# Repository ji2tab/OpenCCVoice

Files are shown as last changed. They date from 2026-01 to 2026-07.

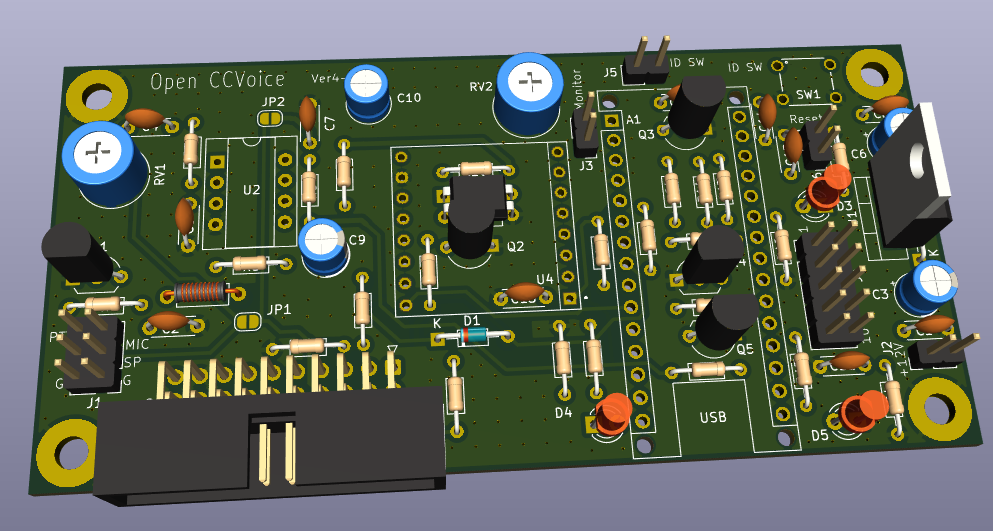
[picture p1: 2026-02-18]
DMR Arduino ID V4-2/完成予定画像Ver4-3.png

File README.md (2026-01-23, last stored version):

# OpenCCVoice Project

[日本語 (Japanese)](#openccvoice-について) | [English](#about-openccvoice)

---

## OpenCCVoice について
OpenCCVoice は、**JA2CCV** 局の設計考案を基礎に、複数局の協力により発展してきたプロジェクトです。
このプロジェクトは、技術を共有し、改善し合い、より良いものへ発展させていくことを目的としています。

### 理念：ブラックボックスにしない、共有の精神
OpenCCVoice はアマチュア無線の精神に基づき、以下の理念を掲げています。

> **「誰でも自由に使え、誰でも改良でき、そしてその成果をオープンに共有できる」**

特定の人だけが技術を抱え込む「ブラックボックス化」を避け、多くの局が改善に参加することで、技術の相互発展を促します。
この理念を象徴するものとして**「OpenCCVoice」**という名称が付けられています。

### ライセンスと権利について
公開予定の回路図、Arduino スケッチ、基板データ、関連ドキュメントの著作権は **JA2CCV 局および OpenCCVoice プロジェクト** に帰属します。

OpenCCVoice は、技術共有と発展を目的としたオープンプロジェクトであり、公開物は **オープンソースライセンス（GPL v3 の理念に準拠）** のもとで取り扱われます。

#### 1. 利用と改変について
* どなたでも **自由に利用** できます。
* 必要に応じて **改変・機能追加・組み込み** が可能です。

#### 2. 再配布・派生物公開の条件（コピーレフト）
改変版や派生物を公開・配布する際は、以下の条件を遵守してください。

1.  **原著作者（JA2CCV／OpenCCVoice）を明示すること**
2.  **改変した点を明記すること**
3.  **派生物も同じくオープンな形で公開すること**
    * ブラックボックス化せず、ソースコード・回路図・基板データ等を公開してください。

#### 3. ライセンス文書について
正式な LICENSE（GPL v3）文書は、回路図・ソフトウェア・基板データ公開時に同梱されます。

OpenCCVoice が多くの局とともに発展していくことを願っています。

### 免責事項 (Disclaimer)
本プロジェクトで公開されているハードウェア設計（回路図・基板データ）、ソフトウェア（ソースコード）、および関連ドキュメントの利用にあたっては、以下の事項をあらかじめご了承ください。

1.  **無保証（No Warranty）**
    本成果物は「現状のまま（As Is）」で提供されます。製作者およびOpenCCVoiceプロジェクトは、特定の目的への適合性、動作の確実性、およびバグや不具合がないことを保証しません。
2.  **損害に対する非責任**
    本成果物の使用、または使用不能によって生じた、いかなる損害（無線機・PC等のハードウェア故障、データの消失、火災、怪我など）についても、製作者およびプロジェクトメンバーは一切の責任を負いません。自作機器の接続は、ご自身の無線機を破損させるリスクがあることを理解した上で行ってください。
3.  **法令の遵守（Legal Compliance）**
    本装置を使用して無線局を運用する場合、利用者は各国の電波法および関連法規（日本国内においては電波法、無線局運用規則など）を遵守する責任を負います。
    * 送信間隔、送出内容、変調レベルなどが法的基準を満たしているか、利用者の責任において確認・調整してください。
    * 本装置の使用による法令違反について、製作者は一切関知しません。
4.  **ライセンス**
    本プロジェクトは **GPL v3 (GNU General Public License v3)** の下で公開されています。再配布や改変に関する条件はライセンス条項に従ってください。

---

## About OpenCCVoice
The OpenCCVoice project is based on the design and concept by **JA2CCV**, and has been developed through the cooperation of multiple stations.
The goal of this project is to share technology, improve upon it together, and foster further development.

### Philosophy: No Black Box, Spirit of Sharing
Based on the spirit of Amateur Radio, OpenCCVoice upholds the following philosophy:

> **"Free to use, free to improve, and results are shared openly."**

We aim to avoid "black boxing"—where technology is hoarded by a few—and instead encourage mutual technological advancement by allowing many stations to participate in improvements.
The name **"OpenCCVoice"** was chosen to symbolize this philosophy.

### License and Rights
The copyright of the schematics, Arduino sketches, PCB data, and related documentation belongs to **JA2CCV and the OpenCCVoice Project**.

OpenCCVoice is an open project aimed at technology sharing and development. All published materials are handled under **Open Source Licenses (compliant with GPL v3 principles)**.

#### 1. Usage and Modification
* Anyone is **free to use** this project.
* You may **modify, add features, or integrate** it as needed.

#### 2. Conditions for Redistribution (Copyleft)
When publishing or distributing modified versions or derivatives, you must observe the following conditions:

1.  **Credit the original authors (JA2CCV / OpenCCVoice).**
2.  **Clearly state the modifications made.**
3.  **Release the derivative works under the same open terms.**
    * Do not "black box" the project; you must publish the source code, schematics, and PCB data.

#### 3. About License Documents
The official LICENSE (GPL v3) document will be included with the release of schematics, software, and PCB data.

We hope that OpenCCVoice will continue to grow together with many stations.

### Disclaimer
Please read the following terms carefully before using the hardware designs (schematics, PCB data), software (source code), and documentation provided by the OpenCCVoice project.

1.  **No Warranty**
    This project is provided "AS IS", without warranty of any kind, express or implied, including but not limited to the warranties of merchantability or fitness for a particular purpose. The entire risk as to the quality and performance of the project is with you.
2.  **Limitation of Liability**
    In no event shall the authors or copyright holders be liable for any claim, damages, or other liability, whether in an action of contract, tort, or otherwise, arising from, out of, or in connection with the software/hardware or the use or other dealings in the project.
    * **Hardware Risk:** Connecting custom circuits to your radio equipment carries inherent risks. You assume full responsibility for any damage to your transceiver, computer, or other devices.
3.  **Regulatory Compliance**
    Users are solely responsible for complying with the radio laws and regulations of their respective countries or regions.
    * It is the user's responsibility to ensure that transmission intervals, audio levels, and operation methods comply with local legal requirements.
    * The authors assume no responsibility for any legal violations committed by the user.
4.  **License**
    This project is released under the **GNU General Public License v3 (GPL v3)**. Please refer to the license for terms regarding redistribution and modification.

---
**Project Contributors:** JA2CCV, JA9HYM, JA2DML, JG1XWV, JI2TAB

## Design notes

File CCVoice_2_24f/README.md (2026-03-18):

# OpenCCVoice Guidance Controller

**バージョン: v2.24f**
対象基板: **Ver.5**
対象MCU: Arduino Nano (ATmega328P, 5V)

---

## 概要

OpenCCVoice は DMR 無線機のレピータ向け ID 送出支援コントローラです。
DFPlayer Mini による音声ファイル再生、DS3231 RTC による正時アライン、
AT24C32 による設定の二重保存・イベントログ記録に対応しています。

---

## ファイル構成

```
CCVoice_2_24f/
  ├── CCVoice_2_24f.ino    メインスケッチ（必須）
  ├── ccvoice_log.h       イベントログ関連（必須）
  └── ccvoice_config.h    設定マイグレーション関連（必須）
```

> **3ファイルを同一フォルダに置いて** Arduino IDE で `CCVoice_2_24f.ino` を開いてください。

---

## Ver.5 ピンマップ

| Pin | 機能 | 備考 |
|-----|---|---|
| D2  | テストSW | 1〜3クリックで TRACK 1〜3 手動送出 |
| D3  | DFP BUSYミラー出力 | 再生中=HIGH（反転） |
| D4  | ModBusy LED | BUSY 表示 |
| D5  | PTT 出力 | HIGH=送信 |
| D6  | 抑止 LED | 抑止/バースト/POST-TX 表示 |
| D7  | A0検知 LED | A0 BUSY 表示 |
| D10 | DFPlayer BUSY 入力 | LOW=再生中（INPUT_PULLUP） |
| D11 | TM BUSY 入力 | 極性切替可（g0/g1）、INPUT_PULLUP |
| D12 | Arduino RX ← DFPlayer TX | SoftwareSerial 9600bps |
| D13 | Arduino TX → DFPlayer RX | SoftwareSerial 9600bps |
| A0  | アナログ入力 | ヒステリシス＋保持適用 |
| A4  | I²C SDA | DS3231 + AT24C32 |
| A5  | I²C SCL | DS3231 + AT24C32 |

---

## コマンド一覧（シリアル 115200bps 8N1 / 改行なし or LF）

| コマンド | 説明 | 既定値 |
|---|---|---|
| `m0/m1/m2` | BUSY検知ソース: Digital/A0/AUTO | AUTO |
| `n####` | BUSY最小時間 (ms) | 500 |
| `b####` | BUSY最大時間（長話抑止）(ms) | 3900 |
| `i####` | IDLE最小時間 (ms) | 200 |
| `s0/s1` | 抑止機能 OFF/ON | ON |
| `t0/t1` | 送信後抑止 OFF/ON | ON |
| `r####` | 送信後抑止時間 (ms) | 3000 |
| `p##` | 定周期送出間隔（分、0=停止） | 30 |
| `k####` | 周期ID静寂ガード (ms) | 2000 |
| `L###` | A0低閾値 | 300 |
| `G###` | A0高閾値 | 700 |
| `a####` | A0保持時間 (ms) | 800 |
| `w##` | AUTO判定ウィンドウ（分） | 30 |
| `d####` | DFPlayer タイムアウト (ms、0=無効) | 20000 |
| `g0/g1` | TM BUSY 極性: LOW/HIGH | HIGH |
| `u0/u1` | RTCアライン OFF/ON | ON |
| `TYYYYMMDDHHmmss` | RTC時刻設定（例: T20260311143000） | — |
| `v` | イベントログ表示（直近20件） | — |
| `v0` | イベントログ消去 | — |
| `V` | バージョン表示（スケッチver + EEPROM_VER） | — |
| `Z` | ソフトウェアリセット（WDT、EEPROM変更なし） | — |
| `q` | 現在設定・時刻の一覧表示 | — |
| `h` | ヘルプ表示 | — |
| `H` | 詳細ヘルプ表示 | — |
| `x` | STOP（送出停止） | — |
| `R` | STOP解除（送出再開） | — |
| `F` | Factory Reset（EEPROM初期化） | — |
| `0〜3` | テスト送出（TRACK 0〜3） | — |

---

## 起動時シリアル出力例

```
[START] OpenCCVoice v2.24f (Event Log, Dual EEPROM, RTC-Aligned Periodic, Ver.5 pinmap)
[RTC] DS3231 found.
[EEPROM] AT24C32 found. Using external EEPROM.
[CFG] EEPROM_VER=6 SRC=AUTO MIN=500 MAX=3900 PER(min)=30 RTC_ALIGN=ON
[RTC] 2026/03/12 09:00:00  Align=ON(RTC)
```

---

## 音声ファイル

詳細は `AUDIO_FILES_GUIDE.md` を参照してください。

| トラック | ファイル名 | 用途 |
|---|---|---|
| 1 | `001.mp3` | カーチャンク ID |
| 2 | `002.mp3` | 定周期 ID（奇数回） |
| 3 | `003.mp3` | 定周期 ID（偶数回） |

> **001〜003 の3ファイルを必ず用意してください。**
> 詳細は `AUDIO_FILES_GUIDE.md` を参照。

---

## DS3231 接続

詳細は `DS3231_CONNECTION_GUIDE.md` を参照してください。

- J5 コネクタ（SDA/SCL/VCC/GND）に接続
- I²C アドレス: DS3231=0x68、AT24C32=0x57
- 未接続時は millis() 相対動作にフォールバック

> DS3231 のコイン電池（CR2032）が切れると時刻が `2000/01/01` 付近にリセットされます。
> `q` コマンドで確認し、`T` コマンドで再設定してください。

---

## 関連ドキュメント

| ファイル | 内容 |
|---|---|
| `CHANGELOG.md` | バージョン変更履歴 |
| `NOTES_FOR_UPGRADE.md` | アップグレード手順 |
| `SPECIFICATION.md` | 詳細仕様書 |
| `DS3231_CONNECTION_GUIDE.md` | DS3231 接続ガイド |
| `AUDIO_FILES_GUIDE.md` | 音声ファイルガイド |
| `README_PROJECT.md` | プロジェクト概要・ライセンス |
| `Schematic_Ver5.pdf` | 回路図（Ver.5） |
| `PCB_Layout_Ver5.pdf` | 部品配置図（Ver.5） |

---

**Project Contributors:** JA2CCV, JA9HYM, JA2DML, JG1XWV, JI2TAB

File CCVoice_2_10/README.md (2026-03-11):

# OpenCCVoice Guidance Controller

取扱説明書 / コマンドリファレンス  
**バージョン: v2.10 — DS3231 RTC 正時アライン対応版**  
**最終更新日: 2026/03/11**  
対象ハード: Arduino Nano (ATmega328P / 5V) **基板 Ver.5**  
通信設定: 115200 bps / 8N1 / 改行なし（またはLF）

---

## ■ 概要

本機は DMR 無線機の ID 送出を自動制御するコントローラです。  
PC と USB 接続し、シリアルモニタから各種コマンドで設定を変更できます。

全ての設定は EEPROM に自動保存され、電源断でも保持されます。  
**v2.10 は DS3231 RTC モジュールに対応し、周期IDを毎正時アライン方式で送出できます。**

---

## ■ v2.10 の特徴・変更点

### 【DS3231 RTC モジュール対応】

基板上の **J5 コネクタ**（SDA/SCL/VCC/GND）に DS3231+AT24C32 一体型モジュールを接続するだけで動作します。

- **未接続・故障時は自動的に millis() 相対動作へフォールバック**（v2.01 互換）
- 起動時に接続確認ログを表示

### 【正時アライン周期ID】

`p##` の値が **60の約数**（10/15/20/30 など）かつ DS3231 接続時、  
**毎正時を基準とした等間隔タイミング**で周期IDを送出します。

| 設定 | 送出タイミング |
|---|---|
| `p10` | 毎時 :00/:10/:20/:30/:40/:50 |
| `p15` | 毎時 :00/:15/:30/:45 |
| `p30` | 毎時 :00/:30 |
| `p60` | 毎時 :00 |

60の約数でない値（例：`p7`）は従来の millis() 相対動作になります。

1分ごとに DS3231 から時刻を再取得し、長期ドリフトを自動補正します。

### 【新コマンド】

| コマンド | 説明 |
|---|---|
| `TYYYYMMDDHHmmss` | RTC 時刻設定（例：`T20260311143000`） |
| `u1` | RTCアライン有効（既定） |
| `u0` | RTCアライン無効（millis() 相対に切替） |

### 【`q` に RTC 時刻表示を追加】

```
[RTC] 2026/03/11 14:23:45  Align=ON(RTC)
[CFG] EEPROM_VER=5 SRC=DIGITAL(LOCK) MIN=500 MAX=3900 PER(min)=15 ...
```

### 【EEPROM バージョン更新（ver=5）】

v2.01（ver=4）からの更新時、既存設定を引き継いで自動マイグレーションします。

### 【v2.01 の全機能を継承】
- 送信直後ガード（postTxIgnore）
- 周期ID catch-up 対策
- 抑止中も A0 BUSY 観測継続
- 周期ID 静寂ガード（`k####`）
- DFPlayer フェイルセーフ（`d####`）
- TM BUSY 極性切替（`g0/g1`）
- AUTO 判定（`m2`）

---

## ■ ハードウェア接続

### DS3231 モジュールの接続（J5コネクタ）

| DS3231 モジュール | J5 ピン | Arduino Nano |
|---|---|---|
| SLC (SCL) | 1 | A5 |
| SDA | 2 | A4 |
| VCC | 3 | +5V |
| GND | 4 | GND |

> PTT（D5）、ModBusy LED（D4）、A0（A0）等は変更なし。  
> 詳細は回路図（Schematic_Ver5.pdf）および部品配置図（PCB_Layout_Ver5.pdf）を参照。

### ピンマップ（Ver.5 基板）

| ピン | 機能 | 方向 |
|---|---|---|
| D2 | テストSW | 入力（INPUT_PULLUP） |
| D3 | DFP BUSYミラー出力（再生中=HIGH） | 出力 |
| D4 | ModBusy LED | 出力 |
| D5 | PTT（HIGH=送信） | 出力 |
| D6 | 抑止 LED | 出力 |
| D7 | A0検知 LED | 出力 |
| D10 | DFPlayer BUSY入力（LOW=再生中） | 入力（INPUT_PULLUP） |
| D11 | TM BUSY入力（Digital入力） | 入力（INPUT_PULLUP） |
| D12 | Arduino TX → DFPlayer RX | SoftwareSerial |
| D13 | Arduino RX ← DFPlayer TX | SoftwareSerial |
| A0 | アナログBUSY入力 | 入力 |
| A4 | I²C SDA（DS3231） | I²C |
| A5 | I²C SCL（DS3231） | I²C |

---

## ■ クイック・コマンド一覧

| コマンド | パラメータ | 既定値 | 説明 |
|---|---|---|---|
| `m` | 0/1/2 | 0 | DIGITAL固定 / A0固定 / AUTO判定 |
| `b` | 500〜 | 3900 | 最大受信長 (ms) |
| `n` | 100〜 | 500 | 最小受信長 (ms) |
| `i` | 0〜 | 200 | 直前アイドル時間 (ms) |
| `s` | 0/1 | 1 | 抑止 ON/OFF |
| `t` | 0/1 | 1 | 送信後無視 ON/OFF（s1時） |
| `r` | 0〜 | 3000 | 送信後無視時間 (ms) |
| `p` | 0〜 | 30 | 周期ID（分）※0=停止、60の約数→正時アライン |
| `k` | 0〜600000 | 2000 | 周期ID静寂時間 (ms) |
| `w` | 1〜 | 30 | AUTO観測時間（分） |
| `L` | 0〜1023 | 300 | A0閾値LOW |
| `G` | 0〜1023 | 700 | A0閾値HIGH |
| `a` | 0〜 | 800 | A0保持時間 (ms) |
| `d` | 0〜 | 20000 | DFPフェイルセーフ (ms) ※0=無効 |
| `g` | 0/1 | 1 | TM BUSY極性（LOW/HIGH=busy） |
| `u` | 0/1 | 1 | RTCアライン OFF/ON |
| `T` | YYYYMMDDHHmmss | — | RTC時刻設定（例：T20260311143000） |
| `q` | — | — | 設定一覧＋現在RTC時刻 |
| `H` | — | — | 汎用プリセット（s0/t0/b3900） |
| `x` | — | — | Safe Stop（全機能停止） |
| `R` | — | — | 停止状態から復帰（**大文字**） |
| `F` | — | — | Factory Reset（EEPROM初期化） |
| `0〜3` | — | — | ログレベル |
| `h` | — | — | コマンド一覧 |

---

## ■ 初回セットアップ手順（v2.10）

```
1. Ver.5 基板に v2.10 を書き込む
2. J5 コネクタに DS3231 モジュールを接続
3. シリアルモニタ（115200bps）を開く
4. 起動ログで [RTC] DS3231 found. を確認
5. T20260311143000 → 現在時刻を設定（14桁）
6. p15（または p10/p30）で周期を設定
7. q で確認 → Align=ON(RTC) が出れば正時アライン動作中
8. TM BUSY 極性を確認（g0/g1）
9. テストSW（D2）1クリック → Track 1 再生確認
```

---

## ■ v2.01 からのアップグレード

### EEPROM の互換性

v2.10 の EEPROM レイアウト（ver=5）は v2.01（ver=4）から **`rtcAlignOn` フィールドを追加**しています。  
書き込み後の初回起動時に自動マイグレーションが行われ、既存設定はすべて引き継がれます。

- `F`（初期化）は**不要**です。
- 起動ログに `[EEPROM] Settings Loaded.` が出れば正常です。

### コマンドの変更

v2.01 から v2.10 への**コマンド変更はありません**。新コマンド（`T` / `u0/u1`）が追加されたのみです。

---

## ■ DS3231 について

DS3231 は高精度 RTC（リアルタイムクロック）チップです。コイン電池（CR2032）でバックアップされ、電源断中も時刻を保持し続けます。**時刻の自動取得機能はない**ため、初回および電池交換後に `T` コマンドで時刻を設定する必要があります。

AT24C32（モジュール上の外部 EEPROM）は本バージョンでは未使用です。

---

## ■ LED 表示の意味

| LED | ピン | 点灯条件 |
|-----|---|---|
| ModBusy LED | D4 | BUSY 受信中（readBusy()=true） |
| 抑止 LED | D6 | 抑止中（長話/バースト/POST-TX） |
| A0検知 LED | D7 | A0 BUSY 検知中 |
| DFP BUSYミラー | D3 | DFPlayer 再生中（HIGH） |

---

## ■ フェイルセーフ（DFPlayer BUSY 異常）

DFPlayer BUSY が戻らない場合、**d#### ms 経過後に強制 PTT OFF**。

- 既定：d20000（20秒）
- d0：無効

---

## ■ トラブルシューティング

**● IDが出ない**
- 停止中（x）→ `R`（大文字）で復帰
- 長話（b3900超）→ 抑止中
- D6 LED 点灯中（抑止）では動作しない

**● 周期IDが正時にずれる**
- `q` で `Align=ON(RTC)` が出ているか確認
- DS3231 未接続の場合 `Align=OFF(millis)` になる
- `T` コマンドで時刻を再設定

**● DS3231 が認識されない**
- J5 コネクタの SDA/SCL/VCC/GND の配線を確認
- `q` で `N/A(no RTC)` が出る場合は未接続または故障

**● STOP 後に復帰できない**
- `R`（大文字）を入力。`r`（小文字）では復帰しない。

**● BUSY判定が逆**
- g0/g1 の設定確認（`q` で現在の極性を表示）

---

## ■ 配線メモ（v2.10 / Ver.5 基板）

```
DFPlayer TX → D13（Arduino RX）
DFPlayer RX ← D12（Arduino TX）
DFPlayer BUSY（LOW=再生中）→ D10
D10 BUSYミラー（反転）→ D3
TM BUSY → D11（g0/g1 で極性指定）
PTT → D5（HIGH=送信）
ModBusy LED → D4
抑止 LED → D6
A0検知 LED → D7
テストSW → D2（INPUT_PULLUP）
アナログBUSY → A0
DS3231 SDA → A4
DS3231 SCL → A5
```

---

## ■ 重要仕様（抜粋）

**【RESUME コマンド】**  
STOP 中の復帰は **`R`（大文字）** です。`r`（小文字）は送信後抑止時間設定コマンドです。

**【周期ID 正時アライン（p## / u0/u1）】**  
DS3231 接続かつ `p##` が60の約数のとき、毎正時基準で等間隔送出。  
1分ごとにドリフト補正。`q` で `Align=ON(RTC)` / `Align=OFF(millis)` を確認可能。

**【周期ID 静寂ガード（k####）】**  
BUSY OFF → k#### ms 静寂で周期ID 許可。BUSY中・静寂不足・抑止期間中は延期。

**【EEPROM バージョン（CONFIG_VERSION=5）】**  
v2.01（ver=4）からの更新時、自動マイグレーションが働き設定を引き継ぎます。

---

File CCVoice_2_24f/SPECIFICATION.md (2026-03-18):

**===== 仕様書（技術者向け） OpenCCVoice Guidance Controller v2.24f =====**

1. 基本情報
- 名称      : OpenCCVoice Guidance Controller
- バージョン : v2.24f — V/Z コマンド追加版
- MCU       : Arduino Nano（ATmega328P, 5V）
- 対象基板  : Ver.5
- 依存      : Arduino.h / SoftwareSerial.h / EEPROM.h / Wire.h / avr/wdt.h
- DFPlayer  : BUSY監視（D10=LOW 再生中）、9600bps 制御（SoftwareSerial D12/D13）
- DS3231    : I²C（A4=SDA, A5=SCL）、レジスタ直接アクセス（外部ライブラリ不要）
- EEPROM    : CONFIG_VERSION=6（v2.10=5 から saveTimestamp フィールドを追加）
               → v2.10 / v2.01 設定を引き継ぎ可能
- AT24C32   : 外部EEPROM（I²C 0x57）/ 内蔵EEPROMと二重保存（v2.20追加）

**===== 2. ピンアサイン（Ver.5） =====**

 Pin  | 定数名              | 方向   | 信号                          | 備考
------|---------------------|--------|-------------------------------|----------------------------
 D2   | PIN_TEST_SW         | 入力   | テストSW                      | INPUT_PULLUP、LOW=押下
 D3   | PIN_DFP_OUT         | 出力   | DFPlayer BUSYミラー           | 再生中=HIGH（反転出力）
 D4   | PIN_BUSY_LED        | 出力   | ModBusy LED                   | HIGH=点灯
 D5   | PIN_PTT             | 出力   | PTT                           | HIGH=送信
 D6   | PIN_SUP_LED         | 出力   | 抑止 LED                      | HIGH=点灯（抑止中）
 D7   | PIN_A0_LED          | 出力   | A0検知 LED                    | HIGH=点灯（a0Busy時）
 D10  | PIN_DFP_BSY         | 入力   | DFPlayer BUSY入力             | INPUT_PULLUP、LOW=再生中
 D11  | PIN_TM_BUSY         | 入力   | TM BUSY入力（Digital入力）    | INPUT_PULLUP、極性g0/g1
 D13  | ARD_TX_TO_DFP       | 出力   | Arduino TX → DFPlayer RX     | SoftwareSerial 9600bps ★v2.23修正
 D12  | ARD_RX_FROM_DFP     | 入力   | Arduino RX ← DFPlayer TX     | SoftwareSerial 9600bps ★v2.23修正
 A0   | A0_PIN              | 入力   | アナログBUSY                  | 0〜1023、ヒステリシス＋保持
 A4   | —（Wire固定）        | I²C    | DS3231 SDA                    | Wire.h使用（v2.10追加）
 A5   | —（Wire固定）        | I²C    | DS3231 SCL                    | Wire.h使用（v2.10追加）

**===== 3. 機能仕様（Functional） =====**

(1) 短発受信の自動ID送出（v2.01から変更なし）
  - TM BUSY（D11）または A0 の受信継続時間 dur が
      BUSY_MIN_MS ≤ dur < BUSY_MAX_MS のとき、Track 1（001）を送出。
  - PTT シーケンス：PRE=1000ms → 再生 → POST=1000ms。

(2) 抑止（長話・バースト・送信後）（v2.01から変更なし）
  - 長話抑止      : dur ≥ BUSY_MAX_MS → LONG_SUP_MS=10s
  - バースト抑止  : 10秒窓内で短発が2回以上 → BURST_SUP_MS=10s
  - 送信後抑止    : t1有効時、TX後 TX_SUP_MS(ms) の受信を無視
  - 送信直後ガード: PTT OFF 直後、BUSYが idleMin 連続OFF まで全発火禁止

(3) AUTO（m2）（v2.01から変更なし）
  - AUTO_WINDOW（分）観測し、Digital/A0 の優位側へ自動固定。

(4) 周期ID（v2.10で正時アライン機能を追加）
  【RTCアライン動作（DS3231接続 かつ p## が60の約数 かつ u1）】
  - PERIOD_MS ごとに Track 2/3 を交互送出。
  - 次回発火時刻 = 「現在時刻から次の正時アライン境界まで」を DS3231 から計算。
  - 発火後、即座に次回時刻を再計算（recalcPeriodicAlign）。
  - 1分ごとに DS3231 から時刻を再取得してドリフト補正（RTC_RESYNC_INTERVAL=60s）。
  - 送出条件（全て満たすこと）：
    1) periodicDue=true（nextPeriodicAt を超過）
    2) state==IDLE
    3) readBusy()==false
    4) BUSY が OFFになってから periodQuietMs(ms) 以上静寂
    5) 抑止中でない（長話/バースト/送信後ガード）
  - BUSY中・静寂不足・抑止期間中は送出せず延期（periodicDue 保持）。

  【millis()相対動作（DS3231未接続 / 60の約数でない / u0）】
  - v2.01 互換の catch-up 方式。
  - nextPeriodicAt += PERIOD_MS で追い付かせ、最大1回分のみ発火。

  【切替判定ロジック】
  - isAlignablePeriod(pMin): 60 % pMin == 0 かつ 0 < pMin ≤ 60 → true
  - rtcAvailable && RTC_ALIGN_ON && isAlignablePeriod → rtcAlignActive=true

(5) DS3231 RTC 管理（v2.10新規）
  - Wire.h を使用、外部ライブラリ不要。
  - 起動時に rtcProbe() で I²C 疎通確認（アドレス 0x68）。
  - rtcRead()  : 7バイト読み取り、BCD→DEC変換、RtcTime 構造体に格納。
  - rtcWrite() : RtcTime 構造体からBCD変換して書き込み。
  - DS3231 未応答時は rtcAvailable=false → millis() 相対にフォールバック。

(6) EEPROM 永続化（v2.10で rtcAlignOn を追加）
  - 変更コマンド（m/n/b/i/p/r/L/G/a/w/s/t/d/g/k/u）で即保存。
  - CONFIG_VERSION=5 / v2.01（ver=4）から自動マイグレーション。

(7) LED表示 / D3ミラー出力（v2.01から変更なし）

(8) フェイルセーフ（PTT張り付き防止）（v2.01から変更なし）

(9) テストSW（D2）（v2.01から変更なし）
  - 1〜3クリック → Track 1〜3 再生

**===== 4. 非機能仕様（Non-Functional） =====**
（v2.01から変更なし）
- 応答性 : TM BUSY デバウンス 5ms
- 安定性 : DFPlayer BUSY の HIGH確定に 40ms
- ガード : PTT 最低 ON ガード搭載
- 可搬性 : Arduino IDE 1.8.x / 2.x
- 保守性 : printSummary() による状態一覧（RTC時刻・アライン状態含む）
- 安全性 : DFPlayer タイムアウト監視 / PTT張り付き防止
- 耐久性 : EEPROM 書込みは「値変更時のみ」

**===== 5. インタフェース仕様（I/O 詳細） =====**

【入力】
- D2  (INPUT_PULLUP) : テストSW。LOW=押下。
- D10 (INPUT_PULLUP) : DFPlayer BUSY。LOW=再生中。
- D11 (INPUT_PULLUP) : TM BUSY。g0: LOW=busy / g1: HIGH=busy（既定）。
- A0                 : アナログBUSY（0〜1023 / 基準VCC=5V）。
- A4                 : I²C SDA（DS3231）。Wire.h が管理。
- A5                 : I²C SCL（DS3231）。Wire.h が管理。

【出力】
- D3  : DFPlayer BUSY ミラー（反転）。再生中=HIGH。
- D4  : ModBusy LED。
- D5  : PTT。送信中 HIGH。
- D6  : 抑止 LED。
- D7  : A0検知 LED。

【SoftwareSerial（DFPlayer通信）】
- D12 (TX) / D13 (RX) : 9600bps TTLレベル（5V）。

**===== 6. 既定値（Factory Defaults） =====**
（v2.01から変更なし、rtcAlignOn=1 を追加）
- BUSY_INPUT_SOURCE           = DIGITAL（D11）
- BUSY_MIN_MS                 = 500
- BUSY_MAX_MS                 = 3900
- IDLE_MIN_MS                 = 200
- PERIOD_MS                   = 30 min
- TX_SUP_MS                   = 3000
- SUPPRESSORS_ENABLED         = true
- TX_AFTER_SUPPRESS_ENABLED   = true
- A0_LOW_TH                   = 300
- A0_HIGH_TH                  = 700
- A0_HOLD                     = 800
- AUTO_WINDOW                 = 30 min
- DFP_TIMEOUT_MS              = 20000ms
- TM_BUSY_ACTIVE_HIGH         = true（HIGH=busy）
- periodQuietMs               = 2000ms
- RTC_ALIGN_ON                = true（ON）
- EEPROM_VER                  = 6（CONFIG_VERSION=6）

**===== 7. コマンド仕様（完全） =====**
- m0 / m1 / m2         … BUSYソース切替（DIGITAL / A0 / AUTO）
- n####                … 最小受信長（ms）
- b####                … 最大受信長（ms）
- i####                … 直前アイドル時間（ms）
- s0 / s1              … 抑止 OFF / ON
- t0 / t1              … 送信後抑止 OFF / ON
- r####                … TX後無視時間（ms）
- p##                  … 周期ID（分 / 0=停止）※60の約数→正時アライン
- k####                … 周期ID静寂時間（ms）
- w##                  … AUTO観測窓（分）
- L### / G### / a####  … A0 閾値LOW/HIGH/保持(ms)
- d####                … DFPlayerタイムアウト（ms / 0=無効）
- g0 / g1              … TM BUSY極性（LOW=busy / HIGH=busy）
- u0 / u1              … RTCアライン OFF / ON（v2.10追加）
- v                    … ログ表示（直近20件）（v2.21追加）
- v0                   … ログ消去（v2.21追加）
- V                    … バージョン表示（スケッチver + EEPROM_VER）（v2.24f追加）
- Z                    … ソフトウェアリセット（WDT 15ms / EEPROM変更なし）（v2.24f追加）
- TYYYYMMDDHHmmss      … RTC時刻設定（v2.10追加）例: T20260311143000
- q                    … 要約（RTC時刻・アライン状態含む）
- H                    … 汎用プリセット（s0/t0/b3900）
- x                    … 停止（Safe Stop）
- R                    … 再開（STOP中のみ有効。大文字）
- F                    … Factory Reset（初期化＋保存）
- 0 / 1 / 2 / 3        … ログレベル（NONE / ERR / INF / DBG）
- h                    … ヘルプ表示

**===== 8. 振る舞い仕様（状態遷移 / BUSY判定） =====**
（v2.01から変更なし。周期IDスケジューラのみ追記）

【周期ID（RTCアライン動作）】
- isAlignablePeriod(pMin) = true かつ rtcAvailable かつ RTC_ALIGN_ON
  → rtcAlignActive=true
- nextPeriodicAt = calcNextAlignedAt(t, pMin, now)
  = now + ((periodSec - totalSec % periodSec) % periodSec) * 1000
  ※ slotSec==0（ちょうど境界）の場合は次の周期に設定
- 発火後: recalcPeriodicAlign(now) で即座に次回時刻を再計算
- 1分ごと: rtcResyncMs 到達で recalcPeriodicAlign(now) を再実行（ドリフト補正）

【周期ID（millis()相対動作）】
- rtcAlignActive=false の場合
- v2.01 互換 catch-up: while(now >= nextPeriodicAt) nextPeriodicAt += PERIOD_MS

**===== 9. EEPROM 仕様 =====**

【レイアウト（CONFIG_VERSION=6 / v2.24f）】

 フィールド名        | 型       | コマンド | 説明
---------------------|----------|----------|-------------------------
 magic               | uint32_t | 自動     | 識別子 0xDEADBEEF
 busySrc             | uint8_t  | m        | 0=DIGITAL, 1=A0, 2=AUTO
 suppressOn          | uint8_t  | s        | 0=OFF, 1=ON
 txAfSupOn           | uint8_t  | t        | 0=OFF, 1=ON
 busyMin             | uint32_t | n        | ms
 busyMax             | uint32_t | b        | ms
 idleMin             | uint32_t | i        | ms
 periodMin           | uint32_t | p        | 分
 txSupMs             | uint32_t | r        | ms
 a0Low               | int      | L        | 0〜1023
 a0High              | int      | G        | 0〜1023
 a0Hold              | uint32_t | a        | ms
 autoWinMin          | uint32_t | w        | 分
 dfpTimeoutMs        | uint32_t | d        | ms
 tmBusyActiveHigh    | uint8_t  | g        | 0=LOW=busy, 1=HIGH=busy
 periodQuietMs       | uint32_t | k        | ms
 rtcAlignOn          | uint8_t  | u        | 0=OFF, 1=ON（v2.10追加）
 saveTimestamp       | uint32_t | 自動     | 保存時刻（秒換算）v2.20追加
 ver                 | uint8_t  | 自動     | レイアウト版（現在=6）

【バージョン不一致時の自動補完値】
- v2.01→v2.20: rtcAlignOn=1（ON）、saveTimestamp=0
- v2.10→v2.20: saveTimestamp=0

**===== 10. 制約 =====**
- TM BUSY デバウンス 5ms（固定）
- A0 と Digital（D11）の同時配線は禁止
- EEPROM 書込みは「値変更時のみ」（耐久性考慮）
- SRAM：ATmega328P の 2KB 内で動作
- D13 は SoftwareSerial（RX）兼用のため、外部回路との競合に注意
- A4/A5 は Wire.h が占有するため他用途不可
- DS3231 の T コマンドは秒単位の精度（手打ちのため数秒の誤差は許容）
- AT24C32 未接続中に設定変更した場合、次回モジュール接続時に不一致警告が出る
- AT24C32 のページ書き込み完了待ち 10ms（最大5msに対して余裕あり）
- PTT 出力中に Z を実行すると WDT ハードリセットにより PTT が即解放される

**===== 11. 試験（例） =====**
（v2.01の試験項目に加えて以下を追加）

- RTC正時アライン：p15 設定、DS3231接続
  → q で Align=ON(RTC) を確認
  → 毎時 :00/:15/:30/:45 に周期ID 送出確認

- RTCフォールバック：DS3231 未接続で p15
  → q で Align=OFF(millis) を確認
  → millis() 相対で15分ごとに送出

- 時刻設定：T20260311143000
  → q で 2026/03/11 14:30:xx が表示されること

- RTCアライン OFF：u0
  → q で RTC_ALIGN=OFF、Align=OFF(millis) を確認

- EEPROM マイグレーション：v2.01（ver=4）から書き込み
  → 起動ログに Migration done. が出て既存設定を引き継ぐこと
  → q で EEPROM_VER=5 を確認

**===== 12. リスク =====**
（v2.01のリスクに加えて以下を追加）
- DS3231 のコイン電池切れ → 時刻リセット。電池交換後に T コマンドで再設定が必要。
- T コマンドの手打ちによる秒単位の誤差（許容範囲内）
- I²C バス上に AT24C32（0x57）が存在するが、本プログラムはアクセスしないため競合なし
- A4/A5 を他用途に使用している旧設計との非互換

**===== 13. 変更履歴 =====**
- 詳細は CHANGELOG.md を参照

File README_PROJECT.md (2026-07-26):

# OpenCCVoice Project

[日本語 (Japanese)](#openccvoice-について) | [English](#about-openccvoice)

---

## OpenCCVoice について
OpenCCVoice は、**JA2CCV** 局の設計考案を基礎に、複数局の協力により発展してきたプロジェクトです。
このプロジェクトは、技術を共有し、改善し合い、より良いものへ発展させていくことを目的としています。

### 理念：ブラックボックスにしない、共有の精神
OpenCCVoice はアマチュア無線の精神に基づき、以下の理念を掲げています。

> **「誰でも自由に使え、誰でも改良でき、そしてその成果をオープンに共有できる」**

特定の人だけが技術を抱え込む「ブラックボックス化」を避け、多くの局が改善に参加することで、技術の相互発展を促します。
この理念を象徴するものとして**「OpenCCVoice」**という名称が付けられています。

---

## 基板バージョンとファームウェアの対応

> ⚠️ **基板 Ver.4 と Ver.5 ではピンアサインが異なります。**
> **必ず使用する基板バージョンに対応したファームウェア（スケッチ）を使用してください。**

| 基板バージョン | 対応ファームウェア | 状態 |
|---|---|---|
| Ver.4 | v1.73e 以前（**1系**） | 旧バージョン |
| **Ver.5** | **v2.01 以降（2系）** | **現行・推奨** |

### Ver.4 と Ver.5 のピンアサイン比較

| 信号 | Ver.4（1系） | **Ver.5（2系）** |
|---|---|---|
| テストSW | D3 | **D2** |
| DFPlayer BUSYミラー出力 | D2 | **D3** |
| ModBusy LED | D4 | D4（変更なし） |
| PTT出力 | D5 | D5（変更なし） |
| 抑止 LED | D13 | **D6** |
| A0検知 LED | D12 | **D7** |
| DFPlayer BUSY入力 | D7 | **D10** |
| TM BUSY入力（Digital入力） | D6 | **D11** |
| Arduino TX → DFPlayer RX | D11 | **D13** |
| Arduino RX ← DFPlayer TX | D10 | **D12** |
| アナログBUSY | A0 | A0（変更なし） |
| I²C SDA（DS3231/AT24C32） | 未使用 | **A4**（v2.10追加） |
| I²C SCL（DS3231/AT24C32） | 未使用 | **A5**（v2.10追加） |

> **注意:** Ver.5 基板に 1系ファームウェアを書き込むと、ピンアサインの不一致により正常動作しません。逆も同様です。

### ライセンスと権利について
公開予定の回路図、Arduino スケッチ、基板データ、関連ドキュメントの著作権は **JA2CCV 局および OpenCCVoice プロジェクト** に帰属します。

OpenCCVoice は、技術共有と発展を目的としたオープンプロジェクトであり、公開物はファイルの種類に応じて次のライセンスのもとで取り扱われます。**ハードウェア（回路図・基板データ・BOM・ケース）は CERN-OHL-S v2**、**ソフトウェア（Arduino スケッチ）は GPL v3** です。

#### 1. 利用と改変について
* どなたでも **自由に利用** できます。
* 必要に応じて **改変・機能追加・組み込み** が可能です。

#### 2. 再配布・派生物公開の条件（コピーレフト）
改変版や派生物を公開・配布する際は、以下の条件を遵守してください。

1.  **原著作者（JA2CCV／OpenCCVoice）を明示すること**
2.  **改変した点を明記すること**
3.  **派生物も同じくオープンな形で公開すること**
    * ブラックボックス化せず、ソースコード・回路図・基板データ等を公開してください。

#### 3. ライセンス文書について
正式なライセンス文書はリポジトリに同梱されています。ハードウェアは `LICENSE-HARDWARE.txt`（CERN-OHL-S v2）、ソフトウェアは `LICENSE`（GPL v3）を参照してください。

OpenCCVoice が多くの局とともに発展していくことを願っています。

### 免責事項 (Disclaimer)
本プロジェクトで公開されているハードウェア設計（回路図・基板データ）、ソフトウェア（ソースコード）、および関連ドキュメントの利用にあたっては、以下の事項をあらかじめご了承ください。

1.  **無保証（No Warranty）**
    本成果物は「現状のまま（As Is）」で提供されます。製作者およびOpenCCVoiceプロジェクトは、特定の目的への適合性、動作の確実性、およびバグや不具合がないことを保証しません。
2.  **損害に対する非責任**
    本成果物の使用、または使用不能によって生じた、いかなる損害（無線機・PC等のハードウェア故障、データの消失、火災、怪我など）についても、製作者およびプロジェクトメンバーは一切の責任を負いません。自作機器の接続は、ご自身の無線機を破損させるリスクがあることを理解した上で行ってください。
3.  **法令の遵守（Legal Compliance）**
    本装置を使用して無線局を運用する場合、利用者は各国の電波法および関連法規（日本国内においては電波法、無線局運用規則など）を遵守する責任を負います。
    * 送信間隔、送出内容、変調レベルなどが法的基準を満たしているか、利用者の責任において確認・調整してください。
    * 本装置の使用による法令違反について、製作者は一切関知しません。
4.  **ライセンス**
    本プロジェクトのハードウェアは **CERN-OHL-S v2 (CERN Open Hardware Licence Version 2 - Strongly Reciprocal)**、ソフトウェアは **GPL v3 (GNU General Public License v3)** の下で公開されています。再配布や改変に関する条件は、それぞれのライセンス条項に従ってください。

---

## About OpenCCVoice
The OpenCCVoice project is based on the design and concept by **JA2CCV**, and has been developed through the cooperation of multiple stations.
The goal of this project is to share technology, improve upon it together, and foster further development.

### Philosophy: No Black Box, Spirit of Sharing
Based on the spirit of Amateur Radio, OpenCCVoice upholds the following philosophy:

> **"Free to use, free to improve, and results are shared openly."**

We aim to avoid "black boxing"—where technology is hoarded by a few—and instead encourage mutual technological advancement by allowing many stations to participate in improvements.
The name **"OpenCCVoice"** was chosen to symbolize this philosophy.

---

## Board Version and Firmware Compatibility

> ⚠️ **Board Ver.4 and Ver.5 have different pin assignments.**
> **Always use the firmware that matches your board version.**

| Board Version | Compatible Firmware | Status |
|---|---|---|
| Ver.4 | v1.73e or earlier (**1.x series**) | Legacy |
| **Ver.5** | **v2.01 or later (2.x series)** | **Current / Recommended** |

### Pin Assignment Comparison: Ver.4 vs Ver.5

| Signal | Ver.4 (1.x series) | **Ver.5 (2.x series)** |
|---|---|---|
| Test SW | D3 | **D2** |
| DFPlayer BUSY mirror output | D2 | **D3** |
| ModBusy LED | D4 | D4 (unchanged) |
| PTT output | D5 | D5 (unchanged) |
| Suppression LED | D13 | **D6** |
| A0 detect LED | D12 | **D7** |
| DFPlayer BUSY input | D7 | **D10** |
| TM BUSY input (Digital) | D6 | **D11** |
| Arduino TX → DFPlayer RX | D11 | **D13** |
| Arduino RX ← DFPlayer TX | D10 | **D12** |
| Analog BUSY | A0 | A0 (unchanged) |
| I²C SDA (DS3231/AT24C32) | N/A | **A4** (added in v2.10) |
| I²C SCL (DS3231/AT24C32) | N/A | **A5** (added in v2.10) |

> **Warning:** Writing 1.x series firmware to a Ver.5 board will cause malfunction due to pin assignment mismatch. The reverse is also true.

### License and Rights
The copyright of the schematics, Arduino sketches, PCB data, and related documentation belongs to **JA2CCV and the OpenCCVoice Project**.

OpenCCVoice is an open project aimed at technology sharing and development. Published materials are handled under different licenses depending on the file type: **hardware (schematics, PCB data, BOM, case) is licensed under CERN-OHL-S v2**, and **software (Arduino sketches) is licensed under GPL v3**.

#### 1. Usage and Modification
* Anyone is **free to use** this project.
* You may **modify, add features, or integrate** it as needed.

#### 2. Conditions for Redistribution (Copyleft)
When publishing or distributing modified versions or derivatives, you must observe the following conditions:

1.  **Credit the original authors (JA2CCV / OpenCCVoice).**
2.  **Clearly state the modifications made.**
3.  **Release the derivative works under the same open terms.**
    * Do not "black box" the project; you must publish the source code, schematics, and PCB data.

#### 3. About License Documents
The official license documents are included in the repository: see `LICENSE-HARDWARE.txt` (CERN-OHL-S v2) for hardware, and `LICENSE` (GPL v3) for software.

We hope that OpenCCVoice will continue to grow together with many stations.

### Disclaimer
Please read the following terms carefully before using the hardware designs (schematics, PCB data), software (source code), and documentation provided by the OpenCCVoice project.

1.  **No Warranty**
    This project is provided "AS IS", without warranty of any kind, express or implied, including but not limited to the warranties of merchantability or fitness for a particular purpose. The entire risk as to the quality and performance of the project is with you.
2.  **Limitation of Liability**
    In no event shall the authors or copyright holders be liable for any claim, damages, or other liability, whether in an action of contract, tort, or otherwise, arising from, out of, or in connection with the software/hardware or the use or other dealings in the project.
    * **Hardware Risk:** Connecting custom circuits to your radio equipment carries inherent risks. You assume full responsibility for any damage to your transceiver, computer, or other devices.
3.  **Regulatory Compliance**
    Users are solely responsible for complying with the radio laws and regulations of their respective countries or regions.
    * It is the user's responsibility to ensure that transmission intervals, audio levels, and operation methods comply with local legal requirements.
    * The authors assume no responsibility for any legal violations committed by the user.
4.  **License**
    The hardware of this project is released under the **CERN-OHL-S v2 (CERN Open Hardware Licence Version 2 - Strongly Reciprocal)**, and the software under the **GNU General Public License v3 (GPL v3)**. Please refer to each license for terms regarding redistribution and modification.

---
**Project Contributors:** JA2CCV, JA9HYM, JA2DML, JG1XWV, JI2TAB

---

## ライセンス構成 / License Structure

本プロジェクトは、ファイルの種類によって適用されるライセンスが異なります。
This project applies different licenses depending on the type of file.

### ハードウェア / Hardware
回路図、PCB基板データ、BOM（部品表）、ケースデータ
（対象ディレクトリ: `circuit/`, `pcb/`, `bom/`, `case/`）

**CERN Open Hardware Licence Version 2 - Strongly Reciprocal (CERN-OHL-S v2)**
→ `LICENSE-HARDWARE.txt` を参照 / See `LICENSE-HARDWARE.txt`

### ソフトウェア / Software
Arduino スケッチ等のソースコード
（例: `CCVoice_*/`, `old_firmware/`, `DMR Arduino ID V4-2/`）

**GNU General Public License v3.0 (GPL-3.0)**
→ `LICENSE` を参照 / See `LICENSE`

> 上記の記述と本 README 中の他のライセンス記述が矛盾する場合は、本「ライセンス構成」セクションが優先されます。
> > In case of conflict between this section and other license descriptions in this README, this "License Structure" section takes precedence.
> >

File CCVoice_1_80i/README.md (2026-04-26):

# **OpenCCVoice Guidance Controller**

取扱説明書 / コマンドリファレンス  
**バージョン: v1.80i**  
**最終更新日: 2026/03/24**  
対象ハード: Arduino Nano (ATmega328P / 5V)  
通信設定: 115200 bps / 8N1 / 改行なし（または LF）

---

## ■ 概要

本機は DMR無線機のID送出を自動制御するコントローラです。  
PCとUSB接続し、シリアルモニタから各種コマンドで設定を変更できます。

全ての設定は EEPROM に自動保存され、電源断でも保持されます。

**v1.80i** では v1.80h のコード品質改善を行いました。主な変更点は以下のとおりです。

- カーチャンク検出時の `busySupUntil` 二重セットを修正（起点A に一本化）
- ver=3 以前からのマイグレーション時の不定値リスクを修正
- `handleStoppedState()` 内のデッドコードを削除
- コメント内の旧用語・内部開発版番号を修正

EEPROM CONFIG_VERSION は 5 のまま変更なし。v1.80h からの書き込みは EEPROM 操作不要です。

**v1.80h** では v1.73f1 からの大規模な仕様刷新を行いました。主な変更点は以下のとおりです。

- カーチャンク判定の明確化（② MAX デフォルト: 3900ms → 1500ms）
- PTT 先行・後行無音時間（PRE/POST）をコマンドで可変化（`j####` / `J####`）
- 抑止ロジックを一本化（連打抑止BURSTを廃止し、`busySupUntil` のみで管理）
- 定周期IDをスキップ仕様に変更（旧: 延期保持 → 新: 到来時に条件不成立なら破棄）
- PRE/POST 待機を絶対時刻比較に変更（ブロッキングによるスキップバグを修正）
- ログレベルコマンドを `l0/l1/l2/l3` に変更、STOP復帰コマンドを `R`（大文字）に変更

---

## ■ 本バージョン（v1.80i）の主な変更点

### 【仕様番号とコマンド対応】

本バージョンから、コア動作に関わる主要パラメータに仕様番号を付与しています。

| 番号 | 内容 | コマンド | デフォルト |
|---|---|---|---|
| ① | カーチャンク最小受信長 | `n####` | 500ms |
| ② | カーチャンク最大受信長 | `b####` | 1500ms |
| ③ | PTT先行無音時間（PRE） | `j####` | 1000ms |
| ④ | PTT後行無音時間（POST） | `J####` | 1000ms |
| ⑤ | 抑止時間 | `r####` | 10000ms |
| ⑥ | 定周期間隔 | `p##` | 30分 |

### 【抑止ロジックの刷新】

旧来の「長話抑止（longSupUntil）」「連打抑止（burstSupUntil）」「送信直後ガード（postTxIgnore）」を廃止し、⑤抑止（busySupUntil）に一本化しました。

**⑤抑止の起点：**

- **起点A**: ④ POST 終了の瞬間（カーチャンクID送出後、受信中でない場合）
- **起点B**: ② 超え受信（通常会話）の終了の瞬間
- 受信中に POST が終わった場合は起点B が起点A を上書き

### 【定周期IDのスキップ仕様】

受信中・抑止中・PTT中に周期が到来したら、その回をスキップ（破棄）します。
旧仕様の「条件不成立時に periodicDue を保持して延期」から変更されました。

> **注意**: スキップが頻発する場合は `k####` を短くするか、`p##` の周期を見直してください。

### 【PRE/POST バグ修正】

旧実装では `Serial.parseInt()` のブロッキング中に `millis()` が進み、PRE 無音時間がスキップされる場合がありました。`Serial.setTimeout(50)` を `setup()` で一度だけ設定し、PRE/POST 待機を絶対時刻比較（`pttPreEndAt` / `pttPostEndAt`）に変更することで修正しました。

---

## 1. クイック・コマンド一覧

| コマンド | パラメータ | 既定値 | 説明 |
|---|---|---|---|
| `n` | 100〜 | 500 | ① 最小受信長 (ms) |
| `b` | 500〜 | 1500 | ② 最大受信長 (ms) |
| `j` | 100〜 | 1000 | ③ PTT先行無音時間 PRE (ms) |
| `J` | 100〜 | 1000 | ④ PTT後行無音時間 POST (ms) |
| `r` | 0〜 | 10000 | ⑤ 抑止時間 (ms) |
| `p` | 0〜 | 30 | ⑥ 定周期ID（分）※0=停止 |
| `k` | 0〜600000 | 2000 | 定周期送出前の静寂待機時間 (ms) |
| `m` | 0/1/2 | 0 | BUSYソース: D6固定 / A0固定 / AUTO判定 |
| `g` | 0/1 | 1 | BUSY極性: 0=LOW=busy / 1=HIGH=busy |
| `L` | 0〜1023 | 300 | A0閾値LOW |
| `G` | 0〜1023 | 700 | A0閾値HIGH |
| `a` | 0〜 | 800 | A0保持時間 (ms) |
| `w` | 1〜 | 30 | AUTO観測時間（分） |
| `d` | 0〜 | 20000 | DFPフェイルセーフ (ms) ※0=無効 |
| `V` | — | — | バージョン表示（スケッチver + EEPROM_VER） |
| `q` | — | — | 設定一覧（全パラメータ表示） |
| `x` | — | — | Safe Stop（全機能停止） |
| `R` | — | — | Safe Stop からの復帰 |
| `h` | — | — | コマンド一覧 |
| `l0〜l3` | — | — | ログレベル（OFF/MIN/FULL/DBG） |
| `F` | — | — | Factory Reset（EEPROM初期化） |
| `Z` | — | — | ソフトウェアリセット（WDT、EEPROM変更なし） |

---

## 2. コマンド詳細解説

**[m：モード設定]**  
m0 … D6（デジタルBUSY）固定  
m1 … A0（アナログ）固定  
m2 … AUTO（D6/A0 を観測し優位側へ自動固定）  
※ AUTO中は D6/A0 どちらの入力でも ID が出る

**[b / n：① ② カーチャンク検出窓]**

```
dur < n####              → ノイズ扱い（無視）
n#### ≤ dur < b####      → カーチャンク → ID送出
dur ≥ b####              → 通常会話 → ⑤抑止開始（起点B）
```

n#### … dur < n#### はノイズ扱い（デフォルト 500ms）  
b#### … dur ≥ b#### は通常会話と判定（デフォルト 1500ms）

**[j / J：③ ④ PTT 先行・後行無音時間]**  
j#### … PTT ON から DFPlayer 再生開始までの先行無音時間（デフォルト 1000ms）  
J#### … DFPlayer 再生完了から PTT OFF までの後行無音時間（デフォルト 1000ms）  
どちらも EEPROM に保存される

**[r：⑤ 抑止時間]**  
r#### … 抑止が発動してからの抑止継続時間（ms）  
r0 … 実質的な抑止無効（送信後抑止を無くしたい場合）  
デフォルト 10000ms（10秒）

**[p / k：⑥ 定周期ID]**  
p## … ##分ごとにトラック002/003を交互送出。p0 で停止。  
k#### … 定周期IDを送出する前に「BUSY OFFからの静寂期間（ms）」を要求する静寂ガード。  
　　　　条件不成立の場合はその回をスキップ（破棄）。

- 例：k2000 → BUSY 終了後 2秒静かなら送出（デフォルト）
- 例：k5000 → より強い割り込み防止
- k0 → 静寂ガード無効

**[w：AUTO観測期間]**  
AUTO_WINDOW 分観測 → 優位側へ固定（D13 高速点滅で通知）

**[L / G / a：A0アナログ判定パラメータ]**  
L### … この値を下回ったとき BUSY 開始と判定（デフォルト 300）  
G### … この値を上回ったとき BUSY 終了と判定（デフォルト 700）  
a#### … BUSY 終了判定後も a#### ms は BUSY 状態を保持（スケルチテール対策）（デフォルト 800ms）

**[d：DFPlayer フェイルセーフ]**  
DFPlayer BUSY が戻らない場合、d#### ms 経過で強制 PTT OFF。d0 で無効化。

**[g：BUSY 極性]**  
g0 = LOW=受信（アクティブLOW）  
g1 = HIGH=受信（アクティブHIGH）（既定）

**[x / R：停止と再開]**  
x … 全動作停止（Safe Stop）  
R … 停止中の復帰（STOP中のみ有効）

**[F：Factory Reset]**  
全設定を初期値に戻し EEPROM 保存。MCU は動き続ける。

**[V：バージョン確認]**  
出力例：`[VER] OpenCCVoice v1.80i (EEPROM_VER=5)`

**[Z：ソフトウェアリセット]**  
ウォッチドッグタイマー（15ms）で MCU を再起動。EEPROM は変更しない。  
`F` の後に `Z` を実行すると完全クリーン起動になる。

| 操作 | EEPROM | MCU | 用途 |
|---|---|-----|---|
| `F` のみ | 初期値で上書き | 動き続ける | 設定のみリセット |
| `Z` のみ | 変化なし | 再起動 | 設定保持のまま再起動 |
| `F` → `Z` | 初期値で上書き | 再起動 | 完全クリーン起動 |

**[l0〜l3：ログレベル]**  
l0=OFF / l1=MIN（起動時デフォルト）/ l2=FULL / l3=DBG  
EEPROM には保存されない。起動時は常に l1=MIN。

**[h：ヘルプ]**  
コマンド一覧をシリアル出力する。

---

## 3. 設定値解説（目的・実態・調整指針）

### 【m：BUSYソース選択】

無線機のBUSY信号をどのピンで受けるかを選ぶ。

- `m0`（D6）：デジタル入力。無線機のBUSY出力を直接接続する場合。
- `m1`（A0）：アナログ入力。スケルチ電圧等をヒステリシス判定で検出する場合。
- `m2`（AUTO）：起動後 `w##` 分間、D6エッジ数とA0イベント数を比較し、反応の多い側へ自動固定。固定後はEEPROMへ保存され再起動後も維持される。

固定配線が済んでいる場合は `m0` か `m1` を明示的に指定しておくのが安全。`m2` は初期設置・配線確認時に便利。

---

### 【① n / ② b：カーチャンク検出窓】

BUSYの継続時間がこの範囲に収まった場合を「カーチャンク」と判定し、トラック001（ID音声）を送出する。

- `n####`（デフォルト 500ms）：これより短い受信はノイズとみなし無視する。
- `b####`（デフォルト 1500ms）：これ以上の受信は通常会話とみなし、⑤抑止（起点B）に入る。

調整指針：カーチャンクが検出されない場合は `n` を小さく、通常会話中に誤って ID が出る場合は `b` を大きくする。

---

### 【③ j / ④ J：PTT 先行・後行無音時間】

- `j####`（デフォルト 1000ms）：PTT ON から DFPlayer への再生コマンド送出までの先行無音時間。相手局が受信体制に入るまでの余裕時間。
- `J####`（デフォルト 1000ms）：DFPlayer 再生完了から PTT OFF までの後行無音時間。音声が確実に伝わるまでの余裕時間。

両パラメータとも EEPROM に保存される。無線機の特性や運用環境に合わせて調整する。

---

### 【⑤ r：抑止時間】

カーチャンク検出後または通常会話終了後に発動する抑止の継続時間。

- デフォルト 10000ms（10秒）
- `r0` で実質的な送信後抑止無効

**抑止の起点：**
- 起点A: ④ POST 終了の瞬間（カーチャンクID送出後・受信中でない場合）
- 起点B: ② 超え受信（通常会話）終了の瞬間
- POST 終了時に受信中の場合は、起点B が起点A を上書きする

混信環境では `r15000` 程度に延ばすと誤発火が減る。

---

### 【⑥ p / k：定周期ID】

- `p##`（分）：`##` 分ごとにトラック002/003を交互送出。`p0` で停止。起動時刻基準で等間隔。
- `k####`（ms）：定周期IDを送出する前に「BUSY がOFFになってから `k####` ms 以上の静寂」を要求する静寂ガード。条件不成立の場合はその回をスキップ（破棄）。

デフォルト `k2000`（2秒）。通話が頻繁な環境では `k5000` 程度に延ばすと定時IDの割り込み感が大幅に減少する。

---

### 【w：AUTO観測窓】

`m2`（AUTO）選択時に D6/A0 のどちらを採用するかを判定する観測期間（分）。  
デフォルト 30分。試験時は `w1`〜`w5` で短縮可能。

---

### 【L / G / a：A0アナログ判定パラメータ】

A0 ピンのアナログ電圧（0〜1023）をヒステリシスで BUSY 判定する。

- `L###`（デフォルト 300）：この値を下回ったとき BUSY 開始と判定。
- `G###`（デフォルト 700）：この値を上回ったとき BUSY 終了と判定。
- `a####`（デフォルト 800ms）：BUSY 終了判定後も `a####` ms は BUSY 状態を保持（スケルチテール対策）。

ノイズが多い環境では L を小さく、G を大きくしてヒステリシス幅を広げると安定する。

---

### 【d：DFPlayer フェイルセーフ】

DFPlayer が再生を開始したまま BUSY ピンが戻らない（張り付き）場合に、`d####` ms 経過で強制的に PTT OFF する安全機構。

- デフォルト 20000ms（20秒）：音声ファイルの最大長より長めに設定するのが原則。
- `d0`：無効化（通常は非推奨）。

---

### 【g：BUSY 極性】

無線機の BUSY 出力の論理を合わせる。配線変更なしに対応できる。

- `g0`：LOW=受信（アクティブLOW）
- `g1`：HIGH=受信（アクティブHIGH）（デフォルト）

極性を間違えるとカーチャンク・通常会話の判定が完全に逆転するため、初期設定時に必ず `q` で確認すること。

---

## 4. LED表示の意味

| LED | 表示内容 |
|-----|---|
| D4（緑等） | D6 BUSY受信時点灯（AUTO中は D12 と交互に点滅） |
| D12（赤等） | A0 検知時点灯（AUTO中は D4 と交互に点滅） |
| D13（黄等） | 抑止中点灯 / AUTO固定時に高速点滅（約3秒） |
| D2 | DFPlayer BUSYミラー（反転：再生中=HIGH、停止中=LOW） |

---

## 5. フェイルセーフ（DFPlayer BUSY異常）

DFPlayer BUSY が戻らない場合、**d#### ms 経過後に強制 PTT OFF**。

- デフォルト：d20000（20秒）
- d0：無効化

---

## 6. トラブルシューティング

**● IDが出ない**

- Safe Stop 中（`x`）→ `R` で復帰
- 通常会話受信中（dur ≥ b####）→ ⑤抑止中
- D13 点灯中（⑤抑止中）では動作しない
- 定周期IDがスキップされている → `k####` を短くするか `p##` を見直す

**● ID が止まらない**

- `r####` を増やす
- `n####` を大きくする（ノイズの誤検知防止）

**● 送信後に ID が誤発火する**

- ⑤ 抑止時間（`r####`）を増やす
- `b####` を小さくして通常会話を確実に ② 超えと判定させる

**● 定周期IDが送出されない**

- `k####` が長すぎる可能性 → `k2000` 〜 `k0` で試す
- `p##` が 0 になっていないか `q` で確認

**● 音声が途中で切れる**

- `d####` を延長（d30000 など）
- SDカード内のファイル階層（`/mp3/0001.mp3` 等）を確認
- D7（BUSY）が途中 HIGH になっていないか確認

**● BUSY判定が逆**

- `g0/g1` の設定確認（`q` で `POL=LOW=busy` / `POL=HIGH=busy` を確認）
- D6 は INPUT_PULLUP 必須

**● PRE/POST 時間が短すぎる**

- `j####` / `J####` を増やす
- v1.80h 以降はブロッキングによるスキップバグが修正済み

---

## 7. 配線メモ（Ver.5 PCB）

```
DFPlayer TX → D10（Arduino RX）
DFPlayer RX ← D11（Arduino TX）
DFPlayer BUSY（LOW=再生中）→ D7
D7ミラー（反転）→ D2
TM BUSY → D6（g0/g1 で極性指定）
PTT → D5（HIGH=送信）
LED → D4（D6） / D12（A0） / D13（抑止/AUTO）
テストSW → D3（INPUT_PULLUP）
```

---

## 8. EEPROM について

### 【CONFIG_VERSION=5（v1.80i）】

- v1.80i の EEPROM CONFIG_VERSION は 5 です（v1.80h から変更なし）
- v1.73系（CONFIG_VERSION=4）からスケッチを書き込むと、起動時に自動マイグレーションが実行されます
- v1.80h からの書き込みは EEPROM 操作不要です

### 【自動マイグレーション内容（ver=4 → ver=5）】

| 処理 | 内容 |
|---|---|
| `pttPreMs` / `pttPostMs` を補完 | 1000ms で補完 |
| `busyMax` が旧デフォルト（3900ms）の場合 | 1500ms に更新 |
| `txSupMs` が旧デフォルト（3000ms）の場合 | 10000ms に更新 |
| 不正値の安全補完 | 極性・タイムアウト・静寂時間等 |

### 【起動時確認ログ】

正常アップグレード（ver=4 → ver=5）時：
```
[EEPROM] Version mismatch: stored=4 expected=5
[EEPROM] Migration done.
[EEPROM] Settings Loaded.
[START] OpenCCVoice v1.80i
```

初回起動またはデータ破損時：
```
[EEPROM] No/Other Data. Init defaults.
[EEPROM] Settings Loaded.
[START] OpenCCVoice v1.80i
```

---

## 9. タイムチャート

各挙動のタイミングと信号の流れを視覚的に確認できるタイムチャートを別ファイルで提供しています。

**ファイル：`OpenCCVoice_TimingChart.xlsx`**

| シナリオ | 内容 |
|---|---|
| ① カーチャンク → ID送出 | カーチャンク検出からPTT制御・ID音声送出・⑤抑止（起点A）までの流れ |
| ② 通常会話抑止 | dur が ② MAX を超えた場合の⑤抑止（起点B）の流れ |
| ③ 抑止中スキップ | 抑止中にカーチャンクが来た場合のスキップログ表示 |
| ④ 定周期ID 静寂ガード | 定時到来後、受信中・静寂不足でスキップされる流れ |
| ⑤ PRE/POST 保証動作 | 絶対時刻比較による PRE/POST の確実な保証 |

---

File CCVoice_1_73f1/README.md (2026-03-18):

# **OpenCCVoice Guidance Controller**

取扱説明書 / コマンドリファレンス  
**バージョン: v1.73f1-Unified-Safe**  
**最終更新日: 2026/02/13**  
対象ハード: Arduino Nano (ATmega328P / 5V)  
通信設定: 115200 bps / 8N1 / 改行なし(またはLF)

---

## ■ 概要

本機は DMR無線機のID送出を自動制御するコントローラです。  
PCとUSB接続し、シリアルモニタから各種コマンドで設定を変更できます。

全ての設定は EEPROM に自動保存され、電源断でも保持されます。  
**v1.73c から EEPROM にバージョン管理機能を搭載**し、スケッチ更新時の設定破損を防ぐ仕様になりました。  
**v1.73d では「周期IDの静寂ガード」機能（k####）** が追加され、通話中の割り込み問題を大幅に改善しました。  
**v1.73e では「送信直後ガード（postTxIgnore）」と「周期ID catch-up 対策」** により、実運用上の誤発火・連続発火を根治しました。  
**v1.73f1 では `v` コマンドを `V`（大文字）に変更（v2.x系との競合回避）** しました。
**v1.73f では「`V`（バージョン確認）」と「`Z`（ソフトウェアリセット）」コマンド** を追加し、運用・保守性を向上しました。

---

## ■ 本バージョン（v1.73f1）の特徴

### 【v1.73f1 変更コマンド / v1.73f 追加コマンド】

**`V` コマンド：バージョン確認**

- スケッチバージョンと EEPROM_VER を表示
- 起動ログを見逃した後でもいつでも確認可能
- 出力例：`[VER] OpenCCVoice v1.73f1 (EEPROM_VER=4)`

**`Z` コマンド：ソフトウェアリセット**

- ウォッチドッグタイマー（WDT, 15ms）で MCU を再起動
- EEPROM は変更しない（設定は保持されたまま再起動）
- `F` と組み合わせることで完全クリーン起動が可能

| 操作 | EEPROM | MCU | 用途 |
|---|---|-----|---|
| `F` のみ | 初期値で上書き | 動き続ける | 設定のみリセット |
| `Z` のみ | 変化なし | 再起動 | 設定保持のまま再起動 |
| `F` → `Z` | 初期値で上書き | 再起動 | 完全クリーン起動 |

### 【v1.73e から継承：送信直後ガード・catch-up 対策】

**送信直後ガード（postTxIgnore）**

- PTT OFF 直後、A0 残留BUSY・スケルチテール・瞬間的な BUSY 揺れによる
  **短発ID（001）や周期IDの誤発火を防止**
- BUSY が連続して `idleMin` ms 以上 OFF になった時点で自動解除
- `isSuppressedNow()` に統合されており、短発・周期ID の両方に適用

**周期ID catch-up 対策**

- 長時間 BUSY/抑止が続いた後の **周期ID 連続送信を防止**
- `nextPeriodicAt` を `while` で未来へ追い付かせ、`periodicDue` は最大1回のみ立てる設計

**A0 BUSY 観測の安定化**

- 抑止中であっても A0 の BUSY 状態（`a0Busy`）は継続して観測
- 抑止中は AUTO 判定用カウント（`a0_event_count`）のみ増加させない

### 【v1.73d から継承：周期ID 静寂ガード（Quiet Guard）】

- 周期ID（002/003）は、**BUSY が OFF になってから k#### ms 静寂継続**した場合のみ送出
- BUSY中 / 静寂不足 / 抑止期間中は **延期（periodicDue保持）**
- 新コマンド：`k####`（既定：2000ms、`k0` で無効）
- `q` で `QUIET(ms)=xxxx` を確認可能

### 【EEPROM バージョン管理（v1.73c〜、config.ver=4）】

- 起動時に EEPROM のレイアウト版を判定
- 古いバージョンを自動補完 / 移行（マイグレーション）
- `q` に **EEPROM_VER=4** と表示

> **注意**：`k0` を設定して再起動すると、`migrateOrInit()` の補完ロジックにより
> `periodQuietMs` が 2000ms にリセットされる場合があります。
> 再起動後は `q` で QUIET(ms) を確認し、必要なら再度 `k0` を実行してください。

---

## 1. クイック・コマンド一覧

コマンド | パラメータ | 既定値 | 説明
---------|-----------|--------|------
m        | 0/1/2      | 0      | D6固定 / A0固定 / AUTO判定
b        | 500〜      | 3900   | 最大受信長 (ms)
n        | 100〜      | 500    | 最小受信長 (ms)
i        | 0〜        | 200    | 送信後BUSY安定待ち時間 (ms)
s        | 0/1        | 1      | 抑止 ON/OFF
t        | 0/1        | 1      | 送信後無視 ON/OFF（s1時）
r        | 0〜        | 3000   | 送信後無視時間 (ms)
p        | 0〜        | 30     | 周期ID（分）※0=停止
k        | 0〜600000  | 2000   | ★周期ID静寂時間(ms)
w        | 1〜        | 30     | AUTO観測時間（分）
L        | 0〜1023    | 300    | A0閾値LOW
G        | 0〜1023    | 700    | A0閾値HIGH
a        | 0〜        | 800    | A0保持時間(ms)
d        | 0〜        | 20000  | DFPフェイルセーフ(ms) ※0=無効
g        | 0/1        | 1      | TM BUSY極性 (LOW/HIGH=busy)
q        | -          | -      | 設定一覧（EEPROM_VER含む）
V        | -          | -      | ★バージョン表示（スケッチver + EEPROM_VER）
H        | -          | -      | 汎用プリセット (s0/t0/b3900)
x        | -          | -      | Safe Stop（全機能停止）
r        | -          | -      | 停止状態から復帰 ※STOP中のみ有効
h        | -          | -      | コマンド一覧
0〜3     | -          | -      | ログレベル
F        | -          | -      | Factory Reset（EEPROM初期化）
Z        | -          | -      | ★ソフトウェアリセット（WDT、EEPROM変更なし）

> **`r` コマンドについて**：通常運転中は `r####`（送信後無視時間の設定）として動作します。
> `x` で停止した後は `r`（パラメータなし）で復帰コマンドとして機能します。

---

## 2. コマンド詳細解説

**[m：モード設定]**  
m0 … D6（デジタルBUSY）  
m1 … A0（アナログ）  
m2 … AUTO（D6/A0 を観測し優位側へ自動固定）  
※ AUTO中は D6/A0 どちらの入力でも ID が出る

**[b：最大受信長]**  
b3900（3.9秒）までを短発として受付  
dur ≥ b#### は長話と判定し 10秒抑止（LONG_SUP）

**[n / i：最小受信長 / 送信後BUSY安定待ち時間]**  
n#### … dur < n#### はノイズ扱い  
i#### … 送信直後、BUSYがこの時間連続OFFになるまで次のトリガーを受け付けない

**[s / t / r：抑止ガード]**  
s1 … 抑止 ON（長話/連打検出）  
t1 … 自局送出後、r#### ms BUSY を無視  
r#### … 送信後無視時間

**[p：周期ID]**  
p##（分）で 002/003 を交互送出  
絶対時刻基準で等間隔

**[k：周期IDの静寂ガード（v1.73d〜）]**  
周期IDを出すための「BUSY OFF からの静寂期間（ms）」

- 例：k2000 → BUSY 終了後 2秒静かなら送出
- 例：k5000 → より強い割り込み防止
- k0 → 静寂ガード無効（※再起動後にリセットされる場合あり、要確認）

**[w：AUTO観測期間]**  
AUTO_WINDOW 分観測 → 優位側へ固定（D13 高速点滅）

**[A0検知（L/G/a）]**  
LOW/HIGH閾値＋保持時間でアナログBUSYを安定化

**[d：DFPフェイルセーフ]**  
DFPlayer BUSY が戻らない場合、d#### ms 経過で強制 PTT OFF  
d0 で無効化

**[g：TM BUSY極性]**  
g0 = LOW=busy  
g1 = HIGH=busy（既定）

**[x / r：停止と再開]**  
x … 全動作停止  
r … 停止中の復帰

**[F：初期値へ]**  
全設定を初期化し EEPROM 保存

**[V：バージョン確認]**  
スケッチバージョンと EEPROM_VER を表示  
出力例：`[VER] OpenCCVoice v1.73f1 (EEPROM_VER=4)`

**[Z：ソフトウェアリセット]**  
ウォッチドッグタイマー（15ms）で MCU を再起動  
EEPROM は変更しない。`F` の後に実行すると完全クリーン起動になる

**[h / 0〜3：ヘルプ・ログ]**  
h … コマンド一覧  
0〜3 … ログレベル（NONE/ERR/INF/DBG）

---

## 3. 設定値解説（目的・実態・調整指針）

### 【m：BUSYソース選択】

無線機のBUSY信号をどのピンで受けるかを選ぶ。

- `m0`（D6）：デジタル入力。無線機のBUSY出力を直接接続する場合。
- `m1`（A0）：アナログ入力。スケルチ電圧等をヒステリシス判定で検出する場合。
- `m2`（AUTO）：起動後 `w##` 分間、D6エッジ数とA0イベント数を比較し、反応の多い側へ自動固定。固定後はEEPROMへ保存され再起動後も維持される。

実態として、固定配線が済んでいる場合は `m0` か `m1` を明示的に指定しておくのが安全。`m2` は初期設置・配線確認時に便利。

---

### 【b / n：カーチャンク検出窓】

BUSYの継続時間がこの範囲に収まった場合を「短発（カーチャンク）」と判定し、トラック001（ID音声）を送出する。

```
dur < n####              → ノイズ扱い（無視）
n#### ≤ dur < b####      → 短発＝カーチャンク → ID送出
dur ≥ b####              → 長話 → 10秒抑止
```

- `n####`（既定500ms）：これより短い受信はノイズとみなし無視する。電波状況が悪い場合は大きくする。
- `b####`（既定3900ms）：これ以上の受信は長話とみなし、10秒間の抑止に入る。通常の通話が短い環境では小さくしてよい。

調整指針：カーチャンクが検出されない場合は `n` を小さく、長話中に誤って ID が出る場合は `b` を大きくする。

---

### 【i：送信後BUSY安定待ち時間】

送信直後、BUSYが連続して `i####` ms 以上 OFF になるまで次のIDトリガーを受け付けない待ち時間。`postTxIgnore` ガードの解除閾値として機能する。

- 既定 200ms：送信終了後、スケルチテールや残留BUSYが収まるまでの待ち時間。
- 値を大きくするほど安定待ち時間が長くなり、送信直後の誤発火防止効果が増す。
- A0残留BUSYが長く続く環境では `i500` 程度に増やすと効果的。

> **注意：変数名（`idleMin`）は過去のバージョンから引き継いだ名称です。**  
> v1.73系では短発判定への直接の影響はなく、送信後BUSY安定待ちの用途のみで機能しています。

---

### 【s / t / r：抑止ガード】

- `s0/1`：抑止機能全体の ON/OFF。`s0` にすると長話・連打抑止が無効になる。汎用プリセット `H` も `s0` を設定する。
- `t0/1`：自局ID送出後の送信後抑止の ON/OFF。`s1` が前提。
- `r####`：送信後抑止の時間（ms）。自局がID送出した直後、この時間内に来た BUSY を無視する。再び相手が送信してきても反応しないバッファ時間。

実態として `s1 / t1 / r3000` の組み合わせが標準的な運用。混信環境では `r5000` 程度に延ばすと誤発火が減る。

---

### 【p / k：周期ID】

- `p##`（分）：`##` 分ごとにトラック002/003を交互送出する。`p0` で停止。絶対時刻スケジューリングのため電源投入後から等間隔になる。
- `k####`（ms）：周期IDを送出する前に「BUSY がOFFになってから `k####` ms 以上の静寂」を要求する静寂ガード。これが満たされない場合は送出を延期し、次の機会を待つ。

実態として `k2000`（2秒）が既定。通話が頻繁な環境では `k5000` 程度に延ばすと「会話中に定時IDが割り込む」体感が大幅に減少する。`k0` で静寂ガード無効（ただし再起動後は2000msにリセットされる既知の挙動あり）。

---

### 【w：AUTO観測窓】

`m2`（AUTO）選択時に、D6/A0 のどちらを採用するかを判定する観測期間（分）。  
観測窓内のエッジ数・イベント数が多い側へ自動固定する。

- 既定30分：設置直後の30分間の実際の受信状況で自動判定する。
- 短縮したい場合は `w1`〜`w5` で試験可能。

---

### 【L / G / a：A0アナログ判定パラメータ】

A0 ピンのアナログ電圧（0〜1023）をヒステリシスで BUSY 判定する。

- `L###`（既定300）：この値を**下回ったとき**に BUSY 開始と判定（立ち上がり閾値）。
- `G###`（既定700）：この値を**上回ったとき**に BUSY 終了と判定（立ち下がり閾値）。
- `a####`（既定800ms）：BUSY 終了判定後も `a####` ms は BUSY 状態を保持する（スケルチテール対策）。

L と G の差がヒステリシス幅になる。ノイズが多い環境では L を小さく、G を大きくして幅を広げると安定する。

---

### 【d：DFPlayer フェイルセーフ】

DFPlayer が再生を開始したまま BUSY ピンが戻らない（張り付き）場合に、`d####` ms 経過で強制的に PTT OFF する安全機構。

- 既定20000ms（20秒）：音声ファイルの最大長より長めに設定するのが原則。
- `d0`：無効化（SDカードの状態に関係なく PTT が張り付く可能性があるため通常は非推奨）。

音声ファイルが長い場合は `d####` を再生時間＋余裕分に合わせて調整する。

---

### 【g：TM BUSY 極性】

無線機の BUSY 出力の論理を合わせる。配線変更なしに対応できる。

- `g0`：LOW=受信（アクティブLOW、受信中に LOW を出力する無線機）
- `g1`：HIGH=受信（アクティブHIGH、受信中に HIGH を出力する無線機）（既定）

極性を間違えると短発・長話の判定が完全に逆転するため、初期設定時に必ず `q` で `TM_BUSY_POL` を確認すること。

---

## 4. LED表示の意味

[D4]  … D6 BUSY受信時点灯（AUTO中はD12と交互点滅）  
[D12] … A0 検知時点灯（AUTO中はD4と交互点滅）  
[D13] … 抑止/短発窓/AUTO固定（高速点滅）表示  
[D2]  … DFPlayer BUSYミラー（反転：再生中=HIGH）

---

## 5. フェイルセーフ（DFPlayer BUSY異常）

DFPlayer BUSY が戻らない場合、**d#### ms 経過後に強制 PTT OFF**。

- 既定：d20000
- d0：無効（判定スキップ）

---

## 6. トラブルシューティング

**● IDが出ない**

- 停止中（x）→ r
- 長話（b3900超）→ 抑止
- D13 点灯中（抑止）では動作しない
- 送信直後の postTxIgnore ガード中（BUSY が落ち着くまで自動解除待ち）

**● ID が止まらない**

- t1 と r#### を増やす
- n#### / i#### を大きくする

**● 送信後に ID が誤発火する**

- v1.73e の postTxIgnore ガードが有効か確認（ログレベル 3 で `[POST-TX] cleared` を確認）
- BUSY が落ち着かない環境では i#### を大きくする

**● 周期IDが連続して送出された**

- v1.73e の catch-up 対策が有効か確認
- 長時間の BUSY 後にまとめて送出される旧挙動は本バージョンで修正済み

**● 音声が途中で切れる**

- d#### を延長（d20000 など）
- SDカード階層（/mp3/0001.mp3）を確認
- D7(BUSY) が途中 HIGH になっていないか

**● BUSY判定が逆**

- g0/g1 の設定確認
- D6 は INPUT_PULLUP 必須

**● k0 を設定したのに再起動後に k2000 に戻る**

- 既知の挙動。再起動後に `q` で確認し、必要なら再度 `k0` を実行

---

## 7. 配線メモ（v1.73f1）

```
DFPlayer TX → D10（Arduino RX）
DFPlayer RX ← D11（Arduino TX）
DFPlayer BUSY（LOW=再生中）→ D7
D7ミラー（反転）→ D2
TM BUSY → D6（g0/g1 で極性指定）
PTT → D5（HIGH=送信）
LED → D4（D6） / D12（A0） / D13（抑止/AUTO）
テストSW → D3（INPUT_PULLUP）
```

---

## 8. v1.73f1 仕様まとめ

**【V コマンド：バージョン確認】**

- `V` を入力するとスケッチバージョンと EEPROM_VER を表示
- 出力例：`[VER] OpenCCVoice v1.73f1 (EEPROM_VER=4)`
- 起動ログを見逃した後でもいつでも確認可能

**【Z コマンド：ソフトウェアリセット】**

- ウォッチドッグタイマー（WDT, 15ms）で MCU を再起動
- EEPROM は変更しない（設定を保持したまま再起動）
- `F` の後に `Z` を実行すると完全クリーン起動になる
- シリアル出力を確実に吐き出してから WDT 発火（delay 100ms 挿入）

**【送信直後ガード（postTxIgnore）】**（v1.73e 継承）

- PTT OFF 直後に `postTxIgnore = true` をセット
- BUSY が `idleMin` ms 連続 OFF になるまで、短発・周期ID を抑止扱いにする
- `isSuppressedNow()` に組み込まれており、既存の抑止ロジックと統一

**【周期ID catch-up 対策】**（v1.73e 継承）

- `nextPeriodicAt` の更新を `while` ループで実施
- 長時間延期後も `periodicDue` は最大1回のみ
- ログレベル DBG（3）で `[Periodic] due flag set (catch-up)` を確認可能

**【EEPROM バージョン（CONFIG_VERSION=4）】**

- v1.73f1 は EEPROM レイアウト変更なし（v1.73d/e/f と同一）
- v1.73d/e/f（ver=4）からの更新では自動移行不要、EEPROM をそのまま継続利用可能
- v1.73c 以前からの更新時は自動マイグレーションが実行される

---

## 9. タイムチャート

各挙動のタイミングと信号の流れを視覚的に確認できるタイムチャートを別ファイルで提供しています。

**ファイル：`OpenCCVoice_TimingChart.xlsx`**

チャートには以下の5つのシナリオを共通タイムライン（1セル=200ms）で収録しています。

| シナリオ | 内容 |
|---|---|
| ① 短発 → ID送出 | カーチャンク検出からPTT制御・ID音声送出・不応期・送信後抑止までの一連の流れ |
| ② 長話抑止 | 受信継続時間がMAX(3900ms)を超えた場合の長話抑止10秒 |
| ③ 連打抑止 | 10秒窓内に短発2回以上で連打抑止10秒が発動する流れ |
| ④ 送信直後ガード | PTT解放直後の残留BUSY・スケルチテールを送信直後ガードでブロックする流れ |
| ⑤ 周期ID 静寂ガード | 定時到来後、通話中・静寂不足で延期され静寂条件成立で送出される流れ |

チャート内の各セグメントには①〜⑳の番号が付いており、シート下部の解説エリアで各番号の動作内容を説明しています。

---

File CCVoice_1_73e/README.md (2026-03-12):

# **OpenCCVoice Guidance Controller**

取扱説明書 / コマンドリファレンス  
**バージョン: v1.73e-Unified-Safe**  
**最終更新日: 2026/02/13**  
対象ハード: Arduino Nano (ATmega328P / 5V)  
通信設定: 115200 bps / 8N1 / 改行なし(またはLF)

---

## ■ 概要

本機は DMR無線機のID送出を自動制御するコントローラです。  
PCとUSB接続し、シリアルモニタから各種コマンドで設定を変更できます。

全ての設定は EEPROM に自動保存され、電源断でも保持されます。  
**v1.73c から EEPROM にバージョン管理機能を搭載**し、スケッチ更新時の設定破損を防ぐ仕様になりました。  
**v1.73d では「周期IDの静寂ガード」機能（k####）** が追加され、通話中の割り込み問題を大幅に改善しました。  
**v1.73e では「送信直後ガード（postTxIgnore）」と「周期ID catch-up 対策」** により、実運用上の誤発火・連続発火を根治しました。

---

## ■ 本バージョン（v1.73e）の特徴

### 【v1.73e 新機能・修正点】

**送信直後ガード（postTxIgnore）**

- PTT OFF 直後、A0 残留BUSY・スケルチテール・瞬間的な BUSY 揺れによる
  **短発ID（001）や周期IDの誤発火を防止**
- BUSY が連続して `idleMin` ms 以上 OFF になった時点で自動解除
- `isSuppressedNow()` に統合されており、短発・周期ID の両方に適用

**周期ID catch-up 対策**

- 長時間 BUSY/抑止が続いた後の **周期ID 連続送信を防止**
- `nextPeriodicAt` を `while` で未来へ追い付かせ、`periodicDue` は最大1回のみ立てる設計

**A0 BUSY 観測の安定化**

- 抑止中であっても A0 の BUSY 状態（`a0Busy`）は継続して観測
- 抑止中は AUTO 判定用カウント（`a0_event_count`）のみ増加させない

### 【v1.73d から継承：周期ID 静寂ガード（Quiet Guard）】

- 周期ID（002/003）は、**BUSY が OFF になってから k#### ms 静寂継続**した場合のみ送出
- BUSY中 / 静寂不足 / 抑止期間中は **延期（periodicDue保持）**
- 新コマンド：`k####`（既定：2000ms、`k0` で無効）
- `q` で `QUIET(ms)=xxxx` を確認可能

### 【EEPROM バージョン管理（v1.73c〜、config.ver=4）】

- 起動時に EEPROM のレイアウト版を判定
- 古いバージョンを自動補完 / 移行（マイグレーション）
- `q` に **EEPROM_VER=4** と表示

> **注意**：`k0` を設定して再起動すると、`migrateOrInit()` の補完ロジックにより
> `periodQuietMs` が 2000ms にリセットされる場合があります。
> 再起動後は `q` で QUIET(ms) を確認し、必要なら再度 `k0` を実行してください。

---

## 1. クイック・コマンド一覧

コマンド | パラメータ | 既定値 | 説明
---------|-----------|--------|------
m        | 0/1/2      | 0      | D6固定 / A0固定 / AUTO判定
b        | 500〜      | 3900   | 最大受信長 (ms)
n        | 100〜      | 500    | 最小受信長 (ms)
i        | 0〜        | 200    | 直前アイドル時間 (ms)
s        | 0/1        | 1      | 抑止 ON/OFF
t        | 0/1        | 1      | 送信後無視 ON/OFF（s1時）
r        | 0〜        | 3000   | 送信後無視時間 (ms)
p        | 0〜        | 30     | 周期ID（分）※0=停止
k        | 0〜600000  | 2000   | ★周期ID静寂時間(ms)
w        | 1〜        | 30     | AUTO観測時間（分）
L        | 0〜1023    | 300    | A0閾値LOW
G        | 0〜1023    | 700    | A0閾値HIGH
a        | 0〜        | 800    | A0保持時間(ms)
d        | 0〜        | 20000  | DFPフェイルセーフ(ms) ※0=無効
g        | 0/1        | 1      | TM BUSY極性 (LOW/HIGH=busy)
q        | -          | -      | 設定一覧（EEPROM_VER含む）
H        | -          | -      | 汎用プリセット (s0/t0/b3900)
x        | -          | -      | Safe Stop（全機能停止）
r        | -          | -      | 停止状態から復帰 ※STOP中のみ有効
h        | -          | -      | コマンド一覧
0〜3     | -          | -      | ログレベル
F        | -          | -      | Factory Reset（EEPROM初期化）

> **`r` コマンドについて**：通常運転中は `r####`（送信後無視時間の設定）として動作します。
> `x` で停止した後は `r`（パラメータなし）で復帰コマンドとして機能します。

---

## 2. コマンド詳細解説

**[m：モード設定]**  
m0 … D6（デジタルBUSY）  
m1 … A0（アナログ）  
m2 … AUTO（D6/A0 を観測し優位側へ自動固定）  
※ AUTO中は D6/A0 どちらの入力でも ID が出る

**[b：最大受信長]**  
b3900（3.9秒）までを短発として受付  
dur ≥ b#### は長話と判定し 10秒抑止（LONG_SUP）

**[n / i：最小受信長 / 直前アイドル]**  
n#### … dur < n#### はノイズ扱い  
i#### … 直前アイドル < i#### は短発無効化

**[s / t / r：抑止ガード]**  
s1 … 抑止 ON（長話/バースト検出）  
t1 … 自局送出後、r#### ms BUSY を無視  
r#### … 送信後無視時間

**[p：周期ID]**  
p##（分）で 002/003 を交互送出  
絶対時刻基準で等間隔

**[k：周期IDの静寂ガード（v1.73d〜）]**  
周期IDを出すための「BUSY OFF からの静寂期間（ms）」

- 例：k2000 → BUSY 終了後 2秒静かなら送出
- 例：k5000 → より強い割り込み防止
- k0 → 静寂ガード無効（※再起動後にリセットされる場合あり、要確認）

**[w：AUTO観測期間]**  
AUTO_WINDOW 分観測 → 優位側へ固定（D13 高速点滅）

**[A0検知（L/G/a）]**  
LOW/HIGH閾値＋保持時間でアナログBUSYを安定化

**[d：DFPフェイルセーフ]**  
DFPlayer BUSY が戻らない場合、d#### ms 経過で強制 PTT OFF  
d0 で無効化

**[g：TM BUSY極性]**  
g0 = LOW=busy  
g1 = HIGH=busy（既定）

**[x / r：停止と再開]**  
x … 全動作停止  
r … 停止中の復帰

**[F：初期値へ]**  
全設定を初期化し EEPROM 保存

**[h / 0〜3：ヘルプ・ログ]**  
h … コマンド一覧  
0〜3 … ログレベル（NONE/ERR/INF/DBG）

---

## 3. LED表示の意味

[D4]  … D6 BUSY受信時点灯（AUTO中はD12と交互点滅）  
[D12] … A0 検知時点灯（AUTO中はD4と交互点滅）  
[D13] … 抑止/短発窓/AUTO固定（高速点滅）表示  
[D2]  … DFPlayer BUSYミラー（反転：再生中=HIGH）

---

## 4. フェイルセーフ（DFPlayer BUSY異常）

DFPlayer BUSY が戻らない場合、**d#### ms 経過後に強制 PTT OFF**。

- 既定：d20000
- d0：無効（判定スキップ）

---

## 5. トラブルシューティング

**● IDが出ない**

- 停止中（x）→ r
- 長話（b3900超）→ 抑止
- D13 点灯中（抑止）では動作しない
- 送信直後の postTxIgnore ガード中（BUSY が落ち着くまで自動解除待ち）

**● ID が止まらない**

- t1 と r#### を増やす
- n#### / i#### を大きくする

**● 送信後に ID が誤発火する**

- v1.73e の postTxIgnore ガードが有効か確認（ログレベル 3 で `[POST-TX] cleared` を確認）
- BUSY が落ち着かない環境では i#### を大きくする

**● 周期IDが連続して送出された**

- v1.73e の catch-up 対策が有効か確認
- 長時間の BUSY 後にまとめて送出される旧挙動は本バージョンで修正済み

**● 音声が途中で切れる**

- d#### を延長（d20000 など）
- SDカード階層（/mp3/0001.mp3）を確認
- D7(BUSY) が途中 HIGH になっていないか

**● BUSY判定が逆**

- g0/g1 の設定確認
- D6 は INPUT_PULLUP 必須

**● k0 を設定したのに再起動後に k2000 に戻る**

- 既知の挙動。再起動後に `q` で確認し、必要なら再度 `k0` を実行

---

## 6. 配線メモ（v1.73e）

```
DFPlayer TX → D10（Arduino RX）
DFPlayer RX ← D11（Arduino TX）
DFPlayer BUSY（LOW=再生中）→ D7
D7ミラー（反転）→ D2
TM BUSY → D6（g0/g1 で極性指定）
PTT → D5（HIGH=送信）
LED → D4（D6） / D12（A0） / D13（抑止/AUTO）
テストSW → D3（INPUT_PULLUP）
```

---

## 7. v1.73e 仕様まとめ

**【送信直後ガード（postTxIgnore）】**

- PTT OFF 直後に `postTxIgnore = true` をセット
- BUSY が `idleMin` ms 連続 OFF になるまで、短発・周期ID を抑止扱いにする
- `isSuppressedNow()` に組み込まれており、既存の抑止ロジックと統一

**【周期ID catch-up 対策】**

- `nextPeriodicAt` の更新を `while` ループで実施
- 長時間延期後も `periodicDue` は最大1回のみ
- ログレベル DBG（3）で `[Periodic] due flag set (catch-up)` を確認可能

**【EEPROM バージョン（CONFIG_VERSION=4）】**

- v1.73e は EEPROM レイアウト変更なし（v1.73d と同一）
- v1.73d（ver=4）からの更新では自動移行不要、EEPROM をそのまま継続利用可能
- v1.73c 以前からの更新時は自動マイグレーションが実行される

---

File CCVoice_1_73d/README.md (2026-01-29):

# **OpenCCVoice Guidance Controller**

取扱説明書 / コマンドリファレンス  
**バージョン: v1.73d-Unified-Safe**  
**最終更新日: 2026/01/30**  
対象ハード: Arduino Nano (ATmega328P / 5V)  
通信設定: 115200 bps / 8N1 / 改行なし(またはLF)

***

■ 概要  
本機は DMR無線機のID送出を自動制御するコントローラです。  
PCとUSB接続し、シリアルモニタから各種コマンドで設定を変更できます。

全ての設定は EEPROM に自動保存され、電源断でも保持されます。  
**v1.73c から EEPROM にバージョン管理機能を搭載**し、スケッチ更新時の設定破損を防ぐ仕様になりました。  
**v1.73d では「周期IDの静寂ガード」機能（k####）が新たに追加**され、通話中の割り込み問題を大幅に改善しました。

***

■ 本バージョン（v1.73d）の特徴

【EEPROM バージョン管理（config.ver）】

*   起動時に EEPROM のレイアウト版を判定
*   古いバージョンを自動補完 / 移行（マイグレーション）
*   不正値・未知バージョン → 自動初期化
*   `q` に **EEPROM\_VER=4** と表示（v1.73d の版番号）

【v1.73b/c の強化ポイントも継承】

*   TM BUSY（D6）の極性切替：  
    `g0 = LOW=busy` / `g1 = HIGH=busy`
*   フェイルセーフ（DFPlayer BUSY異常）：  
    `d####` で ms 変更、`d0` で無効化
*   AUTO 判定（m2）：  
    D6 / A0 の優位側を自動固定（EEPROM保存）
*   長話抑止 / バースト抑止 / 送信後抑止
*   BUSYデバウンス、PTTガード、周期ID

【v1.73d 新機能：周期ID 静寂ガード（Quiet Guard）】

*   周期ID（002/003）は、  
    **BUSY がOFFになってから k#### ms 静寂継続した場合のみ送出**
*   BUSY中 / 静寂不足 / 抑止期間中は **延期（periodicDue保持）**
*   新コマンド：`k####`
    *   既定：2000（2秒）
    *   `k0` で従来挙動に近い動作へ
*   `q` に **QUIET(ms)=xxxx** が表示される

***

1.  クイック・コマンド一覧

## コマンド | パラメータ | 既定値 | 説明

m        | 0/1/2      | 0      | D6固定 / A0固定 / AUTO判定
b        | 500〜      | 3900   | 最大受信長 (ms)
n        | 100〜      | 500    | 最小受信長 (ms)
i        | 0〜        | 200    | 直前アイドル時間 (ms)
s        | 0/1        | 1      | 抑止 ON/OFF
t        | 0/1        | 1      | 送信後無視 ON/OFF（s1時）
r        | 0〜        | 3000   | 送信後無視時間 (ms)
p        | 0〜        | 30     | 周期ID（分）※0=停止
k        | 0〜600000  | 2000   | ★周期ID静寂時間(ms)
w        | 1〜        | 30     | AUTO観測時間（分）
L        | 0〜1023    | 300    | A0閾値LOW
G        | 0〜1023    | 700    | A0閾値HIGH
a        | 0〜        | 800    | A0保持時間(ms)
d        | 0〜        | 20000  | DFPフェイルセーフ(ms) ※0=無効
g        | 0/1        | 1      | TM BUSY極性 (LOW/HIGH=busy)
q        | -          | -      | 設定一覧（EEPROM\_VER含む）
H        | -          | -      | 汎用プリセット (s0/t0/b3900)
x        | -          | -      | Safe Stop（全機能停止）
r        | -          | -      | 停止状態から復帰
h        | -          | -      | コマンド一覧
0〜3     | -          | -      | ログレベル
F        | -          | -      | Factory Reset（EEPROM初期化）

***

2.  コマンド詳細解説

\[m：モード設定]  
m0 … D6（デジタルBUSY）  
m1 … A0（アナログ）  
m2 … AUTO（D6/A0 を観測し優位側へ自動固定）  
※AUTO中は D6/A0 どちらの入力でも ID が出る

\[b：最大受信長]  
b3900（3.9秒）までを短発として受付  
dur ≥ b#### は長話と判定し 10秒抑止（LONG\_SUP）

\[n / i：最小受信長 / 直前アイドル]  
n#### … dur < n#### はノイズ扱い  
i#### … 直前アイドル < i#### は短発無効化

\[s / t / r：抑止ガード]  
s1 … 抑止 ON（長話/バースト検出）  
t1 … 自局送出後、r#### ms BUSY を無視  
r#### … 送信後無視時間

\[p：周期ID]  
p##（分）で 002/003 を交互送出  
絶対時刻基準で等間隔

\[k：周期IDの静寂ガード（v1.73d）]  
周期IDを出すための「BUSY OFF からの静寂期間（ms）」

*   例：k2000 → BUSY 終了後 2秒静かなら送出
*   例：k5000 → より強い割り込み防止
*   k0 → 静寂ガード無効（従来に近い）

\[w：AUTO観測期間]  
AUTO\_WINDOW 分観測 → 優位側へ固定（D13 高速点滅）

\[A0検知（L/G/a）]  
LOW/HIGH閾値＋保持時間でアナログBUSYを安定化

\[d：DFPフェイルセーフ]  
DFPlayer BUSY が戻らない場合、  
d#### ms 経過で強制PTT OFF  
d0 で無効化

\[g：TM BUSY極性]  
g0 = LOW=busy  
g1 = HIGH=busy（既定）

\[x / r：停止と再開]  
x … 全動作停止  
r … 停止中の復帰

\[F：初期値へ]  
全設定を初期化し EEPROM 保存

\[h / 0〜3：ヘルプ・ログ]  
h … コマンド一覧  
0〜3 … ログレベル（NONE/ERR/INF/DBG）

***

3.  LED表示の意味

\[D4] … D6 BUSY受信時点灯（AUTO中はD12と交互点滅）  
\[D12] … A0 検知時点灯（AUTO中はD4と交互点滅）  
\[D13] … 抑止/短発窓/AUTO固定（高速点滅）表示  
\[D2] … DFPlayer BUSYミラー（反転：再生中=HIGH）

***

4.  フェイルセーフ（DFPlayer BUSY異常）

DFPlayer BUSY が戻らない場合、  
**d#### ms 経過後に強制 PTT OFF**。

*   既定：d20000
*   d0：無効（判定スキップ）

***

5.  トラブルシューティング

● IDが出ない

*   停止中（x）→ r
*   長話（b3900超）→ 抑止
*   D13 点灯中（抑止）では動作しない

● ID が止まらない

*   t1 と r#### を増やす
*   n#### / i#### を大きくする

● 音声が途中で切れる

*   d#### を延長（d20000 など）
*   SDカード階層（/mp3/0001.mp3）を確認
*   D7(BUSY) が途中 HIGH になっていないか

● BUSY判定が逆

*   g0/g1 の設定確認
*   D6 は INPUT\_PULLUP 必須

***

6.  配線メモ（v1.73d）

DFPlayer TX → **D10（Arduino RX）**  
DFPlayer RX ← **D11（Arduino TX）**  
DFPlayer BUSY（LOW=再生中）→ **D7**  
D7ミラー（反転）→ **D2**  
TM BUSY → **D6（g0/g1 で極性指定）**  
PTT → **D5**（HIGH=送信）  
LED → **D4（D6） / D12（A0） / D13（抑止/AUTO）**  
テストSW → **D3（INPUT\_PULLUP）**

***

7.  v1.73d 追加仕様（重要）

【周期ID静寂ガード（k####）】

*   BUSY OFF → **k#### ms** 静寂で周期ID許可
*   BUSY中、静寂不足、抑止期間中は延期
*   `q` で QUIET(ms) を確認可能

【EEPROM バージョン（CONFIG\_VERSION=4）】

*   v1.73c（ver=3）からの更新時、  
    不足項目（periodQuietMs）を 2000ms で補完
*   起動時、自動マイグレーションまたは初期化
*   `EEPROM_VER=4` と表示される

***

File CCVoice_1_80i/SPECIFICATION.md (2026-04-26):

========================================================================
【仕様書（技術者向け）】
========================================================================

1. 基本情報
- 名称     : OpenCCVoice Guidance Controller
- バージョン: v1.80i
- MCU      : Arduino Nano（ATmega328P, 5V）
- 依存     : Arduino.h / SoftwareSerial.h / EEPROM.h / avr/wdt.h
- DFPlayer : BUSY監視（D7=LOW 再生中）、9600bps 制御（固定）
- EEPROM   : CONFIG_VERSION=5（v1.80h から変更なし）
              → v1.73系（ver=4）からの更新時は自動マイグレーションを実施
              → v1.80h からの書き込みは EEPROM 操作不要

========================================================================
2. 機能仕様（Functional）
========================================================================

(1) カーチャンク受信の自動ID送出
  - D6 または A0 の受信継続時間 dur が
      BUSY_MIN_MS（①） ≤ dur < BUSY_MAX_MS（②） のとき、
      トラック1（001）を送出。
  - D6 BUSY は極性切替可能（g0/g1）。
      g0: LOW=受信（アクティブLOW）
      g1: HIGH=受信（アクティブHIGH）
  - DFPlayer BUSY（D7）の戻りは「HIGH連続40ms」で再生完了と判定。
  - PTT シーケンス：
      PRE=j#### ms → 再生 → POST=J#### ms。
      PRE/POST は絶対時刻（pttPreEndAt / pttPostEndAt）で判定する。

(2) 抑止（⑤ busySupUntil 一元管理）
  - 抑止は busySupUntil タイマー一本で管理（常時有効）。
  - 抑止の起点：
      起点A: ④ POST 終了の瞬間（カーチャンクID送出後・受信中でない場合）
      起点B: ② 超え受信（通常会話）の終了の瞬間
      POST 終了時に受信中の場合は起点B が起点A を上書き。
  - 旧来の「長話抑止（longSupUntil）」「連打抑止（burstSupUntil）」
    「送信直後ガード（postTxIgnore）」はすべて廃止し、本タイマーに統合。

(3) AUTO（m2）
  - AUTO_WINDOW（分）観測し、
      D6エッジ数 / A0イベント数の多い側へ自動固定。
  - 固定後 autoLocked=true、EEPROM 保存（再起動後も反映）。
  - AUTO固定時は D13 LED を高速点滅（約3秒）。

(4) 定周期ID（スキップ仕様 — v1.80h 変更、v1.80i 継承）
  - PERIOD_MS ごとにトラック2/3を交互送出。
  - 周期タイミングが到来したとき、以下の全条件を満たした場合のみ送出：
      1) state == IDLE
      2) BUSY == false
      3) (now - lastBusyOffAt) >= PERIOD_QUIET_MS（静寂条件）
      4) 抑止期間外（busySupUntil を経過している）
  - 条件不成立の場合はその回をスキップ（破棄）。
    旧仕様の「延期（periodicDue 保持）」とは異なり、次の定周期タイミングまで待機する。
  - ★注意：スキップ仕様のため、通話が頻繁な環境では送出機会が減少する。
    k#### を短くするか p## の周期を見直すこと。

(5) A0 BUSY観測
  - PTT送出中（pAct=true）は A0 の観測を停止（a0Detect=false, a0Busy=false）。
  - PTT 送出中でない場合は A0 ヒステリシス判定を継続。
  - AUTO 判定用カウント（a0_event_count）は抑止中はインクリメントしない。

(6) EEPROM 永続化
  - n / b / j / J / r / p / k / m / g / L / G / a / w / d
    の変更で即保存。
  - ログレベル（l0〜l3）は EEPROM 保存なし（起動時は常に LOG_MIN）。
  - 起動時ロード時には以下を実施：
      1) magic 不一致 → 初期化（applyDefaults）
      2) ver 不一致 → 自動移行（新規項目補完、不正値補正）
      3) ver=4 からの移行時の補完：
         pttPreMs / pttPostMs を 1000ms で補完
         busyMax が 3900ms の場合のみ 1500ms に更新
         txSupMs が 3000ms の場合のみ 10000ms に更新

(7) LED可視化 / D2ミラー出力
  - D6 LED（D4）: D6 BUSY 表示
  - A0 LED（D12）: A0 BUSY 表示
  - 抑止LED（D13）: ⑤抑止中点灯 / AUTO固定通知（高速点滅）
  - 未使用LEDはゆっくり点滅（待機表示）
  - D2: DFPlayer BUSY ミラー（反転）
        再生中=HIGH、停止中=LOW

(8) フェイルセーフ（PTT張り付き防止）
  - PLAYING突入後、DFPlayer BUSY が戻らない場合、
      設定 d####（既定20000ms）到達で強制 PTT OFF。
  - d0 で無効化（PLAYING内でのチェックスキップ）。

(9) PRE/POST バグ修正（v1.80h）・コード整理（v1.80i）
  - Serial.setTimeout(50) を setup() で一度だけ設定。
  - PTT_ON_WAIT の待機判定を pttPreEndAt（絶対時刻）で行う。
  - PTT_OFF_WAIT の待機判定を pttPostEndAt（絶対時刻）で行う。
  - ブロッキング（parseInt）で now がずれても PRE/POST が確実に保証される。

========================================================================
3. 非機能仕様（Non-Functional）
========================================================================
- 応答性：D6 デバウンス 5ms
- 安定性：DFPlayer BUSY の HIGH確定に 40ms
- ガード：PTT 最低 ON ガード搭載（誤送信防止）
- 可搬性：Arduino IDE 1.8.x / 2.x
- 保守性：
    - printSummary() による状態一覧
      （EEPROM_VER / PRE / POST / SUP / QUIET / BUSY極性 含む）
    - ログレベル選択（l0〜l3）
- 安全性：DFPlayer タイムアウト監視 / ⑤抑止による誤発火防止
- 耐久性：EEPROM 書込みは「値変更時のみ」

========================================================================
4. インタフェース仕様（I/O / 配線）
========================================================================
- D2  : DFPlayer BUSY ミラー出力（反転）… 再生中=HIGH / 停止中=LOW
- D3  : テストSW（INPUT_PULLUP, 1〜3クリックでTRACK1〜3再生）
- D4  : D6系 LED（デジタル受信表示）
- D5  : PTT出力（HIGH=送信）
- D6  : TM BUSY入力（g0/g1で極性可変）
        g0 = LOW=busy（アクティブLOW）
        g1 = HIGH=busy（アクティブHIGH）
- D7  : DFPlayer BUSY入力（LOW=再生中）
- D10 : Arduino RX（← DFPlayer TX）
- D11 : Arduino TX（→ DFPlayer RX）
- D12 : A0 LED（アナログ受信表示）
- D13 : 抑止LED（⑤抑止中・AUTO固定通知）
- A0  : アナログ入力 0..1023（L/G閾値＋保持 a）

========================================================================
5. 既定値（Factory Defaults）
========================================================================
- BUSY_INPUT_SOURCE           = D6
- BUSY_MIN_MS（①）           = 500ms
- BUSY_MAX_MS（②）           = 1500ms
- PTT_PRE_MS（③）            = 1000ms
- PTT_POST_MS（④）           = 1000ms
- TX_SUP_MS（⑤）             = 10000ms
- PERIOD_MS（⑥）             = 30分
- PERIOD_QUIET_MS             = 2000ms
- A0_LOW_TH                   = 300
- A0_HIGH_TH                  = 700
- A0_HOLD                     = 800ms
- AUTO_WINDOW                 = 30分
- D6 デバウンス               = 5ms
- DFP_TIMEOUT_MS              = 20000ms
- TM_BUSY_ACTIVE_HIGH         = true（HIGH=busy）
- CONFIG_VERSION              = 5

========================================================================
6. コマンド仕様（完全）
========================================================================
- n####                … ① 最小受信長（ms）（100〜）
- b####                … ② 最大受信長（ms）（500〜）
- j####                … ③ PTT先行無音時間 PRE（ms）（100〜）★v1.80h新設
- J####                … ④ PTT後行無音時間 POST（ms）（100〜）★v1.80h新設
- r####                … ⑤ 抑止時間（ms）（0〜）
- p##                  … ⑥ 定周期ID（分 / 0=停止）
- k####                … 定周期IDの静寂条件（ms / 0〜600000）
- m0 / m1 / m2         … BUSYソース切替（D6 / A0 / AUTO）
- g0 / g1              … BUSY極性（LOW=busy / HIGH=busy）
- L### / G### / a####  … A0 閾値LOW/HIGH/保持(ms)
- w##                  … AUTO観測窓（分）
- d####                … DFPlayerタイムアウト（ms / 0=無効）
- V                    … バージョン表示（スケッチver + EEPROM_VER）
- q                    … 要約（EEPROM_VER / PRE / POST / SUP / QUIET / POL 含む）
- x                    … 停止（Safe Stop）
- R                    … 復帰（STOP中のみ）★v1.80h変更（旧: r）
- F                    … Factory Reset（初期化＋保存）
- Z                    … ソフトウェアリセット（WDT 15ms / EEPROM変更なし）
- l0 / l1 / l2 / l3   … ログレベル（OFF/MIN/FULL/DBG）★v1.80h変更（旧: 0/1/2/3）
- h                    … コマンド一覧

【廃止されたコマンド（v1.73f1 以前）】
- s0/s1                … 抑止全体 ON/OFF（廃止。抑止は常時有効）
- t0/t1                … 送信後抑止 ON/OFF（廃止。r0 で実質 OFF）
- i####                … 送信直後ガード閾値（廃止。⑤抑止に統合）
- H                    … 汎用プリセット（廃止）
- r（引数なし）        … STOP復帰（廃止。R に変更）
- 0/1/2/3（単体数字）  … ログレベル（廃止。l0〜l3 に変更）

========================================================================
7. 振る舞い仕様（状態遷移 / BUSY判定）
========================================================================
【受信長判定】
- dur < BUSY_MIN_MS              → 無効（ノイズ）
- BUSY_MIN_MS ≤ dur < BUSY_MAX_MS → カーチャンク（001送出候補）
- dur ≥ BUSY_MAX_MS              → 通常会話 → ⑤抑止開始（起点B）

【カーチャンク送出条件】
- pAct == false（PTT送出中でない）
- isSuppressedNow() == false（⑤抑止期間外）
- 上記を満たす場合：busySupUntil = now + TX_SUP_MS をセットし、startPtt(1)

【抑止（⑤ busySupUntil）】
- 起点A: PTT_OFF_WAIT → IDLE 遷移時（受信中でない場合）
    busySupUntil = now + TX_SUP_MS
- 起点B: dur ≥ BUSY_MAX_MS の受信終了時
    busySupUntil = now + TX_SUP_MS
- 受信中に POST が終わった場合: IDLE 遷移時に受信中なら起点B へ委ねる（[SUP] Defer to RX-end ログ）
- isSuppressedNow() : (long)(now - busySupUntil) < 0

【定周期ID（スキップ仕様 — v1.80h 変更、v1.80i 継承）】
- while ループで nextPeriodicAt を未来へ追い付かせ、crossed=true なら送出判定を行う（最大1回）
- crossed=true かつ以下の全条件を満たした場合に送出：
  1) state == IDLE
  2) BUSY == false
  3) (now - lastBusyOffAt) >= PERIOD_QUIET_MS
  4) isSuppressedNow() == false
- 条件不成立 → その回をスキップ（periodicDue は保持しない）

【フェイルセーフ】
- PLAYING →
  (now - playingEnterAt >= d####) → 強制 PTT_OFF_WAIT 遷移
- d0 → 判定スキップ

【PTT状態遷移】
- IDLE → PTT_ON_WAIT（PTT ON、pttPreEndAt = now + PTT_PRE_MS）
       → PLAYING（DFPlayer 再生コマンド送出）
       → PTT_OFF_WAIT（pttPostEndAt = now + PTT_POST_MS）
       → IDLE（PTT OFF。受信中でない場合、⑤抑止開始（起点A））

【V コマンド】
- スケッチバージョン文字列と config.ver を Serial 出力
- 出力例：[VER] OpenCCVoice v1.80i (EEPROM_VER=5)

【Z コマンド：ソフトウェアリセット】
- Serial に "[RESET] Software reset by WDT..." を出力後 delay(100)
- wdt_enable(WDTO_15MS) → while(1) で WDT 発火 → MCU リセット
- EEPROM は変更しない
- PTT 出力中に実行した場合、WDT ハードリセットにより PTT は即解放される

========================================================================
8. 制約
========================================================================
- D6 デバウンス 5ms（固定）
- A0/D6 の同時配線は禁止
- EEPROM 書込みは「値変更時のみ」
- EEPROM 耐久性に配慮（無関係な再書き込みを避ける）
- SRAM：ATmega328P の 2KB 内で動作
- ログレベル（l0〜l3）は EEPROM に保存されない。起動時は常に l1=MIN
- PTT 出力中に Z を実行すると WDT ハードリセットにより PTT が即解放される
- 定周期IDはスキップ仕様のため、通話が頻繁な環境では送出機会が減少する

========================================================================
9. 試験（例）
========================================================================
- D6固定（m0）
  600ms BUSY → カーチャンク→ ID送出
  2000ms BUSY → 通常会話 → ⑤抑止（dur ≥ b1500）

- AUTO：m2 → w1
  → 観測 → AUTO-FIXED → D13高速点滅

- 抑止：r10000
  → カーチャンク送出後 10秒の ⑤ 抑止
  → 同期間内のカーチャンクはスキップ（[RX] CK ... skip(sup remain=####ms)）

- フェイルセーフ：d20000
  → DFPlayer BUSY戻らず 20秒 → 強制 PTT OFF
  → d0 で無効化可能

- 定周期ID（スキップ仕様）
  BUSY OFF → 2秒静寂（k2000）→ 002/003送出
  BUSY中 / 静寂不足 / 抑止中 → スキップ（[Periodic] SKIP reason:...）
  スキップ後は次の定周期タイミングまで待機

- PRE/POST 保証（v1.80h 修正・v1.80i 継承）
  シリアルコマンド受信中でも PRE/POST が確実に保持される（絶対時刻比較）

- BUSY極性
  g0=LOW=busy
  g1=HIGH=busy

- バージョン確認
  V → "[VER] OpenCCVoice v1.80i (EEPROM_VER=5)" を確認

- ソフトウェアリセット
  Z → "[RESET] Software reset by WDT..." → 再起動 → 設定保持を確認
  F → Z → 完全クリーン起動を確認

========================================================================
10. リスク
========================================================================
- DFPlayer BUSY の個体差により再生完了のHIGH時刻に±誤差
- プルアップ不足・配線不良により D6/A0 が不安定になる可能性
- A0/D6 の同時配線は禁止（誤検知の原因）
- BUSY 極性を誤るとカーチャンク/通常会話判定が崩壊する → g0/g1 必ず確認
- 定周期ID静寂時間（k####）を長くしすぎるとスキップが多発する
- PTT 出力中に Z を実行すると PTT が即解放される（意図せず実行しないこと）
- ② MAX（b####）のデフォルト変更（3900ms → 1500ms）により、
  旧バージョンとカーチャンク判定範囲が異なる。運用環境に応じて b#### を再確認すること

========================================================================
11. 付属ドキュメント
========================================================================
- CHANGELOG.md          : バージョン別の変更履歴
- README.md             : コマンドリファレンス・設定値解説
- NOTES_FOR_UPGRADE.md  : アップグレード手順・チェックリスト
- OpenCCVoice_TimingChart.xlsx : タイムチャート
  各挙動（カーチャンクID送出 / 通常会話抑止 / 抑止中スキップ / 定周期ID静寂ガード / PRE/POST保証動作）を
  共通タイムライン（1セル=200ms）で図示。

========================================================================
12. 用語対応表（コード識別子 ↔ ドキュメント表現）
========================================================================

変数名・定数名はコード互換性のため変更せず、ドキュメントおよびコメントのみ
読み替えを行っています。

 コード識別子               | ドキュメント表現
----------------------------|------------------------------
 PIN_TM_BUSY / tmBusy*      | 受信BUSY信号（D6入力）
 TMBUSY_ACTIVE_HIGH         | 受信BUSY信号極性
 busySupUntil               | ⑤抑止終了時刻
 TX_SUP_MS                  | ⑤抑止時間
 PTT_PRE_MS / pttPreEndAt   | ③ PTT先行無音時間（PRE）/ PRE終了予定時刻
 PTT_POST_MS / pttPostEndAt | ④ PTT後行無音時間（POST）/ POST終了予定時刻
 BUSY_MIN_MS                | ① カーチャンク最小受信長
 BUSY_MAX_MS                | ② カーチャンク最大受信長
 PERIOD_QUIET_MS            | 定周期送出前の静寂待機時間
 lastBusyOffAt              | 最後にBUSYがOFFになった時刻（静寂起点）

【v1.73系から削除された識別子（v1.80h/v1.80i 以降は存在しない）】

 コード識別子               | 旧用途
----------------------------|------------------------------
 postTxIgnore               | 送信直後ガードフラグ（⑤抑止に統合）
 postTxIdleStart            | 送信直後ガード解除用計測
 IDLE_MIN_MS / idleMin      | 送信後BUSY安定待ち時間
 BURST_WIN_MS / burstWinStart| 連打検出窓
 BURST_SUP_MS / burstSupUntil| 連打抑止
 BURST_TH / burstCount      | 連打閾値・カウンタ
 LONG_SUP_MS / longSupUntil | 長話抑止（⑤抑止に統合）
 suppressOn                 | 抑止全体ON/OFF
 txAfSupOn                  | 送信後抑止ON/OFF
 SUPPRESSORS_ENABLED        | 抑止全体有効フラグ
 TX_AFTER_SUPPRESS_ENABLED  | 送信後抑止有効フラグ
 stateTimer                 | ステート遷移タイマー（絶対時刻比較に置き換え）
 periodicDue                | 周期ID送出待ちフラグ（スキップ仕様に変更）
 lastTriggerAt              | 最終ID送出時刻（不応期ロジック削除により廃止）
 REFRAC_MS                  | 短発ID不応期（廃止）

========================================================================

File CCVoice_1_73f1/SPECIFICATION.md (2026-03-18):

========================================================================
【仕様書（技術者向け）】
========================================================================

1. 基本情報
- 名称     : OpenCCVoice Guidance Controller
- バージョン: v1.73f1-Unified-Safe
- MCU      : Arduino Nano（ATmega328P, 5V）
- 依存     : Arduino.h / SoftwareSerial.h / EEPROM.h / avr/wdt.h
- DFPlayer : BUSY監視（D7=LOW 再生中）、9600bps 制御（固定）
- EEPROM   : version stamp を導入（CONFIG_VERSION=4）
              → v1.73d/e と同一レイアウト。スケッチ更新のみで移行可。
              → v1.73c 以前からの更新時は自動マイグレーションを実施

========================================================================
2. 機能仕様（Functional）
========================================================================

(1) 短発受信の自動ID送出
  - D6 または A0 の受信継続時間 dur が
      BUSY_MIN_MS ≤ dur < BUSY_MAX_MS のとき、
      トラック1（001）を送出。
  - D6 BUSY は極性切替可能（g0/g1）。
      g0: LOW=受信（アクティブLOW）
      g1: HIGH=受信（アクティブHIGH）
  - DFPlayer BUSY（D7）の戻りは「HIGH連続40ms」で再生完了と判定。
  - PTT シーケンス：
      PRE=1000ms → 再生 → POST=1000ms。

(2) 抑止（長話・連打・送信後・送信直後ガード）
  - 長話抑止      ：dur ≥ BUSY_MAX_MS → LONG_SUP_MS=10s。
  - 連打抑止    ：10秒窓内で短発が2回以上 → BURST_SUP_MS=10s。
  - 送信後抑止    ：t1有効時、TX後 TX_SUP_MS(ms) の受信を無視。
  - 送信直後ガード（★v1.73e）：
      PTT OFF 直後に postTxIgnore=true をセット。
      BUSY が idleMin ms 連続 OFF になるまで 短発・周期ID を抑止扱いにする。
      isSuppressedNow() に統合されており、送信後抑止とは独立して動作。

(3) AUTO（m2）
  - AUTO_WINDOW（分）観測し、
      D6エッジ数 / A0イベント数の多い側へ自動固定。
  - 固定後 autoLocked=true、EEPROM 保存（再起動後も反映）。
  - AUTO固定時は D13 LED を高速点滅（約3秒）。

(4) 周期ID（v1.73d/e 改良版）
  - PERIOD_MS ごとにトラック2/3を交互送出。
  - IDLE時のみ動作。
  - 静寂ガード（v1.73d）：
      「BUSY が OFF になってから periodQuietMs(ms) 静寂継続」の条件を満たす場合のみ送出。
      BUSY中・静寂不足・抑止期間中は送出せず延期（periodicDue保持）。
  - catch-up 対策（★v1.73e）：
      nextPeriodicAt を while で未来へ追い付かせ、periodicDue は最大1回のみ立てる。
      長時間延期後も連続送出しない。

(5) A0 BUSY観測（★v1.73e 改良）
  - 抑止中であっても a0Busy の観測は継続。
  - 抑止中は AUTO 判定用カウント（a0_event_count）のみ増加させない。
  - これにより、抑止解除後の AUTO 判定がずれる問題を解消。

(6) EEPROM 永続化（v1.73c〜）
  - m / n / b / i / p / r / L / G / a / w / s / t / d / g / k
    の変更で即保存。
  - 起動時ロード時には以下を実施：
      1) magic 不一致 → 初期化（applyDefaults）
      2) ver 不一致 → 自動移行（新規項目補完）
      3) 不正値は安全値に補完
         （例：tmBusyActiveHigh=1、dfpTimeoutMs=20000、periodQuietMs=2000）
  - 注意：k0（periodQuietMs=0）は補完ロジックで 2000ms に戻る場合あり。
          再起動後は q で QUIET(ms) を確認すること。

(7) LED可視化 / D2ミラー出力
  - D6 LED（D4）: D6 BUSY 表示
  - A0 LED（D12）: A0 BUSY 表示
  - 抑止LED（D13）: 抑止 / 連打検出窓 / AUTO固定通知
  - 未使用LEDはゆっくり点滅（待機表示）
  - D2: DFPlayer BUSY ミラー（反転）
        再生中=HIGH、停止中=LOW

(8) フェイルセーフ（PTT張り付き防止）
  - PLAYING突入後、DFPlayer BUSY が戻らない場合、
      設定 d####（既定20000ms）到達で強制 PTT OFF。
  - d0 で無効化（PLAYING内でのチェックスキップ）。

========================================================================
3. 非機能仕様（Non-Functional）
========================================================================
- 応答性：D6 デバウンス 5ms
- 安定性：DFPlayer BUSY の HIGH確定に 40ms
- ガード：PTT 最低 ON ガード搭載（誤送信防止）
- 可搬性：Arduino IDE 1.8.x / 2.x
- 保守性：
    - printSummary() による状態一覧
      （EEPROM_VER / QUIET(ms) / BUSY極性 含む）
    - ログレベル選択（0〜3）
- 安全性：DFPlayer タイムアウト監視 / 送信直後ガード（postTxIgnore）
- 耐久性：EEPROM 書込みは「値変更時のみ」

========================================================================
4. インタフェース仕様（I/O / 配線）
========================================================================
- D2  : DFPlayer BUSY ミラー出力（反転）… 再生中=HIGH / 停止中=LOW
- D3  : テストSW（INPUT_PULLUP, 1〜3クリックでTRACK1〜3再生）
- D4  : D6系 LED（デジタル受信表示）
- D5  : PTT出力（HIGH=送信）
- D6  : TM BUSY入力（g0/g1で極性可変）
        g0 = LOW=busy（アクティブLOW）
        g1 = HIGH=busy（アクティブHIGH）
- D7  : DFPlayer BUSY入力（LOW=再生中）
- D10 : Arduino RX（DFPlayer TX）
- D11 : Arduino TX（DFPlayer RX）
- D12 : A0 LED（アナログ受信表示）
- D13 : 抑止LED（抑止・短発・AUTO固定）
- A0  : アナログ入力 0..1023（L/G閾値＋保持 a）

========================================================================
5. 既定値（Factory Defaults）
========================================================================
- BUSY_INPUT_SOURCE           = D6
- BUSY_MIN_MS                 = 500
- BUSY_MAX_MS                 = 3900
- IDLE_MIN_MS                 = 200
- PERIOD_MS                   = 30 min
- TX_SUP_MS                   = 3000
- SUPPRESSORS_ENABLED         = true
- TX_AFTER_SUPPRESS_ENABLED   = true
- A0_LOW_TH                   = 300
- A0_HIGH_TH                  = 700
- A0_HOLD                     = 800
- AUTO_WINDOW                 = 30 min
- D6 デバウンス               = 5ms
- DFP_TIMEOUT_MS              = 20000ms
- TM_BUSY_ACTIVE_HIGH         = true（HIGH=busy）
- periodQuietMs               = 2000ms
- EEPROM_VER                  = 4（CONFIG_VERSION=4、v1.73dと同一）

========================================================================
6. コマンド仕様（完全）
========================================================================
- m0 / m1 / m2         … BUSYソース切替（D6 / A0 / AUTO）
- n####                … 最小受信長（ms）
- b####                … 最大受信長（ms）
- i####                … 送信後BUSY安定待ち時間（ms）/ postTxIgnore解除閾値
- s0 / s1              … 抑止 OFF / ON
- t0 / t1              … 送信後抑止 OFF / ON
- r####                … TX後無視時間（ms）※STOP中は r のみで復帰コマンド
- p##                  … 周期ID（分 / 0=停止）
- k####                … 周期ID静寂時間（ms / 0=無効、再起動後に2000に戻る場合あり）
- w##                  … AUTO観測窓（分）
- L### / G### / a####  … A0 閾値LOW/HIGH/保持(ms)
- d####                … DFPlayerタイムアウト（ms / 0=無効）
- g0 / g1              … TM BUSY極性（LOW=busy / HIGH=busy）
- V                    … バージョン表示（スケッチver + EEPROM_VER）
- q                    … 要約（EEPROM_VER / QUIET(ms) / BUSY_POL含む）
- H                    … 汎用プリセット（s0/t0/b3900）
- x / r                … 停止（Safe Stop）/ 再開（STOP中のみ）
- F                    … Factory Reset（初期化＋保存）
- Z                    … ソフトウェアリセット（WDT 15ms / EEPROM変更なし）
- 0 / 1 / 2 / 3        … ログレベル（NONE / ERR / INF / DBG）

========================================================================
7. 振る舞い仕様（状態遷移 / BUSY判定）
========================================================================
【受信長判定】
- dur < BUSY_MIN_MS              → 無効
- BUSY_MIN_MS ≤ dur < BUSY_MAX_MS → 短発（001送出候補）
- dur ≥ BUSY_MAX_MS              → 長話抑止（10秒）

【短発連続（連打抑止）】
- 10s 窓で短発が2回以上 → BURST_SUP_MS=10秒 抑止

【送信後抑止】
- s1 & t1 → TX後 r#### ms の BUSY を無視

【送信直後ガード（★v1.73e）】
- PTT OFF → postTxIgnore=true
- BUSY が idleMin ms 連続 OFF → postTxIgnore=false（自動解除）
- 解除までの間、isSuppressedNow()=true（短発・周期ID ともに抑止扱い）

【周期ID（v1.73d/e 静寂ガード・catch-up対策付き）】
- while ループで nextPeriodicAt を未来へ追い付かせ、crossed=true なら periodicDue=true（最大1回）
- periodicDue=true かつ state=IDLE のとき、
  次の全条件を満たした場合に送出：
  1) BUSY=false
  2) (now - lastBusyOffAt) ≥ periodQuietMs
  3) 抑止期間外（長話/連打/送信後/送信直後ガード）
- 条件不成立 → periodicDue を保持（延期）

【フェイルセーフ】
- PLAYING →
  (now - playingEnterAt ≥ d####) → 強制 PTT OFF
- d0 → 判定スキップ

【PTT状態遷移】
- IDLE → PTT_ON_WAIT（PRE）
       → PLAYING
       → PTT_OFF_WAIT（POST）
       → IDLE（★postTxIgnore=true をセット）

【V コマンド】
- スケッチバージョン文字列と config.ver を Serial 出力
- 出力例：[VER] OpenCCVoice v1.73f1 (EEPROM_VER=4)

【Z コマンド：ソフトウェアリセット】
- Serial に "[RESET] Software reset by WDT..." を出力後 delay(100)
- wdt_enable(WDTO_15MS) → while(1) で WDT 発火 → MCU リセット
- EEPROM は変更しない
- PTT 出力中に実行した場合、WDT ハードリセットにより PTT は即解放される

========================================================================
8. 制約
========================================================================
- D6 デバウンス 5ms（固定）
- A0/D6 の同時配線は禁止
- EEPROM 書込みは「値変更時のみ」
- EEPROM耐久性に配慮（無関係な再書き込みを避ける）
- SRAM：ATmega328P の 2KB 内で動作
- k0（periodQuietMs=0）は再起動後に 2000ms に補完される場合がある（既知）
- PTT 出力中に Z を実行すると WDT ハードリセットにより PTT が即解放される

========================================================================
9. 試験（例）
========================================================================
- D6固定（m0）
  600ms BUSY → ID送出
  4000ms BUSY → 長話抑止

- AUTO：m2 → w1
  → 観測 → AUTO-FIXED → D13高速点滅

- 送信後抑止：t1 / r3000
  → 自局送出後 3s の BUSY を無視

- フェイルセーフ：d20000
  → DFPlayer BUSY戻らず20秒 → 強制PTT OFF
  → d0 で無効化可能

- 周期ID（v1.73d/e）
  BUSY OFF → 2秒静寂 → 002/003送出
  BUSY中/静寂不足 → 延期

- 送信直後ガード（v1.73e）
  PTT OFF後に A0 残留BUSY発生 → postTxIgnore 中は ID 送出なし
  BUSY が idleMin ms 連続 OFF → ガード解除
  ログレベル 3 で "[POST-TX] cleared by idle-stable" を確認

- catch-up 対策（v1.73e）
  長時間 BUSY 後に周期ID 解除 → 最大1回のみ送出
  ログレベル 3 で "[Periodic] due flag set (catch-up)" を確認

- TM BUSY極性
  g0=LOW=busy
  g1=HIGH=busy

- バージョン確認（v1.73f1）
  V → "[VER] OpenCCVoice v1.73f1 (EEPROM_VER=4)" を確認

- ソフトウェアリセット（v1.73f）
  Z → "[RESET] Software reset by WDT..." → 再起動 → 設定保持を確認
  F → Z → 完全クリーン起動を確認

========================================================================
10. リスク
========================================================================
- DFPlayer BUSY の個体差により再生完了のHIGH時刻に±誤差
- プルアップ不足・配線不良により D6/A0 が不安定になる可能性
- A0/D6 の同時配線は禁止（誤検知の原因）
- 受信BUSY信号（TM BUSY）の極性を誤ると短発/長話判定が崩壊する → g0/g1 必ず確認
- 周期ID静寂時間（k####）を短くしすぎると割り込み感が戻る
- k0 設定後の再起動で periodQuietMs が 2000ms に補完される場合がある（既知）
- PTT 出力中に Z を実行すると PTT が即解放される（意図せず実行しないこと）

========================================================================
11. 付属ドキュメント
========================================================================
- CHANGELOG.md          : バージョン別の変更履歴
- README.md             : コマンドリファレンス・設定値解説
- NOTES_FOR_UPGRADE.md  : アップグレード手順・チェックリスト
- OpenCCVoice_TimingChart.xlsx : タイムチャート
  各挙動（短発ID送出 / 長話抑止 / 連打抑止 / 送信直後ガード / 周期ID静寂ガード）を
  共通タイムライン（1セル=200ms）で図示。①〜⑳の番号解説付き。

========================================================================

========================================================================
12. 用語対応表（コード識別子 ↔ ドキュメント表現）
========================================================================

変数名・定数名はコード互換性のため変更せず、ドキュメントおよびコメントのみ
読み替えを行っています。詳細な変更履歴は CHANGELOG.md 付録を参照。

 コード識別子               | ドキュメント表現
----------------------------|------------------------------
 PIN_TM_BUSY / tmBusy*      | 受信BUSY信号（D6入力）
 TMBUSY_ACTIVE_HIGH         | 受信BUSY信号極性
 BURST_WIN_MS / burstWin*   | 連打検出窓
 BURST_SUP_MS / burstSup*   | 連打抑止
 BURST_TH / burstCount      | 連打閾値 / 連打カウンタ
 postTxIgnore               | 送信直後ガード
 postTxIdleStart            | 送信直後ガード解除用BUSY安定計測
 idleMin / IDLE_MIN_MS      | 送信後BUSY安定待ち時間

========================================================================

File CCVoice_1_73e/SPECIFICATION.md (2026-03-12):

========================================================================
【仕様書（技術者向け）】
========================================================================

1. 基本情報
- 名称     : OpenCCVoice Guidance Controller
- バージョン: v1.73e-Unified-Safe
- MCU      : Arduino Nano（ATmega328P, 5V）
- 依存     : Arduino.h / SoftwareSerial.h / EEPROM.h
- DFPlayer : BUSY監視（D7=LOW 再生中）、9600bps 制御（固定）
- EEPROM   : version stamp を導入（CONFIG_VERSION=4）
              → v1.73d と同一レイアウト。スケッチ更新のみで移行可。
              → v1.73c 以前からの更新時は自動マイグレーションを実施

========================================================================
2. 機能仕様（Functional）
========================================================================

(1) 短発受信の自動ID送出
  - D6 または A0 の受信継続時間 dur が
      BUSY_MIN_MS ≤ dur < BUSY_MAX_MS のとき、
      トラック1（001）を送出。
  - D6 BUSY は極性切替可能（g0/g1）。
      g0: LOW=受信（アクティブLOW）
      g1: HIGH=受信（アクティブHIGH）
  - DFPlayer BUSY（D7）の戻りは「HIGH連続40ms」で再生完了と判定。
  - PTT シーケンス：
      PRE=1000ms → 再生 → POST=1000ms。

(2) 抑止（長話・バースト・送信後・送信直後ガード）
  - 長話抑止      ：dur ≥ BUSY_MAX_MS → LONG_SUP_MS=10s。
  - バースト抑止  ：10秒窓内で短発が2回以上 → BURST_SUP_MS=10s。
  - 送信後抑止    ：t1有効時、TX後 TX_SUP_MS(ms) の受信を無視。
  - 送信直後ガード（★v1.73e）：
      PTT OFF 直後に postTxIgnore=true をセット。
      BUSY が idleMin ms 連続 OFF になるまで 短発・周期ID を抑止扱いにする。
      isSuppressedNow() に統合されており、送信後抑止とは独立して動作。

(3) AUTO（m2）
  - AUTO_WINDOW（分）観測し、
      D6エッジ数 / A0イベント数の多い側へ自動固定。
  - 固定後 autoLocked=true、EEPROM 保存（再起動後も反映）。
  - AUTO固定時は D13 LED を高速点滅（約3秒）。

(4) 周期ID（v1.73d/e 改良版）
  - PERIOD_MS ごとにトラック2/3を交互送出。
  - IDLE時のみ動作。
  - 静寂ガード（v1.73d）：
      「BUSY が OFF になってから periodQuietMs(ms) 静寂継続」の条件を満たす場合のみ送出。
      BUSY中・静寂不足・抑止期間中は送出せず延期（periodicDue保持）。
  - catch-up 対策（★v1.73e）：
      nextPeriodicAt を while で未来へ追い付かせ、periodicDue は最大1回のみ立てる。
      長時間延期後も連続送出しない。

(5) A0 BUSY観測（★v1.73e 改良）
  - 抑止中であっても a0Busy の観測は継続。
  - 抑止中は AUTO 判定用カウント（a0_event_count）のみ増加させない。
  - これにより、抑止解除後の AUTO 判定がずれる問題を解消。

(6) EEPROM 永続化（v1.73c〜）
  - m / n / b / i / p / r / L / G / a / w / s / t / d / g / k
    の変更で即保存。
  - 起動時ロード時には以下を実施：
      1) magic 不一致 → 初期化（applyDefaults）
      2) ver 不一致 → 自動移行（新規項目補完）
      3) 不正値は安全値に補完
         （例：tmBusyActiveHigh=1、dfpTimeoutMs=20000、periodQuietMs=2000）
  - 注意：k0（periodQuietMs=0）は補完ロジックで 2000ms に戻る場合あり。
          再起動後は q で QUIET(ms) を確認すること。

(7) LED可視化 / D2ミラー出力
  - D6 LED（D4）: D6 BUSY 表示
  - A0 LED（D12）: A0 BUSY 表示
  - 抑止LED（D13）: 抑止 / バースト窓 / AUTO固定通知
  - 未使用LEDはゆっくり点滅（待機表示）
  - D2: DFPlayer BUSY ミラー（反転）
        再生中=HIGH、停止中=LOW

(8) フェイルセーフ（PTT張り付き防止）
  - PLAYING突入後、DFPlayer BUSY が戻らない場合、
      設定 d####（既定20000ms）到達で強制 PTT OFF。
  - d0 で無効化（PLAYING内でのチェックスキップ）。

========================================================================
3. 非機能仕様（Non-Functional）
========================================================================
- 応答性：D6 デバウンス 5ms
- 安定性：DFPlayer BUSY の HIGH確定に 40ms
- ガード：PTT 最低 ON ガード搭載（誤送信防止）
- 可搬性：Arduino IDE 1.8.x / 2.x
- 保守性：
    - printSummary() による状態一覧
      （EEPROM_VER / QUIET(ms) / BUSY極性 含む）
    - ログレベル選択（0〜3）
- 安全性：DFPlayer タイムアウト監視 / 送信直後ガード（postTxIgnore）
- 耐久性：EEPROM 書込みは「値変更時のみ」

========================================================================
4. インタフェース仕様（I/O / 配線）
========================================================================
- D2  : DFPlayer BUSY ミラー出力（反転）… 再生中=HIGH / 停止中=LOW
- D3  : テストSW（INPUT_PULLUP, 1〜3クリックでTRACK1〜3再生）
- D4  : D6系 LED（デジタル受信表示）
- D5  : PTT出力（HIGH=送信）
- D6  : TM BUSY入力（g0/g1で極性可変）
        g0 = LOW=busy（アクティブLOW）
        g1 = HIGH=busy（アクティブHIGH）
- D7  : DFPlayer BUSY入力（LOW=再生中）
- D10 : Arduino RX（DFPlayer TX）
- D11 : Arduino TX（DFPlayer RX）
- D12 : A0 LED（アナログ受信表示）
- D13 : 抑止LED（抑止・短発・AUTO固定）
- A0  : アナログ入力 0..1023（L/G閾値＋保持 a）

========================================================================
5. 既定値（Factory Defaults）
========================================================================
- BUSY_INPUT_SOURCE           = D6
- BUSY_MIN_MS                 = 500
- BUSY_MAX_MS                 = 3900
- IDLE_MIN_MS                 = 200
- PERIOD_MS                   = 30 min
- TX_SUP_MS                   = 3000
- SUPPRESSORS_ENABLED         = true
- TX_AFTER_SUPPRESS_ENABLED   = true
- A0_LOW_TH                   = 300
- A0_HIGH_TH                  = 700
- A0_HOLD                     = 800
- AUTO_WINDOW                 = 30 min
- D6 デバウンス               = 5ms
- DFP_TIMEOUT_MS              = 20000ms
- TM_BUSY_ACTIVE_HIGH         = true（HIGH=busy）
- periodQuietMs               = 2000ms
- EEPROM_VER                  = 4（CONFIG_VERSION=4、v1.73dと同一）

========================================================================
6. コマンド仕様（完全）
========================================================================
- m0 / m1 / m2         … BUSYソース切替（D6 / A0 / AUTO）
- n####                … 最小受信長（ms）
- b####                … 最大受信長（ms）
- i####                … 直前アイドル時間（ms）/ postTxIgnore 解除閾値も兼ねる
- s0 / s1              … 抑止 OFF / ON
- t0 / t1              … 送信後抑止 OFF / ON
- r####                … TX後無視時間（ms）※STOP中は r のみで復帰コマンド
- p##                  … 周期ID（分 / 0=停止）
- k####                … 周期ID静寂時間（ms / 0=無効、再起動後に2000に戻る場合あり）
- w##                  … AUTO観測窓（分）
- L### / G### / a####  … A0 閾値LOW/HIGH/保持(ms)
- d####                … DFPlayerタイムアウト（ms / 0=無効）
- g0 / g1              … TM BUSY極性（LOW=busy / HIGH=busy）
- q                    … 要約（EEPROM_VER / QUIET(ms) / BUSY_POL含む）
- H                    … 汎用プリセット（s0/t0/b3900）
- x / r                … 停止（Safe Stop）/ 再開（STOP中のみ）
- F                    … Factory Reset（初期化＋保存）
- 0 / 1 / 2 / 3        … ログレベル（NONE / ERR / INF / DBG）

========================================================================
7. 振る舞い仕様（状態遷移 / BUSY判定）
========================================================================
【受信長判定】
- dur < BUSY_MIN_MS              → 無効
- BUSY_MIN_MS ≤ dur < BUSY_MAX_MS → 短発（001送出候補）
- dur ≥ BUSY_MAX_MS              → 長話抑止（10秒）

【短発連続（バースト抑止）】
- 10s 窓で短発が2回以上 → BURST_SUP_MS=10秒 抑止

【送信後抑止】
- s1 & t1 → TX後 r#### ms の BUSY を無視

【送信直後ガード（★v1.73e）】
- PTT OFF → postTxIgnore=true
- BUSY が idleMin ms 連続 OFF → postTxIgnore=false（自動解除）
- 解除までの間、isSuppressedNow()=true（短発・周期ID ともに抑止扱い）

【周期ID（v1.73d/e 静寂ガード・catch-up対策付き）】
- while ループで nextPeriodicAt を未来へ追い付かせ、crossed=true なら periodicDue=true（最大1回）
- periodicDue=true かつ state=IDLE のとき、
  次の全条件を満たした場合に送出：
  1) BUSY=false
  2) (now - lastBusyOffAt) ≥ periodQuietMs
  3) 抑止期間外（長話/バースト/送信後/送信直後ガード）
- 条件不成立 → periodicDue を保持（延期）

【フェイルセーフ】
- PLAYING →
  (now - playingEnterAt ≥ d####) → 強制 PTT OFF
- d0 → 判定スキップ

【PTT状態遷移】
- IDLE → PTT_ON_WAIT（PRE）
       → PLAYING
       → PTT_OFF_WAIT（POST）
       → IDLE（★postTxIgnore=true をセット）

========================================================================
8. 制約
========================================================================
- D6 デバウンス 5ms（固定）
- A0/D6 の同時配線は禁止
- EEPROM 書込みは「値変更時のみ」
- EEPROM耐久性に配慮（無関係な再書き込みを避ける）
- SRAM：ATmega328P の 2KB 内で動作
- k0（periodQuietMs=0）は再起動後に 2000ms に補完される場合がある

========================================================================
9. 試験（例）
========================================================================
- D6固定（m0）
  600ms BUSY → ID送出
  4000ms BUSY → 長話抑止

- AUTO：m2 → w1
  → 観測 → AUTO-FIXED → D13高速点滅

- 送信後抑止：t1 / r3000
  → 自局送出後 3s の BUSY を無視

- フェイルセーフ：d20000
  → DFPlayer BUSY戻らず20秒 → 強制PTT OFF
  → d0 で無効化可能

- 周期ID（v1.73d/e）
  BUSY OFF → 2秒静寂 → 002/003送出
  BUSY中/静寂不足 → 延期

- 送信直後ガード（★v1.73e）
  PTT OFF後に A0 残留BUSY発生 → postTxIgnore 中は ID 送出なし
  BUSY が idleMin ms 連続 OFF → ガード解除
  ログレベル 3 で "[POST-TX] cleared by idle-stable" を確認

- catch-up 対策（★v1.73e）
  長時間 BUSY 後に周期ID 解除 → 最大1回のみ送出
  ログレベル 3 で "[Periodic] due flag set (catch-up)" を確認

- TM BUSY極性
  g0=LOW=busy
  g1=HIGH=busy

========================================================================
10. リスク
========================================================================
- DFPlayer BUSY の個体差により再生完了のHIGH時刻に±誤差
- プルアップ不足・配線不良により D6/A0 が不安定になる可能性
- A0/D6 の同時配線は禁止（誤検知の原因）
- TM BUSY 極性を誤ると短発/長話判定が崩壊する → g0/g1 必ず確認
- 周期ID静寂時間（k####）を短くしすぎると割り込み感が戻る
- k0 設定後の再起動で periodQuietMs が 2000ms に補完される場合がある（既知）

========================================================================
11. 変更履歴
========================================================================
- 詳細は CHANGELOG.md を参照

========================================================================

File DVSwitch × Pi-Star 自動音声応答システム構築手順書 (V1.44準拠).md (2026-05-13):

# DVSwitch × Pi-Star 自動音声応答システム構築手順書 (V1.44準拠)

DVSwitchとPi-Starを連携させ、Open JTalkによる高品質な音声合成を用いた「自動音声応答システム」の構築手順をまとめたドキュメントです。

このシステムは、無線機からのカーチャンク（短時間の送信）を検知し、適切な「間（ま）」を置いた後に、相手のコールサインを読み上げて応答する **「CCVoice」** のロジックを継承しています。

---

## 概要

| 項目 | 内容 |
|---|---|
| 対象環境 | Pi-Star / WPSD |
| 音声合成エンジン | Open JTalk |
| 音声モデル | MMDAgent「メイ」(mei_normal.htsvoice) |
| 連携方式 | DVSwitch Analog_Bridge (USRP) への UDP 音声注入 |
| 音声フォーマット | 8000Hz / 16bit / モノラル |
| メインスクリプト | `dvswitch_bot.py` (V1.44) |

---

## 1. システムの準備と書き込み可能モードへの移行

Pi-Star環境はデフォルトで書き込み制限がかかっているため、設定変更の前に書き込み可能モードに移行する必要があります。

まずはファイルシステムを書き込み可能にし、必要なパッケージ（Open JTalk, SoX, unzip）をインストールします。

```bash
# 書き込み可能モードへ変更
rpi-rw

# パッケージリストの更新と必要なソフトのインストール
sudo apt-get update
sudo apt-get install -y open-jtalk open-jtalk-mecab-naist-jdic sox unzip
```

### 確認事項

- ターミナルのプロンプトが `(rw)` になっていること
- `md380-emu`（ソフトウェアAMBE）および `Analog_Bridge` が稼働していること

---

## 2. 高品質音声モデル（メイ）の導入

標準の音声よりも流暢な「メイ（MMDAgent）」モデルを導入し、読み上げの質を向上させます。
MMDAgentの公式サイトからデータをダウンロードし、所定のディレクトリに配置します。

```bash
# 一時ディレクトリに移動
cd /tmp

# MMDAgentのサンプルデータをダウンロード
wget https://sourceforge.net/projects/mmdagent/files/MMDAgent_Example/MMDAgent_Example-1.8/MMDAgent_Example-1.8.zip

# 解凍して音声モデルを取り出す
unzip MMDAgent_Example-1.8.zip
sudo mkdir -p /usr/share/hts-voice/mei
sudo cp MMDAgent_Example-1.8/Voice/mei/mei_normal.htsvoice /usr/share/hts-voice/mei/

# ゴミ掃除（不要になったZIPファイルや展開ディレクトリを削除）
rm -rf MMDAgent_Example-1.8.zip MMDAgent_Example-1.8
```

---

## 3. DVSwitch (Analog_Bridge) の設定変更と再起動

PythonスクリプトからのUDP音声パケットを受け入れるため、設定ファイルを編集します。

```bash
# 設定ファイルをエディタ(nano)で開く
sudo nano /opt/Analog_Bridge/Analog_Bridge.ini
```

### nanoエディタでの編集内容

`[USRP]` セクションを探し、以下のように書き換えます（※自己ループと致命的エラーを回避します）。

```ini
[USRP]
rxPort = 51000
txPort = 51001
;jitterQueueSize = 30  ← 先頭に「;」をつけてコメントアウト
;pcmBufferMS = 200     ← 先頭に「;」をつけてコメントアウト
```

> **保存方法:** `Ctrl+O` → `Enter` で保存し、`Ctrl+X` で閉じます

### 設定のポイント

- **ポート設定:** `rxPort` を `51000` に、`txPort` を `51001` に設定し、自己ループを防止
- **互換性調整:** バージョンによっては `jitterQueueSize` や `pcmBufferMS` が存在するとエラーで停止するため、行頭に `;` を付けてコメントアウト

### サービスの再起動

```bash
# 変更を反映してAnalog_Bridgeを再起動
sudo systemctl restart Analog_Bridge
```

設定反映後、Analog_Bridge が正常に起動することを確認してください。

---

## 4. システムディレクトリの作成と固定WAVの生成

応答速度を上げるため、メッセージの固定部分はあらかじめWAVファイルとして作成しておく **「ハイブリッド方式」** を採用します。

毎回計算すると遅延になる「前後の定型文」を、予めDVSwitch仕様（8000Hz/16bit/モノラル）のWAVとして作成しておきます。
ここでは以下のパラメータを適用しています:

| パラメータ | 値 | 効果 |
|---|----|---|
| `-r 0.85` | スピード | ゆっくりめの読み上げ |
| `-fm 1.3` | ピッチ | 少し高めの声 |
| `highpass 300` | フィルタ | 低域ノイズの除去 |
| `vol 1.5` | 音量 | 音量最適化 |

### ディレクトリ作成

```bash
# ボット用のディレクトリを作成
sudo mkdir -p /opt/dvswitch_bot
sudo chown pi-star:pi-star /opt/dvswitch_bot
cd /opt/dvswitch_bot
```

### 固定WAVの生成

#### 1. 前半部分（fixed_start.wav）の生成

「こちらはJJ2YYK尾張旭DMRデジピーターです」

```bash
echo "こちらは、ジェイジェイツーワイワイケー、おわりあさひディーエムアールデジピーターです" | open_jtalk -x /var/lib/mecab/dic/open-jtalk/naist-jdic -m /usr/share/hts-voice/mei/mei_normal.htsvoice -r 0.85 -fm 1.3 -ow /tmp/start_48k.wav
sudo sox /tmp/start_48k.wav -r 8000 -c 1 -b 16 /opt/dvswitch_bot/fixed_start.wav highpass 300 vol 1.5
```

#### 2. 後半部分（fixed_end.wav）の生成

「局からのカーチャンクです」

```bash
echo "局からのカーチャンクです" | open_jtalk -x /var/lib/mecab/dic/open-jtalk/naist-jdic -m /usr/share/hts-voice/mei/mei_normal.htsvoice -r 0.85 -fm 1.3 -ow /tmp/end_48k.wav
sudo sox /tmp/end_48k.wav -r 8000 -c 1 -b 16 /opt/dvswitch_bot/fixed_end.wav highpass 300 vol 1.5
```

> **ヒント:** 読み上げの「間」を開けたい場合は、`echo` の中の文章に「読点（、）」を追加して再度上のコマンドを実行すれば上書きされます。

---

## 5. メインプログラムの配置と読み取り専用モードへの復帰

最後にPythonスクリプト（`dvswitch_bot.py`）を `/opt/dvswitch_bot/` の中に配置し、システムを保護状態に戻します。

```bash
# (ここに dvswitch_bot.py を nano 等で作成/配置します)
sudo nano /opt/dvswitch_bot/dvswitch_bot.py

# 実行権限を付与
sudo chmod +x /opt/dvswitch_bot/dvswitch_bot.py

# システムを読み取り専用（安全な状態）に戻す
rpi-ro
```

### dvswitch_bot.py の主な機能 (V1.44)

| 機能 | 内容 |
|---|---|
| **PRE/POST 無音パケット** | 送信の前後 2.0 秒間に無音データを送出し、無線機の頭切れを完全に防止 |
| **受信時間フィルタ** | 0.5 秒〜1.5 秒の受信のみに反応し、ノイズや長時間の会話への誤反応を防止 |
| **20秒の抑止期間** | 送信終了後 20 秒間は、同じ局に対して二重に応答しないよう制限 |
| **ハイブリッド音声合成** | 固定WAV + 動的TTS（コールサイン読み上げ）を組み合わせて応答速度を向上 |

---

## 手動での起動テスト

動作テストを行う場合は、以下のコマンドで直接起動し、ログを画面で見ながら無線機でカーチャンクしてみてください。

```bash
python3 /opt/dvswitch_bot/dvswitch_bot.py
```

---

## 動作の流れ

```
[無線機] カーチャンク送信 (0.5〜1.5秒)
    ↓
[Pi-Star] 受信検知
    ↓
[dvswitch_bot.py] 受信時間フィルタ判定
    ↓
[応答シーケンス開始]
    ├─ PRE 無音パケット (2.0秒) ── 頭切れ防止
    ├─ fixed_start.wav 再生 ──── 「こちらはJJ2YYK尾張旭…」
    ├─ 動的TTS再生 ───────── コールサイン読み上げ
    ├─ fixed_end.wav 再生 ───── 「局からのカーチャンクです」
    └─ POST 無音パケット (2.0秒) ─ 尻切れ防止
    ↓
[20秒抑止期間] 同一局への二重応答を防止
```

---

## トラブルシューティング

| 症状 | 確認ポイント |
|---|---|
| 音声が再生されない | `Analog_Bridge.ini` のポート設定 (`rxPort=51000`, `txPort=51001`) |
| Analog_Bridge が起動しない | `jitterQueueSize` / `pcmBufferMS` がコメントアウトされているか |
| 頭切れ・尻切れが発生 | PRE/POST 無音パケットの秒数調整 |
| 読み上げが不自然 | `echo` 内のカタカナ表記・読点（、）の追加 |
| 設定ファイルが保存できない | `rpi-rw` で書き込み可能モードに切替済みか |

---

## 作業完了後の重要事項

> ⚠️ **必ず読み取り専用モードに戻すこと**
>
> 作業完了後は、`rpi-ro` コマンドでシステムを読み取り専用モードに戻してください。
> 書き込み可能モードのままだとSDカードの寿命を縮め、突然の電源断によるファイルシステム破損のリスクが高まります。

```bash
rpi-ro
```

---

*Document Version: V1.44 準拠 / Pi-Star・WPSD 環境対応*

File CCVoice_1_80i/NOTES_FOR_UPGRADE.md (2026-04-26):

# OpenCCVoice Guidance Controller  
# アップグレード注意点（〜v1.80i）
# 最終更新日: 2026-03-24

本書は、OpenCCVoice を **v1.80i** にアップグレードする際の  
重要な注意点・確認手順をまとめた技術者向けドキュメントです。  
特に **v1.73f1 / v1.80h 系** からの更新時にご確認ください。

--------------------------------------------------------------------

## 1. v1.80i の概要

v1.80i は v1.80h のコード整理版です。EEPROM CONFIG_VERSION は 5 のまま変更なし。
v1.80h からの書き込みは EEPROM 操作不要です。v1.73f1 以前からは自動マイグレーションが実行されます。

### v1.80h → v1.80i の変更点

| 項目 | 内容 |
|---|---|
| カーチャンク時の busySupUntil | 二重セットを修正。起点A（POST終了）に一本化 |
| ver=3 以前からのマイグレーション | pttPreMs / pttPostMs の不定値リスクを修正 |
| handleStoppedState() | 内部のデッドコード（Serial.read ブロック）を削除 |
| コメント | 旧用語・内部開発版番号を修正 |
| EEPROM CONFIG_VERSION | 5（変更なし） |

### v1.73f1 → v1.80i（v1.80h）の主な変更点

| 項目 | v1.73f1 | v1.80i |
|---|---|---|
| EEPROM CONFIG_VERSION | 4 | 5 |
| ② MAX（b）デフォルト | 3900ms | 1500ms |
| ⑤ 抑止時間（r）デフォルト | 3000ms | 10000ms |
| PRE 時間の制御 | 固定 1000ms（コマンド不可） | `j####` で可変（EEPROM保存） |
| POST 時間の制御 | 固定 1000ms（コマンド不可） | `J####` で可変（EEPROM保存） |
| 連打抑止（BURST） | あり | 廃止（⑤抑止に統合） |
| 送信直後ガード（postTxIgnore） | あり | 廃止（⑤抑止に統合） |
| `s0/s1` コマンド（抑止 ON/OFF） | あり | 廃止（常時有効） |
| `t0/t1` コマンド（送信後抑止 ON/OFF） | あり | 廃止（r0 で実質 OFF） |
| `i####` コマンド（送信直後ガード閾値） | あり | 廃止 |
| `H` コマンド（汎用プリセット） | あり | 廃止 |
| STOP 復帰コマンド | `r` | `R`（大文字） |
| ログレベルコマンド | `0/1/2/3` | `l0/l1/l2/l3` |
| 定周期ID 条件不成立時 | 延期（periodicDue 保持） | スキップ（破棄） |

--------------------------------------------------------------------

## 2. EEPROM の扱い（v1.73f1 / v1.80h → v1.80i）

### ● v1.80h からのアップグレード

v1.80h → v1.80i は EEPROM CONFIG_VERSION が変わらないため、マイグレーションは実行されません。

```
[EEPROM] Settings Loaded.
[START] OpenCCVoice v1.80i
[LOG] MIN (l1=min l2=full l3=dbg l0=off)
```

### ● v1.73系（ver=4）からのアップグレード

v1.73系からスケッチを書き込むと、起動時に自動マイグレーションが実行されます。

| 処理 | 内容 |
|---|---|
| `pttPreMs` / `pttPostMs` を補完 | 1000ms で補完 |
| `busyMax` が旧デフォルト（3900ms）の場合のみ | 1500ms に更新 |
| `txSupMs` が旧デフォルト（3000ms）の場合のみ | 10000ms に更新 |
| `periodQuietMs` が 0 または異常値の場合 | 2000ms に補完 |
| `tmBusyActiveHigh` が不正値の場合 | 1（HIGH=busy）に補完 |
| `dfpTimeoutMs` が 600000 超の場合 | 20000ms に補完 |
| `pttPreMs` / `pttPostMs` が範囲外（100〜5000 外）の場合 | 1000ms に補正 |

> **注意**: `busyMax` と `txSupMs` のマイグレーション更新は「旧デフォルト値と一致する場合のみ」行われます。意図的に旧デフォルト以外の値（例：b2000、r5000）に設定していた場合は、その値がそのまま引き継がれます。

### ● 起動時の想定ログ

v1.73系（ver=4）からの更新時：
```
[EEPROM] Version mismatch: stored=4 expected=5
[EEPROM] Migration done.
[EEPROM] Settings Loaded.
[START] OpenCCVoice v1.80i
[LOG] MIN (l1=min l2=full l3=dbg l0=off)
```

初回起動またはデータ破損時：
```
[EEPROM] No/Other Data. Init defaults.
[EEPROM] Settings Loaded.
[START] OpenCCVoice v1.80i
[LOG] MIN (l1=min l2=full l3=dbg l0=off)
```

### ● 起動後に必ず実行すべき確認

`V` を入力してバージョンを確認：
```
[VER] OpenCCVoice v1.80i (EEPROM_VER=5)
```

`q` を入力して設定を確認：
```
[CFG] EEPROM_VER=5 SRC=D6 MIN=500 MAX=1500 PRE=1000 POST=1000 SUP=10000 PER(min)=30 QUIET(ms)=2000 A0[L/H]=300/700 HOLD=800 AUTO(min)=30 DFP_TO=20000 POL=HIGH=busy
```

チェックポイント：
- `EEPROM_VER=5`（正常）
- `MAX=1500`（マイグレーション後の新デフォルト、または意図した値）
- `SUP=10000`（マイグレーション後の新デフォルト、または意図した値）
- `PRE=1000` / `POST=1000`（補完値、または意図した値）
- BUSY 極性が無線機仕様に一致（g0/g1）
- 定周期間隔が意図した値

--------------------------------------------------------------------

## 3. 「F（Factory Reset）」は必要か？

### ● 原則：不要

自動マイグレーションが正常に機能するため、通常は F 不要です。

### ● 以下の場合は F を推奨

- v1.69 系以前から一気に更新した
- 過去に手動で不正な値を設定した
- 今回を機に完全にクリーンな状態にしたい
- 起動ログに異常値補正が多数出た場合

実行手順：
```
F
q
```

--------------------------------------------------------------------

## 4. v1.73系から変わった操作コマンドの一覧

### ● 廃止されたコマンド（v1.73f1 → v1.80h）

以下のコマンドは v1.80h で廃止されました。入力しても反応しません（unknown として無視されます）。

| 廃止コマンド | 旧機能 | v1.80h での代替 |
|---|---|---|
| `s0/s1` | 抑止全体 ON/OFF | 廃止（抑止は常時有効）。実質OFFは `r0` |
| `t0/t1` | 送信後抑止 ON/OFF | 廃止。`r0` で送信後抑止を実質無効化 |
| `i####` | 送信直後ガード閾値 | 廃止（⑤抑止に統合） |
| `H` | 汎用プリセット（s0/t0/b3900） | 廃止 |
| `r`（引数なし） | STOP 復帰 | `R`（大文字）に変更 |
| `0/1/2/3`（単体数字） | ログレベル | `l0/l1/l2/l3` に変更 |

### ● 変更されたコマンド

| コマンド | v1.73f1 | v1.80h |
|---|---|---|
| STOP 復帰 | `r`（引数なし） | `R`（大文字） |
| ログレベル | `0/1/2/3` | `l0/l1/l2/l3` |

### ● 追加されたコマンド

| コマンド | 機能 | デフォルト |
|---|---|---|
| `j####` | ③ PTT先行無音時間 PRE（ms） | 1000ms |
| `J####` | ④ PTT後行無音時間 POST（ms） | 1000ms |

--------------------------------------------------------------------

## 5. 動作仕様の変更点と影響

### ● ② MAX（b）デフォルト変更（3900ms → 1500ms）

v1.73f1 では 3900ms がデフォルトでしたが、v1.80h では 1500ms に変更されました。

マイグレーション時：旧デフォルトの 3900ms で使用していた場合は 1500ms に自動更新されます。
意図的に 3900ms 以外（例：b5000）を設定していた場合はその値が保持されます。

**影響**：1500ms〜3900ms の受信が、旧仕様では「カーチャンク（ID送出）」でしたが、新仕様では「通常会話（⑤抑止）」として扱われます。運用環境によっては `b####` の再調整が必要です。

### ● 連打抑止（BURST）の廃止

v1.73f1 では「10秒窓内に短発2回以上で連打抑止10秒」という個別ロジックがありましたが、v1.80h では廃止されました。代わりに、カーチャンク検出のたびに ⑤ 抑止（r####）がリセット・延長される設計になっています。

**影響**：短時間に複数のカーチャンクが来た場合、旧来の連打抑止動作とは挙動が異なります。`r####` の値を適切に設定することで調整可能です。

### ● 送信直後ガード（postTxIgnore）の廃止

v1.73e/f1 では PTT OFF 直後に別個の `postTxIgnore` フラグで送信直後の誤発火を防止していましたが、v1.80h では廃止され ⑤ 抑止（busySupUntil）に統合されました。

**影響**：`i####`（送信直後ガード閾値）コマンドは廃止されます。送信直後の挙動は ⑤ 抑止時間（`r####`）で制御します。

### ● 定周期IDのスキップ仕様

v1.73系では定周期IDの到来時に条件不成立（受信中・抑止中・PTT中）の場合、`periodicDue` を保持して次の機会を待っていました（延期仕様）。

v1.80h では条件不成立の場合はその回をスキップ（破棄）します。次の定周期タイミングまで待機します。

**影響**：通話が頻繁な環境では定周期IDが送出されない場合が増えます。`k####` を短くするか `p##` の周期を見直してください。

--------------------------------------------------------------------

## 6. アップグレード後のチェックリスト（v1.80i）

```
1. スケッチを書き込む
2. 起動ログを確認：
   - v1.73系からの更新: "Version mismatch: stored=4" → "Migration done." → "Settings Loaded."
   - 初回またはデータ破損: "No/Other Data. Init defaults." → "Settings Loaded."
3. V を実行し、"OpenCCVoice v1.80i (EEPROM_VER=5)" を確認
4. q を実行し、以下を確認：
   - EEPROM_VER=5
   - MAX=1500（または意図した値）
   - SUP=10000（または意図した値）
   - PRE=1000 / POST=1000（または意図した値）
   - POL が無線機と一致（g0/g1）
   - 定周期間隔 PER(min) が意図した値
5. BUSY 極性を実機で確認（g0/g1）
6. カーチャンクID（001）が正常に動作するか確認
7. 通常会話中（dur ≥ b####）に ID が出ないことを確認
8. ⑤ 抑止が正常に解除されることを確認（D13 消灯、または [SUP] CLEAR ログ）
9. 定周期IDが意図したタイミングで送出（またはスキップ）されることを確認
10. Z コマンドで再起動 → 設定が保持されていることを確認
11. 必要なら b#### / r#### / j#### / J#### / k#### を調整
12. 完全クリーン起動が必要なら F → Z
```

--------------------------------------------------------------------

## 7. よくある質問（FAQ）

**Q1. v1.73f1 → v1.80i は特別な操作は必要？**  
→ 原則なし。スケッチ書き込みのみで自動マイグレーションが実行されます。

**Q1b. v1.80h → v1.80i は特別な操作は必要？**  
→ 不要。EEPROM CONFIG_VERSION が変わらないため、スケッチ書き込みのみで完了です。

**Q2. 旧設定は残る？**  
→ 基本的には残ります。ただし `busyMax` が旧デフォルト（3900ms）、`txSupMs` が旧デフォルト（3000ms）だった場合は自動的に新デフォルト値に更新されます。

**Q3. `s0/t0` を使って抑止を無効にしていたが、v1.80i では？**  
→ `s0/s1` / `t0/t1` コマンドは v1.80h で廃止されました。送信後抑止を実質無効にしたい場合は `r0` を使用してください。

**Q4. `i####`（送信直後ガード閾値）を設定していたが、v1.80i では？**  
→ `i####` コマンドは v1.80h で廃止されました。送信直後の挙動は ⑤ 抑止時間（`r####`）で制御します。

**Q5. STOP 復帰コマンドが `r` から `R` に変わったのはなぜ？**  
→ 旧来 `r` コマンドが「送信後無視時間の設定（r####）」と「STOP復帰（引数なし）」を兼用していたため、コマンド体系が分かりにくい問題がありました。`R`（大文字）に分離することで明確化しました。

**Q6. ログレベルコマンドが変わった**  
→ 旧 `0/1/2/3`（単体数字）から `l0/l1/l2/l3` に変更されました。起動時は常に l1=MIN（必要最低限のログ）です。EEPROM には保存されません。

**Q7. 定周期IDが全く送出されなくなった**  
→ スキップ仕様への変更により、受信中・抑止中が多い環境ではスキップが増えます。`k####` を短くするか（例：k500）、`p##` の周期を見直してください。`q` で `QUIET(ms)` と `PER(min)` を確認してください。

**Q8. 通常会話中に ID が出なくなった（旧 b3900 超えだった）**  
→ `b####` のデフォルトが 1500ms に変わったため、旧 3900ms デフォルト時とはカーチャンク判定範囲が変わっています。`b####` の値を `q` で確認し、必要に応じて再設定してください。

**Q9. BUSY判定が逆っぽい**  
→ `g0`（LOW=busy）/ `g1`（HIGH=busy）を確認してください。`q` で `POL=` を確認可能です。

**Q10. `F` → `Z` の完全クリーン起動後の確認方法は？**  
→ 起動ログに `No/Other Data. Init defaults.` が出て EEPROM_VER=5 になっていれば正常です。`q` で全設定がデフォルト値になっていることを確認してください。

--------------------------------------------------------------------

## 8. まとめ

| バージョン | 主な追加・改善 |
|---|---|
| v1.73c | EEPROM 自動移行・安全補完 |
| v1.73d | 定周期ID 静寂ガード（k####） |
| v1.73e | 送信直後ガード・周期ID catch-up 対策（v1.80h で統合・廃止） |
| v1.73f | `V`（バージョン確認）・`Z`（ソフトウェアリセット）コマンド追加 |
| v1.73f1 | `v` → `V` コマンド変更（v2.x 系との競合回避） |
| **v1.80i** | **コード整理・マイグレーション修正・デッドコード削除** |

通常は F・Z ともに不要。スケッチ書き込み後に `V` でバージョンを、`q` で設定を確認してください。  
v1.80h からの書き込みは EEPROM の変化なし。v1.73系からの場合は特に `MAX=` と `SUP=` の値がマイグレーション後に意図した値になっているかを必ず確認してください。

--------------------------------------------------------------------
End of NOTES_FOR_UPGRADE.md
--------------------------------------------------------------------

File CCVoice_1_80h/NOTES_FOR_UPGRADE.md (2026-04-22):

# OpenCCVoice Guidance Controller  
# アップグレード注意点（〜v1.80h）
# 最終更新日: 2026-03-24

本書は、OpenCCVoice を **v1.80h** にアップグレードする際の  
重要な注意点・確認手順をまとめた技術者向けドキュメントです。  
特に **v1.73f1 / v1.73f / v1.73e 系** からの更新時にご確認ください。

--------------------------------------------------------------------

## 1. v1.80h の概要

v1.80h は v1.73f1 からの直接アップグレード版です。EEPROM CONFIG_VERSION が 4 から 5 に変わっており、スケッチ書き込み後に自動マイグレーションが実行されます。

**主な変更点（v1.73f1 → v1.80h）：**

| 項目 | v1.73f1 | v1.80h |
|---|---|---|
| EEPROM CONFIG_VERSION | 4 | 5 |
| ② MAX（b）デフォルト | 3900ms | 1500ms |
| ⑤ 抑止時間（r）デフォルト | 3000ms | 10000ms |
| PRE 時間の制御 | 固定 1000ms（コマンド不可） | `j####` で可変（EEPROM保存） |
| POST 時間の制御 | 固定 1000ms（コマンド不可） | `J####` で可変（EEPROM保存） |
| 連打抑止（BURST） | あり | 廃止（⑤抑止に統合） |
| 送信直後ガード（postTxIgnore） | あり | 廃止（⑤抑止に統合） |
| `s0/s1` コマンド（抑止 ON/OFF） | あり | 廃止（常時有効） |
| `t0/t1` コマンド（送信後抑止 ON/OFF） | あり | 廃止（r0 で実質 OFF） |
| `i####` コマンド（送信直後ガード閾値） | あり | 廃止 |
| `H` コマンド（汎用プリセット） | あり | 廃止 |
| STOP 復帰コマンド | `r` | `R`（大文字） |
| ログレベルコマンド | `0/1/2/3` | `l0/l1/l2/l3` |
| 定周期ID 条件不成立時 | 延期（periodicDue 保持） | スキップ（破棄） |

--------------------------------------------------------------------

## 2. EEPROM の扱い（v1.73f1 → v1.80h）
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

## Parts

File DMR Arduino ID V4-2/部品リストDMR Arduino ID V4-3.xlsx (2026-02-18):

Reference | Value | Qty
A1 | Arduino_Nano | 1
C1,C4,C7,C8,C11,C12,C13,C14,C15 | 0.1 | 9
C2 | 0.022 | 1
C3,C6 | 10uF | 2
C5 | 0.001 | 1
C9 | 4.7uF | 2
C10 | Non-polar 4.7uF | 1
D1 | 1SS178 | 1
D2 | 1N4007 | 1
D3,D4,D5 | LED | 3
J1 | Conn_02x03_Odd_Even | 1
J2,J3,J5,J6 | Conn_01x02_Pin | 4
J4 | Conn_02x05_Odd_Even | 1
L1 | 10uH | 1
P1 | HIF3FC-20PA-2.54DSA_71_ | 1
Q1,Q2,Q3,Q4,Q5 | 2SC1815 | 5
R1,R3 | 2.4k | 2
R2 | 4.7k | 1
R4,R5,R11,R14,R16,R19 | 10k | 6
R6 | 3.9k | 1
R7,R8,R20 | 15k | 3
R9 | 1k | 1
R10 | 330 | 1
R12,R13,R15,R17,R18,R22,R23,R24 | 2.2k | 8
R21 | 1k | 1
RV1 | 5k | 1
RV2 | 500 | 1
U1 | LM7808 | 1
U2 | NJM2072 | 1
U3 | PC817X1NSZ0F | 1
U4 | DF Piayer Mini | 1

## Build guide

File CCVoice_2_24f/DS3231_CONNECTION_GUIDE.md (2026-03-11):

# DS3231 + AT24C32 モジュール 接続・運用ガイド

対象バージョン: OpenCCVoice v2.10 以降  
対象基板: Ver.5  
最終更新日: 2026-03-11

---

## 1. モジュールの概要

市販の「DS3231 + AT24C32」一体型 I²C モジュールには、2つのデバイスが搭載されています。

| デバイス | 役割 | I²C アドレス（既定） |
|---|---|---|
| **DS3231** | リアルタイムクロック（RTC） | 0x68（固定） |
| **AT24C32** | 外部 EEPROM（32Kbit / 4KB） | 0x57（A0〜A2 全 LOW 時） |

**v2.20 では DS3231（RTC）と AT24C32（EEPROM）の両方を使用します。**

| 用途 | デバイス |
|---|---|
| 時刻管理（正時アライン） | DS3231 |
| 設定の永続保存（内蔵EEPROMとの二重保存） | AT24C32 |

DS3231 は高精度 RTC チップです。コイン電池（CR2032）でバックアップされ、  
電源断中も時刻を保持し続けます。**時刻の自動取得機能はありません。**  
初回および電池交換後に `T` コマンドで時刻を設定する必要があります。

---

## 2. 基板への接続（J5 コネクタ）

Ver.5 基板には **J5 コネクタ**が実装済みです。  
DS3231 モジュールを J5 に差し込むだけで接続完了です。**配線の追加は不要です。**

```
基板 J5              DS3231 モジュール
┌─────────┐          ┌──────────┐
│ 1: SLC  │ ──────── │ SLC(SCL) │ ── Arduino A5
│ 2: SDA  │ ──────── │ SDA      │ ── Arduino A4
│ 3: VCC  │ ──────── │ VCC      │
│ 4: GND  │ ──────── │ GND      │
└─────────┘          └──────────┘
```

> **注意**: J5 の 1 ピン（SLC）と DS3231 モジュールの向きを確認してから挿入してください。

---

## 3. ハードウェアの注意点

### プルアップ抵抗について

Ver.5 基板には I²C プルアップ抵抗が実装済みです（C12 付近）。  
DS3231 モジュール側にも 4.7kΩ のプルアップが搭載されている場合がありますが、  
**二重になっても通常は問題なく動作します。**

### AT24C32 のアドレスジャンパについて

DS3231 モジュール上の AT24C32 には、I²C アドレスを変更するジャンパ（A0/A1/A2）が  
ある場合があります。

- **既定（ジャンパ未ショート）**: アドレス 0x57
- Ver.5 基板上には AT24C32 は実装されていないため、**アドレス競合は発生しません。**
- ジャンパはそのまま（未ショート）で使用してください。

---

## 4. 起動時の確認

モジュールを接続して電源を入れると、起動ログに以下が表示されます。

### DS3231 が正常に認識された場合

```
[RTC] DS3231 found.
[EEPROM] Settings Loaded.
[START] OpenCCVoice v2.10 (RTC-Aligned Periodic, Ver.5 pinmap)
[RTC] 2000/01/01 00:00:00  Align=ON(RTC)    ← 時刻未設定時はこの表示
```

### DS3231 が認識されない場合（未接続・故障）

```
[RTC] DS3231 not found -> millis() fallback.
[START] OpenCCVoice v2.10 ...
[RTC] N/A(no RTC)  Align=OFF(millis)
```

この場合は millis() 相対動作にフォールバックし、従来通り動作します。

---

## 5. 初回セットアップ手順

DS3231 を接続したら、最初に時刻を設定します。

### ① シリアルモニタを開く

Arduino IDE または任意のターミナルソフトで  
**115200 bps / 8N1 / 改行なし（または LF）** で接続します。

### ② 現在時刻を設定する（`T` コマンド）

書式: `T` + `YYYY` + `MM` + `DD` + `HH` + `mm` + `ss`（計15文字、スペースなし）

```
T20260311143000
```

上記は「2026年03月11日 14時30分00秒」の意味です。

**入力のコツ**: 時報の数秒前に文字を入力しておき、  
Enterキー（送信）のタイミングを時報に合わせると精度が上がります。

### ③ 設定確認（`q` コマンド）

```
q
```

以下のように表示されれば設定完了です。

```
[RTC] 2026/03/11 14:30:05  Align=ON(RTC)
[CFG] EEPROM_VER=5 SRC=DIGITAL(LOCK) MIN=500 MAX=3900 PER(min)=30
      ... QUIET(ms)=2000 RTC_ALIGN=ON
```

- `[RTC]` 行に現在時刻が表示されていること
- `Align=ON(RTC)` が表示されていること（RTCアライン動作中）

### ④ 周期IDの設定（`p` コマンド）

正時アラインで動作させたい周期を設定します。

```
p15     → 毎時 :00 / :15 / :30 / :45 に送出
p10     → 毎時 :00 / :10 / :20 / :30 / :40 / :50 に送出
p30     → 毎時 :00 / :30 に送出
p0      → 周期ID 停止
```

設定後、次の送出時刻まで待機します。`q` コマンドで現在の設定を確認できます。

---

## 6. コマンドリファレンス（RTC関連）

### `T` — RTC 時刻設定

| 項目 | 内容 |
|---|---|
| 書式 | `TYYYYMMDDHHmmss`（15文字、スペースなし） |
| 例 | `T20260311143000` → 2026/03/11 14:30:00 |
| タイムアウト | 2秒以内に14桁の数字が届かない場合は無効 |
| 設定後 | 次回周期ID発火時刻を即座に再計算 |

**エラーメッセージ一覧:**

| 表示 | 原因 |
|---|---|
| `[RTC] T: timeout` | 2秒以内に14桁届かなかった |
| `[RTC] T: invalid datetime` | 日付・時刻の値が範囲外 |
| `[RTC] T: DS3231 not found` | モジュールが認識されていない |
| `[RTC] T: write failed` | I²C 書き込み失敗 |

---

### `u` — RTCアライン ON/OFF

| コマンド | 動作 |
|---|---|
| `u1` | RTCアライン有効（既定）。DS3231接続かつp##が60の約数のとき正時アライン動作 |
| `u0` | RTCアライン無効。millis() 相対動作に切替（v2.01互換） |

設定は EEPROM に保存されます。

---

### `q` — 設定一覧（RTC関連の表示）

```
[RTC] 2026/03/11 14:23:45  Align=ON(RTC)
```

| 表示 | 意味 |
|---|---|
| `2026/03/11 14:23:45` | DS3231 から読んだ現在時刻 |
| `Align=ON(RTC)` | RTCアライン動作中（正時基準） |
| `Align=OFF(millis)` | millis() 相対動作（RTC未接続またはu0） |
| `N/A(no RTC)` | DS3231 が認識されていない |
| `N/A(read err)` | DS3231 への I²C 読み取り失敗 |

---

### `p` — 周期ID設定（RTCアライン対応）

60の約数を設定したとき、DS3231 接続かつ `u1` であれば自動的に正時アライン動作になります。

| 設定値 | アライン | 送出タイミング |
|---|---|---|
| `p10` | ○ | 毎時 :00/:10/:20/:30/:40/:50 |
| `p12` | ○ | 毎時 :00/:12/:24/:36/:48 |
| `p15` | ○ | 毎時 :00/:15/:30/:45 |
| `p20` | ○ | 毎時 :00/:20/:40 |
| `p30` | ○ | 毎時 :00/:30 |
| `p60` | ○ | 毎時 :00 |
| `p7`  | ✗ | millis() 相対（7分おき） |
| `p0`  | — | 周期ID 停止 |

---

## 7. 運用上の注意

### 電池切れ時の対応

DS3231 のコイン電池（CR2032）が切れると、時刻が `2000/01/01 00:00:00` 付近に  
リセットされます。`q` で確認し、`T` コマンドで再設定してください。

電池切れの目安は **モジュールのボタン電池寿命（数年）** ですが、  
運用開始時に `q` で時刻を確認する習慣をつけることを推奨します。

### 長期ドリフト補正

プログラムは **1分ごとに DS3231 から時刻を再取得**し、  
Arduino の millis() と DS3231 の時刻のずれを自動補正します。  
手動での定期的な時刻合わせは不要です。

### 時刻設定の精度

`T` コマンドは手打ちのため、数秒の誤差が生じることがあります。  
周期ID の送出タイミングは「毎正時アライン」のため、  
数秒の設定誤差は次の周期（最大1時間以内）のうちに自動収束します。

---

## 8. トラブルシューティング

**● `Align=OFF(millis)` になる（正時アラインにならない）**
1. `q` で `N/A(no RTC)` が出ていないか確認 → J5 コネクタの接続を確認
2. `q` で `RTC_ALIGN=OFF` になっていないか確認 → `u1` を入力
3. `p##` の値が 60 の約数か確認 → `p10`/`p15`/`p30` 等を使用

**● `[RTC] T: DS3231 not found` と出る**
- J5 コネクタの向きと挿入を確認
- モジュールの VCC/GND が正しく接続されているか確認

**● 時刻がすぐにリセットされる**
- DS3231 モジュールのコイン電池（CR2032）を確認・交換

**● 周期IDが設定時刻より数秒ずれる**
- `T` コマンド入力時の誤差です。次の周期で自動収束します
- より正確に合わせたい場合は、時報の直前に文字を入力し送信タイミングを合わせてください

---

## 9. 仕様まとめ

| 項目 | 内容 |
|---|---|
| DS3231 I²C アドレス | 0x68（固定） |
| AT24C32 I²C アドレス | 0x57（設定の二重保存先） |
| 接続コネクタ | J5（基板右端、4ピン） |
| 使用ライブラリ | Wire.h（Arduino標準、外部ライブラリ不要） |
| アライン対象周期 | 60の約数（1/2/3/4/5/6/10/12/15/20/30/60分） |
| ドリフト補正間隔 | 1分 |
| 電池 | CR2032（モジュール付属または別途用意） |
| 時刻設定コマンド | `TYYYYMMDDHHmmss` |

---

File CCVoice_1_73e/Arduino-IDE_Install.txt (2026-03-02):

Arduino IDEインストール
下記ページ参照ください
https://www.sub.h-sol.jp/zakki-cho/2025/08/arduino.html
2027/03/03 JG1XWV/ほりえ

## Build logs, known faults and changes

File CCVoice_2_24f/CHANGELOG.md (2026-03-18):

# CHANGELOG — OpenCCVoice ID Guidance Controller

本プロジェクトは、Arduino Nano (ATmega328P, 5V) 上で動作する DMR無線機の ID送出支援コントローラです。

記法: Keep a Changelog 準拠 / 日付: JST

--------------------------------------------------------------------

## v2.24f — V/Z コマンド追加版 (2026-03-18)

### Added
- **`V` コマンド：バージョン確認**（v1.73f1 由来）
  - スケッチバージョンと EEPROM_VER を即時表示。
  - 出力例：`[VER] OpenCCVoice v2.24f (EEPROM_VER=6)`
  - v2.x 系では `v` をイベントログ表示に使用しているため大文字 `V` を採用。

- **`Z` コマンド：ソフトウェアリセット**（v1.73f1 由来）
  - ウォッチドッグタイマー（WDT, 15ms）による MCU 再起動。
  - EEPROM の内容は変更しない（設定は保持されたまま再起動）。
  - `F` → `Z` の順で実行すると完全クリーン起動が可能。
  - 実行後はシリアル出力を吐き出してから WDT 発火（`delay(100)` 挿入）。

  | コマンド | EEPROM | MCU | 用途 |
  |---------|--------|-----|------|
  | `F` のみ | 初期値で上書き | 動き続ける | 設定のみリセット |
  | `Z` のみ | 変化なし | 再起動 | 設定保持のまま再起動 |
  | `F` → `Z` | 初期値で上書き | 再起動 | 完全クリーン起動 |

### Notes
- 機能的な変更はありません。v2.24 の全機能を継承。
- EEPROM CONFIG_VERSION = **6（変更なし）**。`F` コマンド不要。
- `avr/wdt.h` をインクルード追加（WDT 制御に使用）。
- PTT 出力中に `Z` を実行すると WDT ハードリセットにより PTT が即解放される。
  意図せず実行しないこと。

--------------------------------------------------------------------

## v2.24 — アーキテクチャ最適化・安全性向上版 (2026-03-12)

### Changed
- **メモリアクセスの最適化**
  - 非同期割り込みを使用していない変数（`LOG_LEVEL`、`BUSY_INPUT_SOURCE`）から
    `volatile` キーワードを削除し、コンパイラの最適化効率を向上。
- **C++ コードの堅牢性向上**
  - `ccvoice_log.h` および `ccvoice_config.h` 内の全関数に `inline` 指定子を付与。
    将来的に複数ファイルからインクルードされた際の多重定義エラーを未然に防止。

### Notes
- 機能的な変更はありません。v2.23 の全機能を継承。
- EEPROM CONFIG_VERSION = **6（変更なし）**。`F` コマンド不要。

--------------------------------------------------------------------

## v2.23 — TX/RX ピン修正・コンパイルエラー修正版 (2026-03-12)

### Fixed
- **DFPlayer TX/RX ピンアサインのバグを修正**（v2.22 より）

  | | ARD_RX（← DFPlayer TX） | ARD_TX（→ DFPlayer RX） |
  |---|---|---|
  | **誤（v2.21以前）** | D13 | D12 |
  | **正（v2.23）** | D12 | D13 |

- **Arduino IDE でのコンパイルエラーを修正**
  - Arduino IDE は `.ino` ファイルのコンパイル前に全関数のプロトタイプ宣言を
    自動生成する。この際 `struct LogHeader` / `struct MyConfig` より前に
    プロトタイプが挿入されてしまい「未宣言」エラーが発生していた。
  - ログ関連コードを `ccvoice_log.h`、設定マイグレーションコードを
    `ccvoice_config.h` に分離することで根本解決。

### 構成ファイル（3ファイルを同一フォルダに置くこと）
```
CCVoice_2_23.ino    メインスケッチ
ccvoice_log.h       イベントログ関連
ccvoice_config.h    設定マイグレーション関連
```

### Notes
- 機能的な変更はありません。v2.21 の全機能を継承。
- v2.20 / v2.21 / v2.22 は廃止（GitHub からも削除）。機能・仕様の記録は CHANGELOG に保持。
- EEPROM CONFIG_VERSION = **6（変更なし）**。`F` コマンド不要。

--------------------------------------------------------------------

--------------------------------------------------------------------

## v2.22 — DFPlayer TX/RX ピンアサイン修正 (2026-03-11) ⚠️ 廃止

### Fixed
- DFPlayer TX/RX ピンアサインのバグを修正（v2.21以前と逆だった）
  - 誤: ARD_RX=D13 / ARD_TX=D12
  - 正: ARD_RX=D12 / ARD_TX=D13

### Notes
- ⚠️ **このバージョンはコンパイルエラーのため廃止です。v2.23 をご使用ください。**
- Arduino IDE のプロトタイプ自動生成により `LogHeader` / `MyConfig` 未宣言エラーが発生。

## v2.21 — AT24C32 イベントログ記録対応版 (2026-03-11) ⚠️ 廃止

### Added
- **AT24C32 へのイベントログ記録機能を追加**
  - ログ領域: AT24C32 アドレス 0x0048〜（リングバッファ、最大 448件）
  - 448件超過後は古いものから上書き（9バイト/件）

- **記録イベント一覧**

  | 種別 | 表示 | 記録タイミング | 付加データ |
  |------|------|----------------|-----------|
  | 起動 | BOT | 起動時 | EEPROM ver |
  | 周期ID送出 | PER | Track2/3送出時 | Track番号 |
  | カーチャンク | CAR | ID送出トリガー時 | BUSY時間(ms) |
  | 長話抑止 | SUP | 長話抑止発生時 | BUSY時間(ms) |
  | バースト抑止 | BST | バースト抑止発生時 | バースト回数 |

- **`v` コマンド追加**: 直近20件をシリアルモニタに表示
- **`v0` コマンド追加**: ログ全件消去

### Notes
- AT24C32 未接続時はログ記録・表示をスキップ（動作に影響なし）
- EEPROM CONFIG_VERSION = **6（変更なし）**
- ⚠️ **このバージョンは廃止です。v2.23 をご使用ください。**

--------------------------------------------------------------------

## v2.20 — AT24C32 外部EEPROM 二重保存対応版 (2026-03-11) ⚠️ 廃止

### Added
- **AT24C32（外部EEPROM / I²C 0x57）対応**
  - 設定変更時に AT24C32 と内蔵EEPROM の両方へ同時保存
  - 起動時は AT24C32 を優先して読み込み（可搬性設計）
  - AT24C32 未接続時は内蔵EEPROM にフォールバック
  - DS3231 時刻（秒換算）をタイムスタンプとして保存し新旧を自動判定
- **EEPROM CONFIG_VERSION を 6 に更新**（`saveTimestamp` フィールド追加）

### Notes
- v2.10（ver=5）からの更新時、既存設定を自動継承。`F` コマンド不要。
- ⚠️ **このバージョンは廃止です。v2.23 をご使用ください。**

--------------------------------------------------------------------

## v2.10 — DS3231 RTC 正時アライン対応版 (2026-03-11)

### Added
- **DS3231 RTC モジュール対応**（I²C / A4=SDA, A5=SCL）
- **周期ID の「正時アライン」方式を導入**
  - `p##` が60の約数かつ DS3231 接続時 → 毎正時基準で等間隔送出
  - 例：`p15` → 毎時 :00/:15/:30/:45 に送出
  - 60の約数でない値または DS3231 未接続時 → millis() 相対動作
- **`T` コマンド追加**: RTC 時刻設定（例: `T20260311143000`）
- **`u0/u1` コマンド追加**: RTCアライン OFF/ON
- **EEPROM CONFIG_VERSION を 5 に更新**（`rtcAlignOn` フィールド追加）

--------------------------------------------------------------------

## v2.01 — Ver.5 ピンマップ対応版 (2026-03-10)

### Changed
- **Ver.5 基板ピンマップへ全面移行**（v1.73e からのピン変更）

  | 信号 | v1.73e | v2.01〜 (Ver.5) |
  |------|--------|----------------|
  | DFPlayer BUSYミラー出力 | D2 | D3 |
  | テストSW | D3 | D2 |
  | TM BUSY入力 | D6 | D11 |
  | DFPlayer BUSY入力 | D7 | D10 |
  | 抑止 LED | D13 | D6 |
  | A0検知 LED | D12 | D7 |
  | Arduino RX ← DFPlayer TX | D10 | D12 |
  | Arduino TX → DFPlayer RX | D11 | D13 |

- **STOP復帰コマンドを `r` から `R` に変更**

### Notes
- EEPROM レイアウトは v1.73d/e と同一（`config.ver = 4`）

--------------------------------------------------------------------

## v1.73e — Unified/Safe + Stability Fixes (2026-02-13)
- 送信直後ガード（postTxIgnore）追加
- A0 BUSY 観測ロジックの安定化
- EEPROM レイアウト: config.ver = 4（変更なし）

## v1.73d — Periodic Quiet Guard (2026-01-26)
- 周期IDの「静寂ガード」導入（`k####` ms）
- EEPROM config.ver = 4 に更新

## v1.73c — Versioned EEPROM (2026-01-26)
- EEPROM レイアウトバージョン管理導入

## v1.73b (2026-01-22)
- `g0/g1` コマンド（TM BUSY 極性切替）追加

## v1.73a (2026-01-22)
- `d####` コマンド（DFPlayer フェイルセーフ ms）追加

## v1.73-unified-safe (2026-01-22)
- DFPlayer フェイルセーフ、A0/Digital AUTO判定、STOP/RESUME、HELP

## v1.72-final-EEPROM+F (2026-01-20)
- Factory Reset（F）、EEPROM 永続化

## v1.71-stable-final (2026-01-19)
- HELP、STOP、t0/t1 追加

## Pre-v1.71 / Prototype — 2025-08〜
- v1.50：初の安定版（Digital BUSY判定、PTT PRE/POST）

--------------------------------------------------------------------

## 付録：ピンマップ（Ver.5 基板 / v2.01以降）

| Pin | 機能 | 備考 |
|-----|---|---|
| D2  | テストSW | INPUT_PULLUP（1〜3クリックでTRACK 1〜3） |
| D3  | DFP BUSYミラー出力 | 再生中=HIGH（反転） |
| D4  | ModBusy LED | BUSY表示 |
| D5  | PTT出力 | HIGH=送信 |
| D6  | 抑止 LED | 抑止/バースト/POST-TX表示 |
| D7  | A0検知 LED | A0 BUSY表示 |
| D10 | DFPlayer BUSY入力 | LOW=再生中（INPUT_PULLUP） |
| D11 | TM BUSY入力（Digital入力） | 極性切替可（g0/g1）、INPUT_PULLUP |
| D12 | Arduino RX ← DFPlayer TX | SoftwareSerial 9600bps |
| D13 | Arduino TX → DFPlayer RX | SoftwareSerial 9600bps |
| A0  | アナログ入力 | ヒステリシス＋保持適用 |
| A4  | I²C SDA | DS3231 + AT24C32（v2.10追加） |
| A5  | I²C SCL | DS3231 + AT24C32（v2.10追加） |

--------------------------------------------------------------------
End of CHANGELOG

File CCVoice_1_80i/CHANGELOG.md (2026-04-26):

# CHANGELOG.md - OpenCCVoice ID Guidance Controller

本プロジェクトは、Arduino Nano (ATmega328P, 5V) 上で動作する、DMR無線機の ID送出支援コントローラです。

記法: Keep a Changelog 準拠  
日付: JST（日本標準時）

--------------------------------------------------------------------

## v1.80i — コード整理・マイグレーション修正・デッドコード削除 (2026-03-24)

EEPROM CONFIG_VERSION は 5 のまま変更なし。v1.80h からの書き込みでそのまま動作する。

### Fixed（バグ修正・コード整理）

- **カーチャンク検出時の `busySupUntil` 二重セットを修正**
  - v1.80h の `processBusyLogic()` では、カーチャンク検出時と `processStateMachine()`
    の POST終了（起点A）の二か所で `busySupUntil` をセットしていた。
  - 動作結果は正しかったが設計意図が不明瞭だったため、カーチャンク検出時の先行セットを削除し、
    抑止セットを POST終了（起点A）に一本化した。

- **`migrateOrInit()` の ver=4 以外からのマイグレーション時の不定値リスクを修正**
  - v1.73c 以前（ver=3 以下）のデバイスから直接 v1.80i を書き込んだ場合、
    `pttPreMs` / `pttPostMs` が EEPROM 上に存在しないため読み出し値が不定だった。
  - `ver == 4` 以外の `else` ブランチでも `pttPreMs` / `pttPostMs` を 1000ms で
    明示初期化するよう修正（その後の範囲チェックによる二重安全も維持）。

- **`handleStoppedState()` 内のデッドコードを削除**
  - STOP中の `R` コマンド受付は `handleSerialCmd()` の `case 'R':` で完結しており、
    `handleStoppedState()` 内の `Serial.read()` ブロックは実質到達しないコードだった。
  - 該当コードを削除し、コメントで復帰処理の所在を明示した。

### Changed（コメント修正）

- 概要コメント「抑止（長話/連打/送信後）を統合管理」→ 正確な表現に修正
- `processBusyLogic()` 内「②超え → 長話抑止（起点B）」→ 正確な表現に修正
- `pAct=true` 時の ② 超え受信終了も起点B として `busySupUntil` をセットする旨をコメントに明記
- `handleSerialCmd()` / `setup()` の内部開発版番号（v1.80d/e）を v1.80h に修正

### EEPROM

- `CONFIG_VERSION` = 5（変更なし）
- 構造体フィールドの変更なし
- v1.80h からの書き込みは EEPROM 操作不要

--------------------------------------------------------------------

## v1.80h — 仕様刷新・抑止ロジック統合・バグ修正 (2026-03-24)

⚠️ **廃止（v1.80i に統合）** — 歴史的記録として保持

### Changed（仕様変更）

- **カーチャンク判定範囲を明確化**
  - ① MIN(n) 以上 ② MAX(b) 未満の受信継続時間をカーチャンクと判定する仕様に統一
  - ② MAX のデフォルト: 3900ms → **1500ms**（通常の通話時間との境界を明確化）
  - ⑤ 抑止時間(r) のデフォルト: 3000ms → **10000ms**

- **PTT 先行・後行無音時間をコマンドで可変化**
  - ③ PTT先行無音時間(PRE): `j####` コマンドで設定（デフォルト 1000ms）
  - ④ PTT後行無音時間(POST): `J####` コマンドで設定（デフォルト 1000ms）
  - いずれも EEPROM に保存される

- **通常会話終了時の抑止起点を統一**
  - 起点A: ④ POST 終了の瞬間（カーチャンクID送出後・受信中でない場合）
  - 起点B: ② 超え受信の終了の瞬間（通常会話終了）
  - 受信中に POST が終わった場合は起点B が起点A を上書き

- **連打抑止（BURSTロジック）を削除**
  - 旧 BURST ロジックはカーチャンクが来るたびに抑止を延長し続ける問題があった
  - 抑止は ⑤抑止（busySupUntil）のみで一元管理

- **定周期IDのスキップ仕様に変更**
  - 受信中・抑止中・PTT中に周期が到来したらその回をスキップ（破棄）
  - 旧仕様の「延期（periodicDue 保持）」から変更

- **ログレベルコマンドを変更**
  - 旧 `0/1/2/3` → 新 `l0/l1/l2/l3` に変更
  - l0=OFF / l1=MIN（起動時デフォルト）/ l2=FULL / l3=DBG
  - EEPROM 保存なし（起動時は常に l1=MIN）

- **STOP 復帰コマンドを変更**
  - `r`（小文字）→ `R`（大文字）に変更
  - 旧来 `r` コマンドが「送信後無視時間設定」と「STOP復帰」を兼用していた問題を解消

### Added（追加）

- `j####` コマンド: ③ PTT先行無音時間 PRE（ms）設定・EEPROM保存
- `J####` コマンド: ④ PTT後行無音時間 POST（ms）設定・EEPROM保存
- 抑止中カーチャンクのスキップログに残り時間を付記（l1=MIN から表示）
  - `[RX] CK dur=###ms skip(pAct)` — PTT送出中のスキップ
  - `[RX] CK dur=###ms skip(sup remain=####ms)` — 抑止中のスキップ（残り時間付き）
- 抑止状態変化検出ログを追加
  - `[SUP] ACTIVE` — 抑止開始時
  - `[SUP] CLEAR` — 抑止解除時
- `[SUP] START ####ms (long-talk dur=####ms)` — 長話受信終了時の抑止開始ログ
- `[SUP] START ####ms (from POST-end)` — POST終了起点の抑止開始ログ
- `[SUP] Defer to RX-end (point-B)` — 受信中の POST 終了時（起点B 待ち）ログ

### Removed（削除）

- `s0/s1` コマンド（抑止全体 ON/OFF）→ 抑止は常時有効
- `t0/t1` コマンド（送信後抑止 ON/OFF）→ `r0` で実質 OFF
- `i####` コマンド（送信直後ガード閾値）→ ⑤抑止に統合
- `H` コマンド（汎用プリセット）
- 送信直後ガード（postTxIgnore）変数・ロジック → ⑤抑止に統合
- 連打抑止関連の定数: `BURST_WIN_MS` / `BURST_TH` / `BURST_SUP_MS`
- 連打抑止関連の変数: `burstWinStart` / `burstSupUntil` / `burstCount`
- 長話専用抑止タイマー変数 `longSupUntil`（⑤抑止タイマー busySupUntil に統合）
- EEPROM フィールド: `suppressOn` / `txAfSupOn` / `idleMin`
- 旧ログレベルコマンド `0/1/2/3`（単体数字）
- STOP 復帰コマンド `r`（小文字）

### Fixed（バグ修正）

- **PRE/POST 無音時間がスキップされる問題を修正**
  - `Serial.setTimeout(50)` を `setup()` で一度だけ設定するよう変更
  - 旧実装では `handleSerialCmd()` 内で毎回 `Serial.setTimeout()` を呼んでいたため、
    `parseInt()` のブロッキング中に `millis()` が進み、PRE 無音時間がスキップされる場合があった

- **PRE/POST 待機を絶対時刻比較に変更**
  - `stateTimer`（相対比較: `now - stateTimer >= PTT_PRE_MS`）を廃止
  - `pttPreEndAt` / `pttPostEndAt`（絶対時刻: `(long)(now - pttPreEndAt) >= 0`）に置き換え
  - ブロッキングで `now` がずれても PRE/POST が確実に保証される

### EEPROM

- `CONFIG_VERSION`: 4 → **5**
- 追加フィールド: `pttPreMs` / `pttPostMs`
- 削除フィールド: `suppressOn` / `txAfSupOn` / `idleMin`
- ver=4（v1.73系）からの自動マイグレーション対応
  - `pttPreMs` / `pttPostMs` を 1000ms で補完
  - `busyMax` が旧デフォルト値 3900ms の場合のみ 1500ms に更新
  - `txSupMs` が旧デフォルト値 3000ms の場合のみ 10000ms に更新

### Notes

- EEPROM はスケッチ書き込み後に自動マイグレーションされるため、
  原則として `F`（Factory Reset）は不要
- 起動後に `V` でバージョンを、`q` で設定を確認すること
- 定周期IDがスキップされやすい場合は `k####` を短くするか、
  `p##` の周期を見直すこと

--------------------------------------------------------------------

## v1.73f1 — コマンド競合回避（`v` → `V` 変更） (2026-03-18)

⚠️ **廃止（v1.80h に統合）** — 歴史的記録として保持

### Changed
- **`v` コマンドを `V`（大文字）に変更**
  - v2.x 系では `v` をイベントログ表示コマンドとして使用するため、
    将来の統合・移行時の競合を避けるため大文字 `V` に変更
  - 機能・出力内容は変更なし
  - 出力例：`[VER] OpenCCVoice v1.73f1 (EEPROM_VER=4)`

### Notes
- EEPROM レイアウトは **v1.73f と同一（`config.ver = 4`）**

--------------------------------------------------------------------

## v1.73f — Unified/Safe + Version/Reset Commands (2026-02-13)

⚠️ **廃止（v1.80h に統合）** — 歴史的記録として保持

### Added
- **`V` コマンド（v1.73f では `v`）：バージョン確認**
  - スケッチバージョンと EEPROM_VER を即時表示
  - 出力例：`[VER] OpenCCVoice v1.73f (EEPROM_VER=4)`
  （v1.73f1 にて `v` → `V` に変更）

- **`Z` コマンド：ソフトウェアリセット**
  - ウォッチドッグタイマー（WDT, 15ms）による MCU 再起動
  - EEPROM は変更しない（設定保持のまま再起動）
  - `F` → `Z` で完全クリーン起動が可能

### Notes
- EEPROM レイアウトは **v1.73d/e と同一（`config.ver = 4`）**

--------------------------------------------------------------------

## v1.73e — Unified/Safe + Stability Fixes (2026-02-13)

⚠️ **廃止（v1.80h に統合）** — 歴史的記録として保持

### Added
- **送信直後ガード（postTxIgnore）を追加**（v1.80h で削除・⑤抑止に統合）
  - PTT OFF 直後に postTxIgnore=true をセット
  - BUSY が idleMin ms 連続 OFF になった時点で自動解除
  - 短発ID・周期ID の両方に適用

- **周期IDスケジューラの catch-up 対策**（v1.80h のスキップ仕様に置き換え）
  - nextPeriodicAt を while で未来へ追い付かせ、periodicDue は最大1回のみ

### Changed
- A0 BUSY 観測ロジックの安定化（抑止中も観測継続・AUTOカウントのみ停止）
- 送信直後の再発火防止強化（lastTriggerAt を PTT OFF 時に更新）

### Notes
- EEPROM レイアウトは **v1.73d と同一（`config.ver = 4`）**

--------------------------------------------------------------------

## v1.73d — Unified/Safe + Periodic Quiet Guard (2026-01-26)

⚠️ **廃止（v1.80h に統合）** — 歴史的記録として保持

### Added
- **周期IDの静寂ガードを導入（`k####` ms）**
  - 周期ID は BUSY が OFF になってから k ms 以上静寂が継続した場合のみ送出
  - BUSY中・静寂不足・抑止中は延期（periodicDue を保持）
  - 既定値：k2000（2秒）。k0 で静寂条件なし

### Changed
- **EEPROM レイアウトを更新（`config.ver = 4`）**
  - `periodQuietMs` フィールドを追加

--------------------------------------------------------------------

## v1.73c — Unified/Safe + Versioned EEPROM (2026-01-26)

⚠️ **廃止（v1.80h に統合）** — 歴史的記録として保持

### Added
- **EEPROM レイアウトバージョン管理（config.ver）を導入**
  - `config.magic` 不一致 → 完全初期化
  - `config.ver` 不一致 → 自動マイグレーション（新規項目の既定補完）

--------------------------------------------------------------------

## v1.73b — Unified/Safe + TM Busy Polarity Cmd (2026-01-22)

⚠️ **廃止（v1.80h に統合）** — 歴史的記録として保持

### Added
- `g0/g1` コマンド: TM BUSY 極性切替・EEPROM 保存
  - g0 = LOW=受信（アクティブLOW）
  - g1 = HIGH=受信（アクティブHIGH）

--------------------------------------------------------------------

## v1.73a — Unified/Safe + DFP Timeout Cmd (2026-01-22)

⚠️ **廃止（v1.80h に統合）** — 歴史的記録として保持

### Added
- `d####` コマンドで DFPlayer フェイルセーフ時間（ms）を可変化
- 既定タイムアウトを 20000ms（20秒）に設定

--------------------------------------------------------------------

## v1.73-unified-safe / v1.72 / v1.71 / v1.69 系 / v1.68 系 / v1.67 系 / v1.64 以前

⚠️ **廃止（v1.80h に統合）** — 歴史的記録として保持

主要マイルストーン：
- v1.73-unified-safe: 完全統合・安全性強化・機種依存排除版
- v1.72: Factory Reset（F）・EEPROM 永続化
- v1.71: HELP・STOP・q に LONG_TALK_MS 追加
- v1.69e: AUTO（D6/A0発生数比較）
- v1.68 系: A0 ヒステリシス・長話/連打抑止
- v1.67 系: 送信後抑止・D2 ミラー出力
- v1.64: PTT最低ONガード・BUSYヒステリシス再設計
- v1.50: 初の安定版（D6 BUSY判定）

--------------------------------------------------------------------

## 付録：ピンマップ（Arduino Nano / Ver.5 PCB / v1.80i 時点）

| Pin | 機能 | 備考 |
|-----|---|---|
| D2  | DFP BUSYミラー出力 | 再生中=HIGH（反転） |
| D3  | テストSW | INPUT_PULLUP |
| D4  | 受信LED(D6) | D6/AUTO時 |
| D5  | PTT出力 | HIGH=送信 |
| D6  | TM BUSY入力 | 極性切替可（g0/g1） |
| D7  | DFPlayer BUSY入力 | LOW=再生中 |
| D10 | Arduino RX | ← DFPlayer TX |
| D11 | Arduino TX | → DFPlayer RX |
| D12 | A0 LED | A0/AUTO時 |
| D13 | 抑止/AUTO LED | 抑止中・AUTO固定通知 |
| A0  | アナログ入力 | ヒステリシス＋保持 |

--------------------------------------------------------------------

## 付録：用語対応表（コード識別子 ↔ ドキュメント表現）

変数名・定数名はコード互換性のため変更せず、ドキュメントおよびコメントのみ読み替えを行っています。

| コード識別子 | ドキュメント表現 |
|---|---|
| `PIN_TM_BUSY` / `tmBusy*` | 受信BUSY信号（D6入力） |
| `TMBUSY_ACTIVE_HIGH` | 受信BUSY信号極性 |
| `busySupUntil` | ⑤抑止終了時刻 |
| `TX_SUP_MS` | ⑤抑止時間 |
| `PTT_PRE_MS` | ③ PTT先行無音時間（PRE） |
| `PTT_POST_MS` | ④ PTT後行無音時間（POST） |
| `BUSY_MIN_MS` | ① カーチャンク最小受信長 |
| `BUSY_MAX_MS` | ② カーチャンク最大受信長 |
| `PERIOD_QUIET_MS` | 定周期送出前の静寂待機時間 |
| `pttPreEndAt` | PRE終了予定時刻（絶対値） |
| `pttPostEndAt` | POST終了予定時刻（絶対値） |

### v1.73系から削除された識別子（v1.80h/v1.80i 以降は存在しない）

| 識別子 | 旧用途 |
|---|---|
| `postTxIgnore` | 送信直後ガードフラグ（⑤抑止に統合） |
| `postTxIdleStart` | 送信直後ガード解除用計測 |
| `IDLE_MIN_MS` / `idleMin` | 送信後BUSY安定待ち時間 |
| `BURST_WIN_MS` / `burstWinStart` | 連打検出窓 |
| `BURST_SUP_MS` / `burstSupUntil` | 連打抑止 |
| `BURST_TH` / `burstCount` | 連打閾値・カウンタ |
| `LONG_SUP_MS` / `longSupUntil` | 長話抑止（⑤抑止に統合） |
| `suppressOn` / `SUPPRESSORS_ENABLED` | 抑止全体ON/OFF |
| `txAfSupOn` / `TX_AFTER_SUPPRESS_ENABLED` | 送信後抑止ON/OFF |
| `stateTimer` | ステート遷移タイマー（絶対時刻比較に置き換え） |
| `periodicDue` | 周期ID送出待ちフラグ（スキップ仕様に変更） |
| `lastTriggerAt` | 最終ID送出時刻（不応期管理、不応期ロジック削除により廃止） |

## 付録：バージョンまとめ

| バージョン | 主な追加・改善 | 状態 |
|---|---|---|
| v1.73c | EEPROM 自動移行・安全補完 | ⚠️ 廃止 |
| v1.73d | 定周期ID 静寂ガード（k####） | ⚠️ 廃止 |
| v1.73e | 送信直後ガード・周期ID catch-up 対策 | ⚠️ 廃止 |
| v1.73f | `V`（バージョン確認）・`Z`（ソフトウェアリセット）コマンド追加 | ⚠️ 廃止 |
| v1.73f1 | `v` → `V` コマンド変更（v2.x 系との競合回避） | ⚠️ 廃止 |
| v1.80h | 仕様刷新（抑止一本化・PRE/POST可変化・スキップ仕様・バグ修正） | ⚠️ 廃止 |
| **v1.80i** | **コード整理・マイグレーション修正・デッドコード削除** | **✅ 現行** |

--------------------------------------------------------------------
End of CHANGELOG

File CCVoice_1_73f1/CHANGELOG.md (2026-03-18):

# CHANGELOG.md - OpenCCVoice ID Guidance Controller

本プロジェクトは、Arduino Nano (ATmega328P, 5V) 上で動作する、DMR無線機の ID送出支援コントローラです。

記法: Keep a Changelog 準拠  
日付: JST（日本標準時）

--------------------------------------------------------------------

## v1.73f1 — コマンド競合回避（`v` → `V` 変更） (2026-03-18)

### Changed
- **`v` コマンドを `V`（大文字）に変更**
  - v2.x 系では `v` をイベントログ表示コマンドとして使用するため、
    将来の統合・移行時の競合を避けるため大文字 `V` に変更。
  - 機能・出力内容は変更なし。
  - 出力例：`[VER] OpenCCVoice v1.73f1 (EEPROM_VER=4)`

### Notes
- EEPROM レイアウトは **v1.73f と同一（`config.ver = 4`）**。
  既存機の EEPROM をそのままアップグレード可能。
- `Z` コマンドに変更なし。
- `v` コマンド（旧）は `V`（大文字）に読み替えてください。

--------------------------------------------------------------------

## v1.73f — Unified/Safe + Version/Reset Commands (2026-02-13)

### Added
- **`v` コマンド：バージョン確認**（v1.73f1 にて `V` に変更）
  - スケッチバージョンと EEPROM_VER を即時表示。
  - 起動ログを見逃した後でも、いつでも確認可能。
  - 出力例：`[VER] OpenCCVoice v1.73f (EEPROM_VER=4)`（v1.73f1 では `v1.73f1` と表示）

- **`Z` コマンド：ソフトウェアリセット**
  - ウォッチドッグタイマー（WDT, 15ms）による MCU 再起動。
  - EEPROM の内容は変更しない（設定は保持されたまま再起動）。
  - `F`（Factory Reset）と組み合わせることで完全クリーン起動が可能。
  - 実行後はシリアル出力を吐き出してから WDT 発火（`delay(100)` 挿入）。

### Notes
- EEPROM レイアウトは **v1.73d/e と同一（`config.ver = 4`）**。
  既存機の EEPROM をそのままアップグレード可能。
- 操作コマンド体系に `V` / `Z` を追加。その他のコマンドに変更なし。
  （※ v1.73f1 にて `v` → `V` に変更）
- **ドキュメント・コメント用語の読み替えを実施**（用語の詳細は下記参照）。
- タイムチャート（`OpenCCVoice_TimingChart.xlsx`）を追加。  
  5シナリオ（短発・長話抑止・連打抑止・送信直後ガード・周期ID静寂ガード）を  
  共通タイムラインで収録し、①〜⑳の番号解説付き。
- `F` と `Z` の違い：

  | コマンド | EEPROM | MCU | 用途 |
  |---------|--------|-----|------|
  | `F` | 初期値で上書き | 動き続ける | 設定のみリセット |
  | `Z` | 変化なし | 再起動 | 設定保持のまま再起動 |
  | `F` → `Z` | 初期値で上書き | 再起動 | 完全クリーン起動 |

--------------------------------------------------------------------

## v1.73e — Unified/Safe + Stability Fixes (2026-02-13)

### Added
- **送信直後ガード（postTxIgnore）を追加**
  - 音声ID送出直後の A0 残留BUSY、スケルチテール、瞬間的なBUSY揺れによる
    **短発ID（001）や周期IDの誤発火を防止**。
  - PTT OFF 直後は一時的に「抑止扱い」とし、以下を抑制：
    - 短発ID（001）
    - 周期ID（002/003）
  - BUSY が **連続して `idleMin` ms 以上 OFF** になった時点で自動解除。

- **周期IDスケジューラの catch-up 対策**
  - BUSYや抑止により周期IDが長時間延期された場合でも、
    **解除後に周期IDが連続送信されない**よう制御を改善。
  - `nextPeriodicAt` を `while` で未来へ追い付かせ、
    **`periodicDue` は最大1回分のみ**立つ設計に変更。

### Changed
- **A0 BUSY 観測ロジックの安定化**
  - 抑止中であっても A0 の BUSY 状態（`a0Busy`）は継続して観測。
  - 抑止中は AUTO 判定用イベントカウント（`a0_event_count`）のみ増加させない。
- **送信直後の再発火防止を強化**
  - PTT OFF 時に `lastTriggerAt` を更新し、
    不応期（REFRAC_MS）の起点を送信直後に再設定。

### Notes
- EEPROM レイアウトは **v1.73d と同一（`config.ver = 4`）**。
  既存機の EEPROM を破壊せず、そのままアップデート可能。
- 操作コマンド体系（m/n/b/p/k/r/t 等）に変更なし。
- 本版は **機能追加ではなく、実運用安定性の向上のみを目的**としたリリース。
- v1.73d で導入された Quiet Guard（`k####`）と完全互換。
- BUSY が多発する環境や A0 使用時の誤動作報告への対策版。
- **既知の注意点**：`k0`（静寂ガード無効）を設定して再起動した場合、
  `migrateOrInit()` の補完ロジックにより `periodQuietMs` が 2000ms にリセットされる。
  再起動後は `q` で QUIET(ms) を確認し、必要に応じて再設定すること。

--------------------------------------------------------------------

## v1.73d — Unified/Safe + Periodic Quiet Guard (2026-01-26)

### Added
- **周期IDの"静寂ガード"を導入（`k####` ms）**  
  - 周期ID（002/003）は **BUSYがOFFになってから `k` ms 以上静寂が継続**した場合のみ送出  
  - **BUSY中／静寂不足／抑止中** は **延期（`periodicDue` を保持）** して次の機会に送出  
  - 既定値：`k2000`（2秒）。`k0` で静寂条件なし（従来挙動に近い）
- **要約（`q`）に `QUIET(ms)=...` を表示**  
  → 現在の静寂条件が即時に確認可能

### Changed
- **EEPROM レイアウトを更新（`config.ver = 4`）**  
  - v1.73c（`ver=3`）以前からの更新時：  
    - 新フィールド `periodQuietMs` を **既定 2000ms** で補完  
    - `tmBusyActiveHigh`/`dfpTimeoutMs` なども引き続き **安全側補完**  
  - 読込時の判定手順を強化：`magic`→`ver`→不足項目の補完→保存
- 周期スケジューラのロジックを強化  
  - **`state==IDLE` かつ `readBusy()==false`** で、**静寂時間 `k` を満たした時のみ**送出  
  - **抑止（長話/連打/送信後）** が生きている間は送出しない（延期）

### Notes
- 現場で報告のあった**「定時メッセージが割り込む」体感**を抑止する改良版  
  - 通話の"切れ目"や一瞬のスケルチ開放での誤発を防止  
  - 混雑時は **`k5000`（5秒）** など長めの設定を推奨  
- 既存の `d####`（DFPタイムアウト）, `g0/g1`（TM BUSY極性）, AUTO, 抑止 等は従来通り

--------------------------------------------------------------------

## v1.73c — Unified/Safe + Versioned EEPROM (2026-01-26)
### Added
- **EEPROM レイアウトバージョン管理（config.ver）を導入**  
  - EEPROM の "バージョン不一致" を自動検出  
  - 初期化または移行（マイグレーション）を自動実行  
- **初回読み込み時の自動補完ロジックを追加**  
  - 古い EEPROM の新規項目（tmBusyActiveHigh / dfpTimeoutMs）が未定義でも  
    安全な既定値で補完して動作  
- 要約（q）に **EEPROM_VER=3** を表示  
  → 現在ロードされているレイアウト版を即確認可能

### Changed
- EEPROM 読込時の挙動を強化：  
  - config.magic 不一致 → 完全初期化  
  - config.ver 不一致 → 移行（新規項目の既定補完）  
  - 不正値（0xFF等）は安全な値に強制補正（HIGH=busy / timeout=20000等）

### Notes
- 今後のバージョンアップで構造体に項目を追加しても、  
  **互換性を壊さず自動で安全に移行**できる仕組みが完成。  
- v1.73a/b からの移行でも、既存設定（b/n/p/w/s/t 等）は引き継がれる。

--------------------------------------------------------------------

## v1.73b — Unified/Safe + TM Busy Polarity Cmd (2026-01-22)

### Added
- g#### コマンドを追加（g0/g1）  
  - g0 = TM BUSY が **LOW=受信（アクティブLOW）**  
  - g1 = TM BUSY が **HIGH=受信（アクティブHIGH）**  
- TM BUSY 極性（g0/g1）を **EEPROM保存**  
  再起動後も極性設定を維持  
- 要約（q）に **TM_BUSY_POL=LOW/HIGH** を表示

### Changed
- readTmD6() が g0/g1 設定を完全反映  
- AUTOモード中の D6 統計処理も g0/g1 を反映  
- 古いEEPROMで tmBusyActiveHigh が不正値の時 HIGH=busy に補正

### Notes
- BUSY 出力が  
  **受信でLOWの無線機** / **受信でHIGHの無線機**  
  のどちらにも配線変更なしで対応可能に。

--------------------------------------------------------------------

## v1.73a — Unified/Safe + DFP Timeout Cmd (2026-01-22)

### Added
- d#### コマンドで DFPlayer フェイルセーフ（ms）を可変化。d0 で無効化。
- 要約 q に DFP_TIMEOUT(ms) を表示。

### Changed
- 既定タイムアウトを **20000ms（20秒）** に変更。

### Notes
- d0 でも即切断しないよう PLAYING 内判定をガードで保護。

--------------------------------------------------------------------

## v1.73-unified-safe (2026-01-22)
（完全統合・安全性強化・機種依存排除版）

### Added
- DFPlayer フェイルセーフ（8秒固定）
- A0/D6 AUTO 判定（固定型）
- Arduino視点の配線命名（ARD_RX_FROM_DFP=10 / ARD_TX_TO_DFP=11）
- STOP/RESUME（x / r）
- HELP（h）

### Changed
- "汎用プリセット（H）" を再設計（s0/t0/b3900）
- 周期IDを絶対時刻スケジューリングに
- A0/D6 前段処理を整理

### Fixed
- D10/D11 命名混乱、HTMLエスケープ残存、AUTO未固定を修正
- STOP中 LED 残点灯を修正

--------------------------------------------------------------------

## v1.72-final-EEPROM+F (2026-01-20)

### Added
- Factory Reset（F）
- EEPROM 永続化
- AUTO固定後に保存

### Changed
- x → r の動作仕様統一

### Fixed
- A0 初期化不足、HTMLエスケープ残存修正

--------------------------------------------------------------------

## v1.71-stable-final (2026-01-19)
### Added
- HELP、STOP、t0/t1
- q に LONG_TALK_MS 追加

### Fixed
- DFPlayer BUSY 戻り判定に 40ms 安定時間
- 未初期化の pinMode 等を修正

--------------------------------------------------------------------

## v1.71 (Integrated-MAX) — 2026-01-19
### Added
- b#### による MAX/LONG の統合設定
- 未使用側 LED 点滅

### Notes
- AUTO は 30 分窓

--------------------------------------------------------------------

## v1.69g (2026-01-15)
### Added
- H プリセット（s0/t0/b3900）

### Fixed
- 安定性改善

--------------------------------------------------------------------

## v1.69f (2026-01-12)
### Changed
- デフォルトを v1.67c 互換へ

--------------------------------------------------------------------

## v1.69e (2026-01-09)
### Added
- AUTO（D6/A0発生数比較）
- D13 LED 点滅通知

--------------------------------------------------------------------

## v1.69c (2026-01-09)
### Changed
- LED 優先順位見直し

--------------------------------------------------------------------

## v1.69b (2026-01-09)
### Added
- 抑止ステータスLED

### Changed
- BUSY_MAX_MS を 2500ms に拡張

--------------------------------------------------------------------

## v1.68 Series (2025-12-End)
- A0 ヒステリシス + 保持
- 長話/連打抑止追加
- Δt ログ可視化

--------------------------------------------------------------------

## v1.67 Series (2025-12-Mid)
- 送信後抑止（3秒）
- D2 へ DFPlayer ミラー出力

--------------------------------------------------------------------

## v1.64 (2025-12-Early)
- PTT最低ONガード
- BUSYヒステリシス再設計

--------------------------------------------------------------------

## Pre-v1.64 / Prototype — 2025-08〜
- v1.50：初の安定版（D6 BUSY判定、PTT PRE/POST）
- D6 monitor
- CCVoice 初期プロトタイプ

--------------------------------------------------------------------

## 付録：ピンマップ（Arduino Nano / v1.73e 時点）

 Pin | 機能 | 備考
-----|------|------
 D2  | DFP BUSYミラー出力 | 再生中=HIGH（反転）
 D3  | テストSW | INPUT_PULLUP
 D4  | 受信LED(D6) | D6/AUTO時
 D5  | PTT出力 | HIGH=送信
 D6  | TM BUSY入力 | 極性切替可（g0/g1）
 D7  | DFPlayer BUSY入力 | LOW=再生中
 D10 | Arduino RX | ← DFPlayer TX
 D11 | Arduino TX | → DFPlayer RX
 D12 | A0 LED | A0/AUTO時
 D13 | 抑止/AUTO LED | 長会話・連打・AUTO固定通知
 A0  | アナログ入力 | ヒステリシス＋保持適用

--------------------------------------------------------------------

## 付録：用語読み替え履歴

本プロジェクトでは v1.73f にてドキュメントおよびソースコードのコメント内の用語を整理しました。
変数名・定数名・関数名はコードの互換性を保つため変更していません。

| 旧表現 | 新表現 | 変更対象 | 理由 |
|---|---|---|---|
| `TM BUSY` | **受信BUSY信号** | ドキュメント・コメント | 無線機のBUSY入力であることを明確化 |
| `dur判定` | **カーチャンク判定** | ドキュメント・コメント | 受信継続時間による短発判定の目的を明確化 |
| `postTxIgnore` | **送信直後ガード** | ドキュメント・コメント | 送信直後の誤発火防止機能であることを明確化 |
| `バースト抑止` | **連打抑止** | ドキュメント・コメント | 短時間連続呼び出しの抑止であることを平易化 |
| `バースト窓` | **連打検出窓** | ドキュメント・コメント | 連打判定の計測窓であることを平易化 |
| `直前アイドル時間` | **送信後BUSY安定待ち時間** | ドキュメント・コメント | 実態（送信直後ガードの解除閾値）に合わせた名称に変更 |

### 変更していない識別子（コード互換性のため維持）

| 識別子 | 種別 | 対応する新表現 |
|---|---|---|
| `postTxIgnore` | 変数名 | 送信直後ガード |
| `postTxIdleStart` | 変数名 | 送信直後ガード解除用BUSY安定計測 |
| `BUSY_INPUT_SOURCE` | 変数名 | 受信BUSY信号ソース |
| `BURST_WIN_MS` | 定数名 | 連打検出窓時間 |
| `BURST_SUP_MS` | 定数名 | 連打抑止時間 |
| `BURST_TH` | 定数名 | 連打閾値 |
| `burstCount` | 変数名 | 連打カウンタ |
| `burstWinStart` | 変数名 | 連打検出窓開始時刻 |
| `burstSupUntil` | 変数名 | 連打抑止終了時刻 |
| `idleMin` | 構造体フィールド | 送信後BUSY安定待ち時間 |
| `IDLE_MIN_MS` | 変数名 | 送信後BUSY安定待ち時間 |
| `PIN_TM_BUSY` | 定数名 | 受信BUSY信号ピン |
| `tmBusyFiltered` | 変数名 | 受信BUSY信号（デバウンス後） |
| `TMBUSY_ACTIVE_HIGH` | 変数名 | 受信BUSY信号極性 |

--------------------------------------------------------------------
End of CHANGELOG

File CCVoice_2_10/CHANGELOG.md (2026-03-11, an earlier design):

# CHANGELOG.md - OpenCCVoice ID Guidance Controller

本プロジェクトは、Arduino Nano (ATmega328P, 5V) 上で動作する、DMR無線機の ID送出支援コントローラです。

記法: Keep a Changelog 準拠  
日付: JST（日本標準時）

--------------------------------------------------------------------

## v2.10 — DS3231 RTC 正時アライン対応版 (2026-03-11)

### Added
- **DS3231 RTC モジュール対応（I²C / A4=SDA, A5=SCL）**
  - 起動時に I²C で DS3231 の接続を自動確認。
  - 未接続・故障時は millis() 相対動作に自動フォールバック。
  - 起動ログに `[RTC] DS3231 found.` または `[RTC] DS3231 not found -> millis() fallback.` を表示。

- **周期ID の「正時アライン」方式を導入**
  - `p##` が **60の約数**（1/2/3/4/5/6/10/12/15/20/30/60分）かつ DS3231 接続時 → **毎正時基準で等間隔**にアライン。
    - 例：`p15` → 毎時 :00/:15/:30/:45 に送出
    - 例：`p10` → 毎時 :00/:10/:20/:30/:40/:50 に送出
    - 例：`p30` → 毎時 :00/:30 に送出
  - 60の約数でない値（例：`p7`）または DS3231 未接続時 → 従来の millis() 相対動作（v2.01互換）。
  - **1分ごとに DS3231 から時刻を再取得**し、millis() のドリフトを自動補正。

- **`T` コマンド（RTC 時刻設定）を追加**
  - 書式：`TYYYYMMDDHHmmss`（14桁）
  - 例：`T20260311143000` → 2026/03/11 14:30:00 に設定
  - 設定後、次回発火時刻を即座に再計算。

- **`u0/u1` コマンド（RTCアライン ON/OFF）を追加**
  - `u1`：RTCアライン有効（既定）
  - `u0`：RTCアライン無効（millis() 相対に切替）
  - EEPROM に保存。

- **`q`（設定一覧）に RTC 現在時刻とアライン状態を追加表示**
  ```
  [RTC] 2026/03/11 14:23:45  Align=ON(RTC)
  [CFG] EEPROM_VER=5 ... RTC_ALIGN=ON
  ```

- **EEPROM CONFIG_VERSION を 5 に更新**
  - `rtcAlignOn` フィールドを追加（末尾 `ver` の直前）。
  - v2.01（ver=4）からの更新時、`rtcAlignOn=1`（ON）で自動補完。
  - 既存設定（MIN/MAX/PER/TXSUP 等）はすべて引き継ぎ。

### Notes
- ピンマップは **v2.01（Ver.5 基板）から変更なし**。
- AT24C32（モジュール上の外部 EEPROM）は本バージョンでは未使用。
- DS3231 との接続は基板上の **J5 コネクタ**（SDA/SCL/VCC/GND）を使用。
- v2.01 の全機能（postTxIgnore / catch-up / A0観測継続 / 静寂ガード）を完全継承。

--------------------------------------------------------------------

## v2.01 — Ver.5 ピンマップ対応 / 仕様整理版 (2026-03-10)

### Changed
- **Ver.5 基板ピンマップへ全面移行**
  - 旧配線（v1.73e）から下記の通りピンアサインを変更：

  | 信号 | v1.73e | v2.01 (Ver.5) |
  |------|--------|---------------|
  | DF Player BUSYミラー出力 | D2 | D3 |
  | テストSW | D3 | D2 |
  | TM BUSY入力（Digital入力） | D6 | D11 |
  | DFPlayer BUSY入力 | D7 | D10 |
  | 抑止 LED | D13 | D6 |
  | A0検知 LED | D12 | D7 |
  | Arduino RX ← DFPlayer TX | D10 | D13 |
  | Arduino TX → DFPlayer RX | D11 | D12 |

- **STOP復帰コマンドを `r`（小文字）から `R`（大文字）に変更**
- **BusySrc列挙値の名称変更**（`BUSY_SRC_D6` → `BUSY_SRC_DIGITAL`）
- **STOP中のLED消灯処理を強化**（`PIN_DFP_OUT`（D3）も LOW に落とす）

### Notes
- EEPROM レイアウトは **v1.73d/e と同一（`config.ver = 4`）**。
- v1.73e で導入された全機能を完全継承。

--------------------------------------------------------------------

## v1.73e — Unified/Safe + Stability Fixes (2026-02-13)

### Added
- **送信直後ガード（postTxIgnore）を追加**
- **周期IDスケジューラの catch-up 対策**

### Changed
- **A0 BUSY 観測ロジックの安定化**（抑止中も観測継続）
- **送信直後の再発火防止を強化**

### Notes
- EEPROM レイアウトは **v1.73d と同一（`config.ver = 4`）**。

--------------------------------------------------------------------

## v1.73d — Unified/Safe + Periodic Quiet Guard (2026-01-26)

### Added
- **周期IDの"静寂ガード"を導入（`k####` ms）**
- **EEPROM レイアウトを更新（`config.ver = 4`）**

--------------------------------------------------------------------

## v1.73c — Unified/Safe + Versioned EEPROM (2026-01-26)
### Added
- **EEPROM レイアウトバージョン管理（config.ver）を導入**

--------------------------------------------------------------------

## v1.73b — Unified/Safe + TM Busy Polarity Cmd (2026-01-22)
### Added
- `g0/g1` コマンド（TM BUSY 極性切替）

--------------------------------------------------------------------

## v1.73a — Unified/Safe + DFP Timeout Cmd (2026-01-22)
### Added
- `d####` コマンドで DFPlayer フェイルセーフ（ms）を可変化

--------------------------------------------------------------------

## v1.73-unified-safe (2026-01-22)
### Added
- DFPlayer フェイルセーフ（8秒固定）
- A0/Digital AUTO 判定
- STOP/RESUME（x / R）、HELP（h）

--------------------------------------------------------------------

## v1.72-final-EEPROM+F (2026-01-20)
### Added
- Factory Reset（F）、EEPROM 永続化

--------------------------------------------------------------------

## v1.71-stable-final (2026-01-19)
### Added
- HELP、STOP、t0/t1
### Fixed
- DFPlayer BUSY 戻り判定に 40ms 安定時間

--------------------------------------------------------------------

## Pre-v1.71 / Prototype — 2025-08〜
- v1.50：初の安定版（Digital BUSY判定、PTT PRE/POST）
- CCVoice 初期プロトタイプ

--------------------------------------------------------------------

## 付録：ピンマップ（Arduino Nano / v2.01以降 Ver.5）

 Pin  | 機能                        | 備考
------|-----------------------------|------
 D2   | テストSW                    | INPUT_PULLUP（1〜3クリックでTRACK 1〜3）
 D3   | DFP BUSYミラー出力          | 再生中=HIGH（反転）
 D4   | ModBusy LED                 | BUSY表示
 D5   | PTT出力                     | HIGH=送信
 D6   | 抑止 LED                    | 抑止/バースト/POST-TX表示
 D7   | A0検知 LED                  | A0 BUSY表示
 D10  | DFPlayer BUSY入力           | LOW=再生中（INPUT_PULLUP）
 D11  | TM BUSY入力（Digital入力）  | 極性切替可（g0/g1）、INPUT_PULLUP
 D12  | Arduino TX → DFPlayer RX   | SoftwareSerial 9600bps
 D13  | Arduino RX ← DFPlayer TX   | SoftwareSerial 9600bps
 A0   | アナログ入力                | ヒステリシス＋保持適用
 A4   | I²C SDA                    | DS3231 接続（v2.10追加）
 A5   | I²C SCL                    | DS3231 接続（v2.10追加）

--------------------------------------------------------------------
End of CHANGELOG

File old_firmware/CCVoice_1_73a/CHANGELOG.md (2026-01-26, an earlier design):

# CHANGELOG.md - OpenCCVoice ID Guidance Controller

本プロジェクトは、Arduino Nano (ATmega328P, 5V) 上で動作する、DMR無線機の ID送出支援コントローラです。

記法: Keep a Changelog 準拠
日付: JST（日本標準時）

--------------------------------------------------------------------

## v1.73b — Unified/Safe + TM Busy Polarity Cmd (2026-01-22)

### Added
- g#### コマンドを追加（g0/g1）  
  - g0 = TM BUSY が **LOW=受信（アクティブLOW）**  
  - g1 = TM BUSY が **HIGH=受信（アクティブHIGH）**  
- TM BUSY 極性（g0/g1）を **EEPROM保存**  
  再起動後も極性設定を維持  
- 要約（q）に **TM_BUSY_POL=LOW/HIGH** を表示  
  接続無線機の BUSY 仕様がすぐに確認可能

### Changed
- readTmD6() が g0/g1 設定を完全反映  
- AUTOモード中の D6 統計処理も g0/g1 を反映するよう修正  
- 古いEEPROMを読み込んだ場合、tmBusyActiveHigh が不正値なら自動補正（HIGH=busy）

### Notes
- この変更により、BUSY 出力が  
  **「受信でLOW」タイプの無線機**  
  **「受信でHIGH」タイプの無線機**  
  のどちらにも配線変更なしで対応可能になった。

--------------------------------------------------------------------

## v1.73a — Unified/Safe + DFP Timeout Cmd (2026-01-22)

### Added
- d#### コマンドで DFPlayer フェイルセーフ（ms）を可変化。d0 で無効化。
- 要約 q に DFP_TIMEOUT(ms) を追加表示。

### Changed
- 既定の DFP_TIMEOUT_MS を 20000ms（20秒）に変更（長尺IDでも安定再生）。

### Notes
- フェイルセーフ無効時も、PLAYING内判定は評価スキップ（ガード実装）済み。

--------------------------------------------------------------------

## v1.73-unified-safe (2026-01-22)
（完全統合・安全性強化・機種依存排除版）

本版は、試験的要素や個別機材名称を全て撤廃し、どの環境でも使える完全汎用版として再構成した最新完成形。

### Added
- DFPlayer フェイルセーフ（8秒固定）
  BUSY が出ない／戻らない場合でも PTT の張り付きを 8 秒で強制停止。
- A0/D6 AUTO 判定（固定型）
  観測窓 w## 分間で D6 / A0 の発生数比較で自動固定（EEPROM保存）。
  固定時 D13 LED が 3 秒高速点滅。
- Arduino視点の配線命名へ完全統一
  ARD_RX_FROM_DFP=10（DFP TX） / ARD_TX_TO_DFP=11（DFP RX）
- STOP/RESUME（x / r）完全統合
- HELP（h）コマンド追加

### Changed
- 機種固有表現をすべて廃止 → 完全汎用化
- H プリセットを “汎用プリセット”（s0 / t0 / b3900）に再定義
- 周期IDを絶対時刻基準スケジューリングに統一
- A0 / D6 前段処理（ヒステリシス、統計）の整理

### Fixed
- D10/D11 の命名混乱、HTMLエスケープ残存、AUTO未固定の稀な不具合を修正
- STOP 中 LED が残点灯するケースを修正

--------------------------------------------------------------------

## v1.72-final-EEPROM+F (2026-01-20)

### Added
- Factory Reset（F）:
  初期値へ戻し EEPROMに即保存（再起動後も初期状態で起動）
- EEPROM 永続化:
  m, b, n, s, t, r, p, w, L/G/a を即保存
- AUTO 判定後、自動固定 & EEPROM保存

### Changed
- x（停止）→ r（再開）の仕様確立
- 汎用プリセット H（s0 / t0 / b4000）定義

### Fixed
- 初期化漏れ、未定義、HTMLエスケープ残存など修正

--------------------------------------------------------------------

## v1.71-stable-final (2026-01-19)

### Added
- h（ヘルプ）、x（STOP）、t0/t1
- q（要約）に LONG_TALK_MS 追加

### Fixed
- DFPlayer BUSY 戻り判定に 40ms の安定時間を追加
- pinMode 初期化漏れ、未定義など複数箇所修正

--------------------------------------------------------------------

## v1.71 (Integrated-MAX) — 2026-01-19

### Added
- b#### による BUSY_MAX_MS / LONG_TALK_MS の統合設定
- 未使用側 LED の点滅機能追加

### Notes
- AUTO は 30 分窓 + グレース

--------------------------------------------------------------------

## v1.69g (Preset & Stability) — 2026-01-15

### Added
- 汎用プリセット H（s0 / t0 / b3900）

### Fixed
- 複数の安定性・コンパイル問題を修正

--------------------------------------------------------------------

## v1.69f (Unified Architecture) — 2026-01-12

### Changed
- デフォルトを v1.67c 互換（D6固定・抑止なし）へ統一
- 必要機能はコマンドで ON する形式へ変更

--------------------------------------------------------------------

## v1.69e (AUTO Mode – Count Based) — 2026-01-09

### Added
- AUTO（D6/A0発生数比較方式）
- 決定時 D13 LED を 2Hz / 3秒点滅

--------------------------------------------------------------------

## v1.69c (Status LED Priority) — 2026-01-09

### Changed
- LED優先順位：  
  長会話 ＞ 送信後抑止 ＞ バースト ＞ OFF

--------------------------------------------------------------------

## v1.69b (Extended Limits) — 2026-01-09

### Added
- 抑止ステータス LED（D13）

### Changed
- BUSY_MAX_MS を 2500ms へ引き上げ

--------------------------------------------------------------------

## v1.68 Series (A0 Integration & Monitoring) — 2025-12-End

### Added
- A0 ヒステリシス（L/G）＋保持 a(ms)
- 長話/バーストの文脈抑止
- Δt ログ

--------------------------------------------------------------------

## v1.67 Series — 2025-12-Mid

### Added
- TX後抑止（3秒）
- DFPlayer BUSY ミラー D2 出力

--------------------------------------------------------------------

## v1.64 — 2025-12-Early

### Changed
- PTT最低ONガード
- BUSYヒステリシス

--------------------------------------------------------------------

## Pre-v1.64 / Prototype — 2025-08〜

### History
- 1.50：初の安定版（D6 BUSY判定、PTT PRE/POST）
- D6 monitor：テストツール
- CCVoice：初期プロトタイプ

--------------------------------------------------------------------

## 付録：ピンマップ（Arduino Nano / 最新 v1.73b 時点）

 Pin | 機能 | 備考
-----|------|------
 D2  | DFP BUSYミラー出力 | 再生中=HIGH（反転）
 D3  | テストSW | INPUT_PULLUP
 D4  | 受信LED(D6) | D6/AUTO時
 D5  | PTT出力 | HIGH=送信
 D6  | TM BUSY入力 | 極性切替可（g0/g1）
 D7  | DFPlayer BUSY入力 | LOW=再生中
 D10 | Arduino RX | ← DFPlayer TX
 D11 | Arduino TX | → DFPlayer RX
 D12 | A0 LED | A0/AUTO時
 D13 | 抑止/AUTO LED | 長会話・バースト・AUTO固定通知
 A0  | アナログ入力 | ヒステリシス＋保持適用

--------------------------------------------------------------------

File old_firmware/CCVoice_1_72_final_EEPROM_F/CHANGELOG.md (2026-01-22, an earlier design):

/************************************************************
 * OpenCCVoice Guidance Controller  (Unified & Configurable)
 * Version : 1.72-H1-Compatible-Safe
 * Target  : Arduino Nano (ATmega328P, 5V)
 *
 * 【本版について】
 * - v1.69g のハード配線（RX=10 / TX=11）を維持したまま動作
 * - 入力は INPUT_PULLUP（浮き対策）
 * - 既定値は H1 仕様（BUSY_MAX_MS=3900ms）
 * - DFPlayer 応答なし時に 8 秒で強制停止（フェイルセーフ）
 * - EEPROM 永続化 / Factory Reset（F）/ AUTO 判定固定 / STOP（x）/ RESUME（r）
 *
 * 【操作・設定ガイド（115200bps）】
 *  - モード       : m0=D6固定 / m1=A0固定 / m2=AUTO（w分の観測後に固定保存）
 *  - 受信しきい値 : n500（最短ms）/ b3900（最長ms＝LONG）
 *  - 抑止        : s0/s1（OFF/ON）
 *  - 送信後抑止   : t0/t1（OFF/ON） / r####（ms）
 *  - 周期ID      : p##（分、002/003交互）
 *  - A0感度      : L### / G### / a####（保持ms）
 *  - AUTO窓      : w##（分）
 *  - 要約/停止   : q / x→停止, r→再開
 *  - プリセット   : H（s0/t0/b3900）
 *  - 初期化       : F（Factory Reset：初期値に戻す＆EEPROM保存）
 *
 * 【注意】
 * - A0とD6は同時接続不可（片側のみ配線）。
 ************************************************************/

#include <Arduino.h>
#include <SoftwareSerial.h>
#include <EEPROM.h>

/* ============================================================
   ■ EEPROM保存用データ構造
   ============================================================ */
struct MyConfig {
  uint32_t magic;
  uint8_t  busySrc;    // [m] 0:D6, 1:A0, 2:AUTO
  uint8_t  suppressOn; // [s] 0:OFF, 1:ON
  uint8_t  txAfSupOn;  // [t] 0:OFF, 1:ON
  uint32_t busyMin;    // [n]
  uint32_t busyMax;    // [b]（＝LONGと統合）
  uint32_t idleMin;    // [i]
  uint32_t periodMin;  // [p]（分）
  uint32_t txSupMs;    // [r]
  int      a0Low;      // [L]
  int      a0High;     // [G]
  uint32_t a0Hold;     // [a]
  uint32_t autoWinMin; // [w]（分）
} config;

const uint32_t CONFIG_MAGIC = 0xDEADBEEF;

/* ============================================================
   ■ 動作パラメータ
   ============================================================ */
enum BusySrc { BUSY_SRC_D6, BUSY_SRC_A0, BUSY_SRC_AUTO };
volatile BusySrc BUSY_INPUT_SOURCE;
bool SUPPRESSORS_ENABLED;
bool TX_AFTER_SUPPRESS_ENABLED;
unsigned long BUSY_MIN_MS;
unsigned long BUSY_MAX_MS;
unsigned long IDLE_MIN_MS;
unsigned long PERIOD_MS;
unsigned long TX_SUP_MS;
int A0_LOW_TH;
int A0_HIGH_TH;
unsigned long A0_HOLD;
unsigned long AUTO_WINDOW;
unsigned long LONG_TALK_MS;

/* ============================================================
   ■ ピン定義（v1.69g配線に準拠）
   ============================================================ */
const bool TMBUSY_ACTIVE_HIGH = true;
const bool DFP_BUSYOUT_INVERT = true;

const uint8_t PIN_TEST_SW = 3;     // D3
const uint8_t PIN_BUSY_LED = 4;    // D4
const uint8_t PIN_PTT     = 5;     // D5
const uint8_t PIN_TM_BUSY = 6;     // D6（BUSY）
const uint8_t PIN_DFP_BSY = 7;     // D7（DFP BUSY: 多くの個体で LOW=再生中）
const uint8_t PIN_DFP_OUT = 2;     // D2（BUSYミラー）
const uint8_t PIN_SUP_LED = 13;    // D13（抑止/AUTO通知）
const uint8_t PIN_A0_LED  = 12;    // D12（A0表示）

// ここが重要：v1.69g の配線を変えずに動かすため、
// SoftwareSerial の引数（(RX,TX)）に対して「PIN_DFP_TX=10 を RX として使用」します。
const uint8_t PIN_DFP_TX  = 10;    // D10（実際は SoftwareSerial の RX として動作）
const uint8_t PIN_DFP_RX  = 11;    // D11（実際は SoftwareSerial の TX として動作）
const uint8_t A0_PIN      = A0;

#define USE_A0_FRONT 1

// v1.69g互換（配線そのまま）で動作させるための初期化
SoftwareSerial dfpSerial(PIN_DFP_TX, PIN_DFP_RX);  // (RX=10, TX=11)

/* ============================================================
   ■ 定数・安全機能
   ============================================================ */
const unsigned long REFRAC_MS    = 3000;
const unsigned long DEBOUNCE_MS  = 5;
const unsigned long PTT_PRE_MS   = 1000;
const unsigned long PTT_POST_MS  = 1000;
const unsigned long LONG_SUP_MS  = 10000;
const unsigned long BURST_WIN_MS = 10000;
const unsigned int  BURST_TH     = 2;
const unsigned long BURST_SUP_MS = 10000;

// DFPlayer応答なし時のフェイルセーフ（最大再生時間）
const unsigned long DFP_TIMEOUT_MS = 8000;

/* ============================================================
   ■ 内部状態
   ============================================================ */
unsigned long windowStartTS = 0, autoSwitchBlinkUntil = 0;
bool autoLocked = false;

enum LogLvl { LOG_NONE=0, LOG_ERR=1, LOG_INF=2, LOG_DBG=3 };
volatile LogLvl LOG_LEVEL = LOG_INF;

enum State { IDLE, PTT_ON_WAIT, PLAYING, PTT_OFF_WAIT };
State state = IDLE;

unsigned long tmBusyStart=0, tmDebounceTS=0, a0LastSignalTS=0;
bool tmBusyPrev=false, tmBusyFiltered=false, a0Detect=false, a0Busy=false;

unsigned long lastTriggerAt=0, stateTimer=0, pttMinOn=0, nextPeriodicAt=0;
bool dfpStarted=false, lastBusyLow=false, pttOutState=false;
bool periodicDue=false, clickWaiting=false, stopped=false;
uint16_t requestedTrack=0, nextPeriodicTrack=2;
unsigned long busySupUntil=0, longSupUntil=0, burstWinStart=0, burstSupUntil=0;
unsigned long busyHighSince=0;

uint8_t clickCount=0, lastSwState=HIGH;
unsigned long firstClickTime=0;
unsigned int burstCount = 0;
uint16_t d6_edge_count = 0;
uint16_t a0_event_count = 0;

// フェイルセーフ用
unsigned long playingEnterAt = 0;

/* ============================================================
   ■ ユーティリティ
   ============================================================ */
inline bool readTmRaw() { return (digitalRead(PIN_TM_BUSY) == HIGH); }
inline bool readTmD6()  { return TMBUSY_ACTIVE_HIGH ? readTmRaw() : !readTmRaw(); }
inline bool readBusy()  {
  if (BUSY_INPUT_SOURCE == BUSY_SRC_D6) return tmBusyFiltered;
  if (BUSY_INPUT_SOURCE == BUSY_SRC_A0) return a0Busy;
  // AUTO中は D6/A0 どちらでも短発候補（現仕様）
  return (tmBusyFiltered || a0Busy);
}

void formatUptime(unsigned long ms, char* buf, size_t n) {
  unsigned long t = ms;
  unsigned long h = t / 3600000UL; t %= 3600000UL;
  unsigned long m = t / 60000UL;   t %= 60000UL;
  unsigned long s = t / 1000UL;
  unsigned long mm = t % 1000UL;
  snprintf(buf, n, "%02lu:%02lu:%02lu.%03lu", h, m, s, mm);
}

void dfpSend(uint8_t cmd, uint16_t param) {
  uint8_t f[10] = {0x7E,0xFF,0x06,cmd,0x00,(uint8_t)(param>>8),(uint8_t)(param & 0xFF),0x00,0x00,0xEF};
  uint16_t s = 0; for (int i = 1; i < 7; i++) s += f[i];
  s = 0xFFFF - s + 1; f[7] = (uint8_t)(s >> 8); f[8] = (uint8_t)s;
  dfpSerial.write(f, 10);
}

void setPtt(bool on) {
  if (pttOutState == on) return;
  pttOutState = on;
  digitalWrite(PIN_PTT, on ? HIGH : LOW);
  if (LOG_LEVEL >= LOG_INF) {
    Serial.print(F("[PTT] ")); Serial.println(on ? F("ON") : F("OFF"));
  }
}

void startPtt(uint16_t trk) {
  if (state != IDLE) return;
  requestedTrack = trk; dfpStarted = false; lastBusyLow = false;
  unsigned long now = millis(); setPtt(true);
  pttMinOn = now + PTT_PRE_MS + 100;
  stateTimer = now;
  playingEnterAt = 0;  // 再生フェーズの開始は PTT_ON_WAIT → PLAYING で記録
  state = PTT_ON_WAIT;
}

/* ============================================================
   ■ EEPROM 入出力
   ============================================================ */
void saveSettings() {
  config.magic      = CONFIG_MAGIC;
  config.busySrc    = (uint8_t)BUSY_INPUT_SOURCE;
  config.suppressOn = SUPPRESSORS_ENABLED ? 1 : 0;
  config.txAfSupOn  = TX_AFTER_SUPPRESS_ENABLED ? 1 : 0;
  config.busyMin    = BUSY_MIN_MS;
  config.busyMax    = BUSY_MAX_MS;
  config.idleMin    = IDLE_MIN_MS;
  config.periodMin  = PERIOD_MS / 60000UL;
  config.txSupMs    = TX_SUP_MS;
  config.a0Low      = A0_LOW_TH;
  config.a0High     = A0_HIGH_TH;
  config.a0Hold     = A0_HOLD;
  config.autoWinMin = AUTO_WINDOW / 60000UL;
  EEPROM.put(0, config);
  if (LOG_LEVEL >= LOG_INF) Serial.println(F("[EEPROM] Settings Saved."));
}

void applyDefaults() {
  BUSY_INPUT_SOURCE = BUSY_SRC_D6;
  SUPPRESSORS_ENABLED = true;
  TX_AFTER_SUPPRESS_ENABLED = true;
  BUSY_MIN_MS = 500;
  BUSY_MAX_MS = 3900;   // H1 仕様
  IDLE_MIN_MS = 200;
  PERIOD_MS   = 30UL * 60UL * 1000UL;
  TX_SUP_MS   = 3000;
  A0_LOW_TH   = 300; A0_HIGH_TH = 700; A0_HOLD = 800;
  AUTO_WINDOW = 30UL * 60UL * 1000UL;
  LONG_TALK_MS = BUSY_MAX_MS;
  autoLocked = false;
}

void loadSettings() {
  EEPROM.get(0, config);
  if (config.magic != CONFIG_MAGIC) {
    Serial.println(F("[EEPROM] No Data. Using Defaults..."));
    applyDefaults();
  } else {
    BUSY_INPUT_SOURCE = (BusySrc)config.busySrc;
    SUPPRESSORS_ENABLED = (config.suppressOn == 1);
    TX_AFTER_SUPPRESS_ENABLED = (config.txAfSupOn == 1);
    BUSY_MIN_MS = config.busyMin; BUSY_MAX_MS = config.busyMax;
    IDLE_MIN_MS = config.idleMin; PERIOD_MS = (unsigned long)config.periodMin * 60000UL;
    TX_SUP_MS = config.txSupMs; A0_LOW_TH = config.a0Low; A0_HIGH_TH = config.a0High;
    A0_HOLD = config.a0Hold; AUTO_WINDOW = (unsigned long)config.autoWinMin * 60000UL;
    LONG_TALK_MS = BUSY_MAX_MS;
    autoLocked = (BUSY_INPUT_SOURCE != BUSY_SRC_AUTO);
    Serial.println(F("[EEPROM] Settings Loaded."));
  }
}

void printSummary() {
  Serial.print(F("[CFG] SRC="));
  if (BUSY_INPUT_SOURCE == BUSY_SRC_AUTO) Serial.print(F("AUTO"));
  else Serial.print(BUSY_INPUT_SOURCE==BUSY_SRC_D6?F("D6"):F("A0"));
  if (autoLocked) Serial.print(F("(LOCK)"));
  Serial.print(F(" MIN="));  Serial.print(BUSY_MIN_MS);
  Serial.print(F(" MAX="));  Serial.print(BUSY_MAX_MS);
  Serial.print(F(" LONG=")); Serial.print(LONG_TALK_MS);
  Serial.print(F(" PER(min)=")); Serial.print(PERIOD_MS/60000UL);
  Serial.print(F(" TXSUP=")); Serial.print(TX_SUP_MS);
  Serial.print(F(" A0[L/H]=")); Serial.print(A0_LOW_TH); Serial.print('/'); Serial.print(A0_HIGH_TH);
  Serial.print(F(" HOLD=")); Serial.print(A0_HOLD);
  Serial.print(F(" AUTO(min)=")); Serial.println(AUTO_WINDOW/60000UL);
}

/* ============================================================
   ■ コマンド解析
   ============================================================ */
void handleSerialCmd() {
  while (Serial.available()) {
    char c = Serial.read();
    unsigned long timeout = millis() + 150;
    while (!Serial.available() && millis() < timeout) { }
    long val = Serial.parseInt();
    bool chg = true;
    switch (c) {
      case 'm':
        if      (val==0) { BUSY_INPUT_SOURCE=BUSY_SRC_D6;  autoLocked=true; }
        else if (val==1) { BUSY_INPUT_SOURCE=BUSY_SRC_A0;  autoLocked=true; }
        else if (val==2) { BUSY_INPUT_SOURCE=BUSY_SRC_AUTO;autoLocked=false; windowStartTS=millis(); d6_edge_count=0; a0_event_count=0; }
        else chg=false;
        break;
      case 'b': if (val>=500) { BUSY_MAX_MS=val; LONG_TALK_MS=val; } else chg=false; break;
      case 'n': if (val>=100) BUSY_MIN_MS=val; else chg=false; break;
      case 's': if (val==0||val==1) SUPPRESSORS_ENABLED=(val==1); else chg=false; break;
      case 't': if (val==0||val==1) TX_AFTER_SUPPRESS_ENABLED=(val==1); else chg=false; break;
      case 'i': if (val>=0)   IDLE_MIN_MS=val; else chg=false; break;
      case 'p': if (val>=1)   PERIOD_MS = (unsigned long)val * 60UL * 1000UL; else chg=false; break;
      case 'r': if (val>=0)   TX_SUP_MS = (unsigned long)val; else chg=false; break;
      case 'L': A0_LOW_TH  = (int)val; break;
      case 'G': A0_HIGH_TH = (int)val; break;
      case 'a': if (val>=0)   A0_HOLD = (unsigned long)val; else chg=false; break;
      case 'w': if (val>=1) { AUTO_WINDOW = (unsigned long)val * 60UL * 1000UL; windowStartTS=millis(); d6_edge_count=0; a0_event_count=0; } else chg=false; break;
      case 'q': printSummary(); chg=false; break;
      case 'H': SUPPRESSORS_ENABLED=false; TX_AFTER_SUPPRESS_ENABLED=false; BUSY_MAX_MS=3900; LONG_TALK_MS=3900; break;
      case 'x': {
        char up[20]; formatUptime(millis(), up, sizeof(up));
        Serial.print(F("[STOP] uptime=")); Serial.println(up);
        stopped = true; chg=false; break;
      }
      case 'F': {
        applyDefaults();
        saveSettings();
        Serial.println(F("[RESET] Factory defaults restored (H1 Spec)."));
        chg=false; break;
      }
      case '0': case '1': case '2': case '3':
        LOG_LEVEL = (LogLvl)(c - '0'); chg=false; break;
      default:
        chg=false; break;
    }
    if (chg) { saveSettings(); printSummary(); }
  }
}

/* ============================================================
   ■ AUTO 判定固定
   ============================================================ */
void maybeAuto(unsigned long now) {
  if (BUSY_INPUT_SOURCE != BUSY_SRC_AUTO || autoLocked) return;
  if ((long)(now - windowStartTS) >= (long)AUTO_WINDOW) {
    BusySrc n;
    uint16_t d6 = d6_edge_count, a0 = a0_event_count;
    if      (d6 < 10 && a0 >= 20) n = BUSY_SRC_A0;
    else if (a0 < 20 && d6 >= 10) n = BUSY_SRC_D6;
    else n = (d6 >= a0) ? BUSY_SRC_D6 : BUSY_SRC_A0;

    BUSY_INPUT_SOURCE = n; autoLocked = true;
    autoSwitchBlinkUntil = now + 3000;
    saveSettings();

    Serial.print(F("[AUTO-FIXED] Lock to "));
    Serial.println(n==BUSY_SRC_D6?F("D6"):F("A0"));
  }
}

/* ============================================================
   ■ セットアップ & メインループ
   ============================================================ */
void setup() {
  Serial.begin(115200);
  dfpSerial.begin(9600);
  loadSettings();

  pinMode(PIN_TEST_SW, INPUT_PULLUP);
  pinMode(PIN_BUSY_LED, OUTPUT);
  pinMode(PIN_PTT,      OUTPUT);

  // v1.69g準拠：安定化のためプルアップ運用
  pinMode(PIN_TM_BUSY, INPUT_PULLUP);
  pinMode(PIN_DFP_BSY, INPUT_PULLUP);

  pinMode(PIN_DFP_OUT, OUTPUT);
  pinMode(PIN_SUP_LED, OUTPUT);
  pinMode(PIN_A0_LED,  OUTPUT);

  delay(500);
  dfpSend(0x06, 20); // 音量

  unsigned long now = millis();
  nextPeriodicAt = now + PERIOD_MS;
  windowStartTS  = now;

  Serial.println(F("[START] OpenCCVoice v1.72-H1-Compatible-Safe (HW:v1.69g / Logic:v1.72 / +Failsafe)"));
  printSummary();
}

void loop() {
  unsigned long now = millis();
  handleSerialCmd();

  // STOP 中はすべて停止
  if (stopped) {
    setPtt(false);
    digitalWrite(PIN_BUSY_LED, LOW);
    digitalWrite(PIN_A0_LED,   LOW);
    digitalWrite(PIN_SUP_LED,  LOW);
    if (Serial.available()) {
      char c = Serial.read();
      if (c == 'r') { stopped = false; Serial.println(F("[RESUME]")); }
    }
    delay(5);
    return;
  }

  bool pAct = (state != IDLE) || ((long)now < (long)pttMinOn);

  // D7 BUSY → D2 ミラー
  bool dLow = (digitalRead(PIN_DFP_BSY) == LOW);
  digitalWrite(PIN_DFP_OUT, DFP_BUSYOUT_INVERT ? (dLow ? HIGH : LOW)
                                               : (dLow ? LOW  : HIGH));

  // D6（デバウンス／立上りカウント）
  bool rTm = readTmD6();
  if (rTm != tmBusyFiltered && (now - tmDebounceTS) >= DEBOUNCE_MS) {
    tmBusyFiltered = rTm; tmDebounceTS = now;
    if (tmBusyFiltered) d6_edge_count++;
  }

#if USE_A0_FRONT
  // A0（抑止中は無効）
  if (!pAct && (long)(now - busySupUntil) >= 0) {
    int v = analogRead(A0_PIN);
    if (!a0Detect && v < A0_LOW_TH) a0Detect = true;
    else if (a0Detect && v > A0_HIGH_TH) { a0Detect = false; a0_event_count++; }
    if (a0Detect) a0LastSignalTS = now;
    a0Busy = a0Detect || (a0LastSignalTS!=0 && (now - a0LastSignalTS < A0_HOLD));
  } else { a0Detect = false; a0Busy = false; }
#endif

  // LED（未使用側は点滅）
  bool bl = ((now / 500) % 2 == 0);
  bool rB = readBusy();
  if (BUSY_INPUT_SOURCE == BUSY_SRC_D6) {
    digitalWrite(PIN_BUSY_LED, rB ? HIGH : LOW);
    digitalWrite(PIN_A0_LED,   a0Busy ? HIGH : (bl ? HIGH : LOW));
  } else if (BUSY_INPUT_SOURCE == BUSY_SRC_A0) {
    digitalWrite(PIN_A0_LED,   rB ? HIGH : LOW);
    digitalWrite(PIN_BUSY_LED, tmBusyFiltered ? HIGH : (bl ? HIGH : LOW));
  } else {
    digitalWrite(PIN_BUSY_LED, tmBusyFiltered ? HIGH : (bl ? HIGH : LOW));
    digitalWrite(PIN_A0_LED,   a0Busy         ? HIGH : (bl ? HIGH : LOW));
  }

  // 受信イベント → 判定
  if (!pAct && !(SUPPRESSORS_ENABLED && (long)(now - busySupUntil) < 0)) {
    if (rB) {
      if (!tmBusyPrev) tmBusyStart = now;
    } else if (tmBusyPrev) {
      unsigned long dur = now - tmBusyStart;

      if (SUPPRESSORS_ENABLED) {
        if (dur >= BUSY_MAX_MS) longSupUntil = now + LONG_SUP_MS;
        if (dur >= BUSY_MIN_MS && dur < BUSY_MAX_MS) {
          if (burstWinStart==0 || (now-burstWinStart >= BURST_WIN_MS)) {
            burstWinStart=now; burstCount=0;
          }
          if (++burstCount >= BURST_TH) burstSupUntil = now + BURST_SUP_MS;
        }
      }

      bool allowed = !(SUPPRESSORS_ENABLED &&
                       ((long)(now-longSupUntil)<0 || (long)(now-burstSupUntil)<0));
      if (dur >= BUSY_MIN_MS && dur < BUSY_MAX_MS &&
          (now-lastTriggerAt >= REFRAC_MS) && allowed) {
        startPtt(1);
        lastTriggerAt = now;
      }
    }
  }
  tmBusyPrev = rB;

  // 周期ID
  if ((long)(now - nextPeriodicAt) >= 0) { periodicDue = true; nextPeriodicAt += PERIOD_MS; }
  if (periodicDue && state == IDLE) {
    if (LOG_LEVEL >= LOG_INF) Serial.println(F("[EVT] Periodic ID"));
    startPtt(nextPeriodicTrack);
    nextPeriodicTrack = (nextPeriodicTrack==2?3:2);
    periodicDue = false;
  }

  // 抑止・AUTO通知 LED
  bool s = SUPPRESSORS_ENABLED &&
           ((long)(now-longSupUntil)<0 || (long)(now-burstSupUntil)<0 || (long)(now-busySupUntil)<0);
  digitalWrite(PIN_SUP_LED, (long)(autoSwitchBlinkUntil-now)>0 ? ((now/250)%2==0?HIGH:LOW)
                                                              : (s?HIGH:LOW));

  // ステートマシン
  switch (state) {
    case PTT_ON_WAIT:
      if (now-stateTimer >= PTT_PRE_MS) {
        if (requestedTrack) { dfpSend(0x03, requestedTrack); requestedTrack = 0; }
        state = PLAYING;
        playingEnterAt = now;  // フェイルセーフ開始時刻
      }
      break;

    case PLAYING:
      if (dLow) {
        if (!lastBusyLow && LOG_LEVEL >= LOG_INF) Serial.println(F("[DFP] Start"));
        lastBusyLow = true; dfpStarted = true; busyHighSince = 0;
      } else {
        if (dfpStarted) {
          if (busyHighSince == 0) busyHighSince = now;
          if (now - busyHighSince >= 40) {
            state = PTT_OFF_WAIT; stateTimer = now;
            if (LOG_LEVEL >= LOG_INF) Serial.println(F("[DFP] End"));
          }
        }
      }
      // フェイルセーフ：BUSYが出ない／戻らないときの強制停止
      if (playingEnterAt > 0 && (now - playingEnterAt >= DFP_TIMEOUT_MS)) {
        if (LOG_LEVEL >= LOG_ERR) Serial.println(F("[ERR] DFP Timeout -> Force PTT OFF"));
        state = PTT_OFF_WAIT; stateTimer = now;
      }
      break;

    case PTT_OFF_WAIT:
      if (now-stateTimer >= PTT_POST_MS && now >= pttMinOn) {
        setPtt(false); state = IDLE;
        if (SUPPRESSORS_ENABLED && TX_AFTER_SUPPRESS_ENABLED)
          busySupUntil = now + TX_SUP_MS;
      }
      break;
  }

  // 最低ONガード
  if ((long)now < (long)pttMinOn) setPtt(true);

  // テストSW（1〜3クリック＝トラック1〜3）
  bool sw = digitalRead(PIN_TEST_SW);
  if (sw == LOW && lastSwState == HIGH) {
    if (!clickWaiting) { clickWaiting = true; clickCount = 1; firstClickTime = now; }
    else clickCount++;
  }
  lastSwState = sw;
  if (clickWaiting && (now - firstClickTime >= 1000)) {
    if (state == IDLE && clickCount >= 1 && clickCount <= 3) startPtt(clickCount);
    clickWaiting = false; clickCount = 0;
  }

  // AUTO
  maybeAuto(now);
}

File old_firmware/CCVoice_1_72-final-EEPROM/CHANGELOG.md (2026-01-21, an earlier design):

# CHANGELOG.md - TM-8250 ID Guidance Controller

本プロジェクトは、Arduino Nano (ATmega328P, 5V) 上で動作する、TM-8250系無線機の **ID送出支援**コントローラです。

> **記法:** Keep a Changelog 準拠  
> **日付:** JST（日本標準時）

---

## [v1.72-final-EEPROM+F] - 2026-01-20 (Factory Reset 対応 / Final Release)
**概要:** 1.72 系列の最終完成形。現場運用の「安定性」「永久設定保持」「誤操作対策」を統合した版。

### Added
- **Factory Reset（F コマンド）追加**  
  - `F` を受信すると `applyDefaults()` を実行し、**すべての設定を初期値に戻す**。  
  - その後 `saveSettings()` を実行し、EEPROM も即時初期化。  
  - 電源再投入後も「初期値の状態」で起動する安全設計。

- **EEPROM設定保存（永続化）**  
  - m, b, n, s, t, r, p, w, L/G/a など主要な全パラメータが即保存される。  
  - 書込み後、再起動しても同じ設定で開始。

- **AUTOモード：確定固定（One-Shot Lock + 永続保存）**  
  - AUTO判定後、優位ソース(D6/A0)へ自動固定し **autoLocked = true**。  
  - さらに EEPROM に保存するため、再起動しても固定モードを保持。

### Changed
- **取扱説明書／コマンド体系の整合性**  
  - `x`（停止）→`r`（再開）の動作を整理。  
  - `H` プリセット（s0/t0/b4000）の仕様を最終版として確定。

### Fixed
- **burstCount 未定義によるビルドエラーを修正。**  
- **A0フロントの有効化フラグ（USE_A0_FRONT）を明示的に 1 に設定。**
- **HTMLエスケープ（&lt; / &gt;）残存を除去**し、Arduino IDE で確実にビルド可にした。

---

## [v1.71-stable-final] - 2026-01-19
**概要:** 安定化パッチの集大成。DFPlayer・AUTO・pinMode の最終調整版。

### Fixed
- **DFPlayer 終了判定の早期遷移を防止**  
  - BUSY の HIGH戻り後、40ms の安定時間を追加（`busyHighTS != 0` 条件）。
- **A0_PIN 未定義の修正**  
- **pinMode 初期化誤り修正（INPUT/OUTPUT の誤設定を全て是正）**

### Added
- `h`（ヘルプ）、`x`（STOP）、`t0/t1` を完全実装  
- 状態要約 `q` に `LONG_TALK_MS` を追加

### Changed
- AUTOモードの見える化：D6/A0 のリアル反応＋点滅で判別性向上

---

## [v1.71] - 2026-01-19 (Integrated-MAX)
**概要:** CHUNK上限と長話判定の閾値を統合し、設定を一元化した版。

### Added
- **BUSY_MAX_MS と LONG_TALK_MS の統合制御**（`b####` のみで両方更新）
- **未使用側LEDの点滅仕様**（D6/A0の可視化）

### Notes
- AUTO は 30分窓 + 5分グレース

---

## [v1.69g] - 2026-01-15 (H1 Preset Hotfix)
**概要:** H1リピータ（2〜4秒の長いカーチャンク）用の緊急改善版。

### Added
- **H1プリセット：'H' → s0 / t0 / b3900**  
  H1環境 2.3〜3.9s の CHUNK を全て 1発で ID 扱い可能に。

### Fixed
- コンパイルエラーの修正

---

## [v1.69f] - 2026-01-12 (Unified Architecture)
**概要:** 全機能をひとつの共通アーキテクチャに統合。

### Changed
- 既定設定を **v1.67c 互換（D6固定・抑止なし）** へ統一。  
- 必要な機能をコマンドで ON にする構成へ変更。

---

## [v1.69e] - 2026-01-09 (AUTO Mode C)
### Added
- AUTO（方式C）を初実装。D6/A0 の発生数で自動決定し固定。
- 固定時、D13 LED を 2Hz で 3 秒点滅。

---

## [v1.69c] - 2026-01-09 (Status LED Priority)
### Changed
- D13 LED の優先順位  
  長会話 > TX後抑止 > バースト > OFF

---

## [v1.69b] - 2026-01-09 (Extended Limits)
### Added
- 抑止ステータスLED（D13）  
### Changed
- BUSY_MAX_MS を 2500ms へ拡張（LONG_TALK_MS と同期）

---

## [v1.68] Series - 2025-12-End (A0 Integration & Monitoring)
### Added
- A0 検知ヒステリシス（L/G）＋保持 a（800ms）  
- 文脈抑止（長会話 / バースト）  
- Δt ログの可視化

---

## [v1.67] Series - 2025-12-Mid
### Added
- TX後抑止（3秒）  
- DFPlayer BUSY ミラー D2 出力

---

## [v1.64] - 2025-12-Early
### Changed
- PTT最低ONガード  
- BUSYヒステリシス

---

## [Pre-v1.64 / Prototype] - 2025-08 ~
### History
- 1.50：初の安定版（D6 BUSY判定、PTT PRE/POST）  
- D6 monitor：D6テストツール  
- CCVoice：最初期プロトタイプ

---

## 付録：ピンマップ（Arduino Nano v1.72 時点）
| Pin | 機能 | 備考 |
|:---:|:--- |:--- |
| D2  | DFP BUSYミラー出力 | 再生中=HIGH |
| D3  | テストSW | INPUT_PULLUP |
| D4  | 受信LED (D6) | D6/AUTO時 |
| D5  | PTT出力 | HIGH=送信 |
| D6  | TM BUSY入力 | HIGH=受信 |
| D7  | DFPlayer BUSY入力 | LOW=再生中 |
| D10 | SoftwareSerial TX | → DFPlayer RX |
| D11 | SoftwareSerial RX | ← DFPlayer TX |
| D12 | A0受信LED | A0/AUTO時 |
| D13 | 抑止ステータスLED | 長会話/バースト等 |
| A0  | アナログ入力 | NJM2072出力へ接続 |

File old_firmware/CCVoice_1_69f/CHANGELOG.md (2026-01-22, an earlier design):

# CHANGELOG

> 本プロジェクト（TM-8250 ID Guidance Controller）は、Arduino Nano (ATmega328P, 5V) 上で動作する、TM-8250系無線機の **ID送出支援**コントローラです。本`CHANGELOG.md`は **v1.67c → v1.69b** までの変遷を、できる限り詳細に記録しています。
>
> 記法は [Keep a Changelog](https://keepachangelog.com/ja-JP/1.0.0/) を参考にし、カテゴリ（Added/Changed/Fixed/Maintained/Removed/Deprecated/Known Issues/Migration）で整理しています。
>
> 日付は JST（日本標準時）での作業基準です。

---

# CHANGELOG

## 1.69g-unified-H1 (2026-01-19)
### Fixed
- **ビルド不能のシンタックスエラーを修正**
  - `Serial.println(F("[Periodic] played -> toggle next"]));` の余計な `]` を削除。
  - `formatUptime(millis(), up, sizeof(up]);` の括弧不一致を修正。
### Changed
- 起動バナーを **H1専用プリセット表記** に統一：`[BOOT] 1.69g-unified-H1 (H1プリセット既定)`
- バージョン表記のみ更新（ロジック仕様に変更なし）。
### Notes
- 仕様や既定値は **1.69f** と同一（**H1クイックプリセット既定**）。
  - 既定：`BUSY_INPUT_SOURCE=D6` / `SUPPRESSORS=OFF (s0)` / `TX_AFTER=OFF (t0)` / `D4_BLINK=OFF (l0)` / `BUSY_MAX_MS=3000` / `LONG_TALK_MS=3000`
  - `b####` で `BUSY_MAX_MS` を変更した場合、`LONG_TALK_MS` は自動的に同値へペアリング。
- A0/D6の**同時使用は不可**（どちらか一方のみ接続）。AUTO（方式C）は30分窓+5分グレース、切替時にD13で3秒高速点滅通知。
- DFPlayerの基本制御、PTTフェーズ（`PTT_PRE_MS=1000` / `PTT_POST_MS=1000` / 最低ONガード `+50ms`）、周期ID（30分間隔で002/003交互）などの動作は変更なし。

## 1.69f-unified-H1 (2026-01-18)
### Added
- **H1カーチャンク即復旧プリセット**を既定化（H1現場でデグレ即回避）  
  - `H` コマンドで `s0 / t0 / l0 / b3000` を一括適用。
- **AUTO（方式C）** の実装  
  - `m2` で有効。観測窓30分の活動（`d6_edge_count` / `a0_event_count`）から **A0/D6のいずれかに自動固定**（同時使用なし）。
  - 切替時、D13を3秒間 2Hz 高速点滅で通知。
### Changed
- `b####` 設定時に `LONG_TALK_MS` を **自動で同値にペアリング**（上限一体化で調整ミス防止）。
- 受信LED（D4）の上限超過点滅は既定OFF（`l0`）。必要時 `l1` で有効化。
### Notes
- 既定のBUSYソースは **D6固定**（H1向け）。A0使用時は別ビルド（HOLD 600/800ms）を推奨。
- DMR/SFR運用では**アナログ音声IDは乗らない**ため、**FMでテスト**すること。
- A0/D6の**同時配線は不可**。

## [1.69f-unified] - 2026-01-09
### Goal
- **ゼロデグレ既定**（v1.67c互換）：D6のみ／抑止OFF／TX後抑止OFF／CHUNK 500..1500／D4純受信。
- 追加機能（抑止・D13表示・D4上限点滅・A0運用・AUTO切替）は **任意でON**（ランタイムで切替）。

### Added
- シリアルコマンドで動作モードを切替：
  - `m0/m1/m2`（D6/A0/Auto）
  - `s0/s1`（抑止OFF/ON）
  - `t0/t1`（TX後抑止OFF/ON）
  - `l0/l1`（D4上限超過点滅OFF/ON）
  - `b####`（BUSY_MAX_MSを設定 → LONG_TALK_MSとペアリング）
- 方式C（運用中の自動切替）を **AUTO選択時のみ**評価。

### Maintained
- 周期ID（30分/002-003交互）、D7→D2ミラー、テストSW（1/2/3クリック）。

### Notes
- 既定は **完全に v1.67c互換**。追加機能は **明示的にON**しない限り動作しません（統合によるデグレなし）。

## [1.69e] - 2026-01-09
### Added
- **方式C（運用中の自動切替）**を実装：起動時 UNDECIDED → 運用中の活動で D6/A0 を自動判定・固定。
  - D6無活動 + A0活動あり → A0へ。A0無活動 + D6活動あり → D6へ。
  - 切替直後は 1秒 判定停止（安全策）、D13を **2Hz点滅で3秒** 通知。
- **D4（BUSY LED）の上限超過点滅**：受信継続中に `dur > BUSY_MAX_MS` で **1Hz点滅**（受信終了まで）。

### Maintained
- 統一の抑止ロジック：長会話（dur≥`LONG_TALK_MS`→10s）、バースト（10s窓2回→10s）、TX後（3s）。
- D13抑止表示（長会話/TX後=常時ON、バースト=1Hz点滅、解除=OFF）。
- D7→D2 ミラー（反転：再生中HIGH/停止中LOW）。
- 周期ID（30分/002-003交互）、D3テストSW（1/2/3クリック）。

### Notes
- `LONG_TALK_MS` は `BUSY_MAX_MS` とペアリング推奨（既定 2500ms）。
- A0運用でdurが伸びやすい環境では `A0_HOLD_MS=600ms` へ短縮が有効。

## [1.69c] - 2026-01-09
### Changed
- D13ステータスLEDの表示対象に **TX後抑止（3秒）** を追加。
  - 優先度: **長会話抑止 > TX後抑止 > バースト抑止 > 解除**。
  - 長会話/TX後：**常時ON**、バースト：**1Hz点滅**、解除：**OFF**。
### Maintained
- 統合BUSY（D6||A0）によるID判定、イベントのみログ＋Δt、STOP/uptime、TX後3秒抑止の機能自体、文脈抑止、周期ID（30分/002-003交互）を継続。
- A0busy/D12ログはDEBUG時のみ、A0ログ安定化（200ms/500ms）。

## [1.69b] - 2026-01-09
### Added
- D13 を抑止ステータス LED に割り当て（長会話抑止=常時ON、バースト抑止=1Hz点滅、無抑止=OFF）。
### Changed
- `BUSY_MAX_MS=2500`、`LONG_TALK_MS=2500` に拡張/ペアリング。
### Maintained
- 統合BUSY（D6||A0）での ID 判定、イベントのみログ、Δt、STOP/uptime、TX後3秒抑止、文脈抑止、周期ID。A0busy/D12ログはDEBUG＋安定化。

### Changed
- **短受信（CHUNK）上限**を `BUSY_MAX_MS = 2500` に拡張（車由来のCHUNKの取りこぼし低減）。
- **長会話抑止の閾値**を `LONG_TALK_MS = 2500` に **ペアリング**（短受信と長会話の境界整合）。

### Maintained
- **統合BUSY（D6||A0）**でのLED表示と **ID判定**（v1.68j準拠）。
- **イベントのみログ**、**Δt併記**、**STOP(`x`) で uptime 表示**、**TX後3秒抑止**、**文脈抑止**（長会話/バースト）。
- **周期ID**（v1.67e準拠：30分おき、002/003交互、IDLE時のみ）。
- **A0busy/D12ログ**は **DEBUG時のみ**出力＋**安定化**（200ms/500ms）。

### Known Issues
- バースト抑止（10s窓・2回で抑止）は混雑・車通過頻度によって **IDが抑制される**場合あり。必要に応じて `CHUNK_BURST_THRESHOLD=3` や `CHUNK_BURST_SUPPRESS_MS=8000` へ **緩和**可能。

### Migration
- v1.69a2→v1.69b：**新しいパラメータ**のみ。
  - `BUSY_MAX_MS=2500`、`LONG_TALK_MS=2500` を設定。
  - D13 LEDは **内蔵LED (L)** が共用されるため、外付けLEDを使う場合は **330Ω**程度の抵抗を介して D13→LED→GND。

---

## [1.69a2] - 2026-01-09
### Fixed
- **自動IDが発火しない**問題へ対応：
  - **ID検出源**を **統合BUSY（D6||A0）** に **復旧**（v1.68j準拠）。
  - `idOK` から **A0静音必須**のゲート（`ID_REQUIRE_A0_QUIET`）を **撤廃**。A0が揺れていても、他条件が成立すれば ID=OK。

### Changed
- **PTTタイミング**を **安全側**へ（`PTT_PRE_MS=1000` / `PTT_POST_MS=1000`）。DFPlayerの BUSY 検出と相性を高め、確実な ON/OFF を担保。

### Maintained
- **イベントのみログ**、**Δt併記**、**STOP/uptime**、**TX後3秒抑止**、**文脈抑止**、**周期ID（v1.67e準拠）**。

### Known Issues
- **A0ログはDEBUG限定**のため、通常運用（INFO）では A0の挙動の詳細が出ません。解析時は **`3`** を送って DEBUG に切り替え。

### Migration
- v1.69a→v1.69a2：**設定変更不要**。ただし v1.69a の `A0静音必須` で運用していた場合は、挙動が **緩和**される点に留意。

---

## [1.69a] - 2026-01-09
### Changed
- **A0busy/D12ログ**を **DEBUG 限定**化。運用時のログスパム（2～4ms間隔など）を抑制。
- **A0ログ安定化**：`A0_EDGE_STABLE_MS=200ms`、`A0_LOG_MIN_INTERVAL_MS=500ms` に強化。

### Maintained
- **ID判定**は **D6限定**（A0はLED/テレメトリ専用）。
- **A0静音必須**（`ID_REQUIRE_A0_QUIET=1`）は **継続**（※環境により IDが発火しない主因になりうる）。
- **イベントのみログ**、**Δt併記**、**STOP/uptime**、**TX後3秒抑止**、**文脈抑止**、**周期ID**（v1.67e準拠）。

### Known Issues
- A0が常時ON寄り（HOLD/閾値）だと **idOKが常にfalse** となり **自動IDが出ない**場合あり（→ v1.69a2で解消）。

### Migration
- v1.69→v1.69a：**設定変更不要**。ログの出方が **静音化**される点のみ意識。

---

## [1.69] - 2026-01-09
### Added
- **周期IDロジック**を **v1.67e準拠**で **復旧**：
  - 起動時に `nextPeriodicAt = millis() + PERIOD_MS`（絶対スケジュール）。
  - `now - nextPeriodicAt >= 0` で期限到来→ `nextPeriodicAt += PERIOD_MS`。
  - **IDLE時のみ**消化、**002/003交互**。ログ：`[Periodic] due -> flag set` / `played -> toggle next`。
- **シリアルコマンド `'b'`**：**短BUSY由来の自動IDのみ**抑止/許可のトグル（周期ID/テストSWには非適用）。

### Changed
- **ID判定**を **D6のみ**に限定（A0はLED/テレメトリ専用）。
- **A0安定化**（ヒステリシス＋HOLD、ログ安定化）を導入。

### Fixed
- **TX終了後3秒間**のD6無視（誤トリガ防止）を維持（v1.67e継承）。

### Maintained
- **イベントのみログ**、**Δt併記**、**STOP/uptime**、**文脈抑止**（長会話/バースト）。

### Known Issues
- 環境によっては **A0静音必須**が自動IDの発火を阻害（→ v1.69a2で撤廃）。

### Migration
- v1.68j→v1.69：
  - **ID検出源**（v1.68jの D6||A0）→ **D6限定**へ変更。必要なら後続リリース（v1.69a2）で **復旧**。
  - 周期ID（30分/002↔003交互）を **再導入**。無効化したい場合は、条件に `&& false` を追加する等のビルド時対応が必要。

---

## [1.68j-final] - 2026-01-08
### Added
- **イベントのみログ**を徹底。**Δt**（前回同種イベントからの経過時間）併記。
- **STOP(`x`)**で **uptime** を出力、以降はログ抑制（制御は継続）。

### Changed
- **統合BUSY = D6 || A0busy** による受信判定（LED・ID判定）。
- **D6の平常表示**（常時ポーリングログ）を **廃止**（イベントのみへ）。

### Maintained
- 文脈抑止、PTT統一制御、DFPlayer BUSYミラー、テストSWのクリック判定。

### Known Issues
- A0が閾値付近で揺れる環境では **ログ量が多くなる**（→ v1.69系で DEBUG限定＋安定化）。

### Migration
- v1.68i+→v1.68j：**設定変更不要**。ログが **イベントのみ**に統一。

---

## [1.68i+] - 2026-01-xx
### Added
- **D12/D5 の出力エッジ**は **常に表示（unconditional）**。`setPtt()` を導入して PTTログの一元化。

### Changed
- テレメトリの出力項目を強化（A0raw/D12/ID_OK、`c` コマンドで内訳表示）。

### Maintained
- 文脈抑止（長会話/バースト）、A0 front-end（ヒステリシス＋HOLD）。

---

## [1.68i] - 2026-01-xx
### Added
- **静音モニタ**運用（無イベント時は出力なし）。**EVENTのみ出力**の方針を導入。

### Maintained
- v1.68h+までの見える化・テレメトリ強化を踏襲。

---

## [1.68h+] - 2026-01-xx
### Added
- **テレメトリ強化**（A0raw/D12/ID_OK、`c` コマンドで内訳表示）。

### Changed
- ログレベル／v/s/d/h の **見える化**。

---

## [1.68h] - 2026-01-xx
### Added
- ログレベル、テレメトリ、`v/s/d/h` の **見える化**。

### Maintained
- 文脈抑止（長会話/バースト）、A0 front-end。

---

## [1.68g] - 2026-01-xx
### Added
- **文脈抑止**を導入：
  - **長会話抑止**：受信継続が閾値以上（当初は1500ms）→ その後 **10秒** ID抑止。
  - **バースト抑止**：短受信（500..1500ms）が **10秒窓に2回以上** → その後 **10秒** ID抑止。

---

## [1.68b] - 2026-01-xx
### Added
- **D12 LED** を **A0 busy表示**に連動。

---

## [1.68a] - 2026-01-xx
### Added
- **A0 OR統合**（D6 + A0）を導入。A0は **HOLD** で途切れ吸収（既定 800ms）。

### Maintained
- 短受信判定（500..1500ms）、PTT統一制御、DFPlayer BUSYミラー、テストSW。

---

## [1.67e] - 2025-12-xx
### Added
- **TX終了後3秒**の D6無視（誤トリガ防止）。

### Maintained
- **周期ID**（30分おき、002/003交互、IDLE時のみ）。
- **短受信判定**（500..1500ms）、**直前アイドル**（≥200ms）、**不応期**（≥3000ms）。

### Migration
- v1.67c→v1.67e：**設定変更不要**。安全側ガードの強化のみ。

---

## [1.67c] - 2025-12-xx
### Initial
- **基本機能確立**：
  - **短受信（500..1500ms）**検出で **001.mp3** を送出。
  - **PTT先行/後保持**（初期値：`PTT_PRE_MS=700` / `PTT_POST_MS=500`）。
  - **DFPlayer BUSY**（D7=LOW=再生中）を **D2へ反転ミラー**。
  - **テストSW（D3）**：1/2/3クリック → 001/002/003 再生（1秒窓）。
  - **周期ID**（30分おき、**002/003交互**）を **IDLE時のみ消化**。
  - **不応期**（3000ms）、**直前アイドル**（≥200ms）。

---

## 付録 A：主要パラメータ一覧（v1.69b 時点）
```cpp
// 受信判定
const unsigned long BUSY_MIN_MS = 500;
const unsigned long BUSY_MAX_MS = 2500;  // 1.69b
const unsigned long TM_BUSY_DEBOUNCE_MS = 5;

// 文脈抑止
const unsigned long LONG_TALK_MS          = 2500;  // 1.69b
const unsigned long LONG_TALK_SUPPRESS_MS = 10000;
const unsigned long CHUNK_BURST_WINDOW_MS = 10000;
const unsigned int  CHUNK_BURST_THRESHOLD = 2;     // ※混雑時は3へ
const unsigned long CHUNK_BURST_SUPPRESS_MS=10000; // ※緩和時は8sなど

// 誤トリガ抑止
const unsigned long IDLE_MIN_MS       = 200;
const unsigned long REFRACTORY_MS     = 3000;
const unsigned long BUSY_SUPPRESS_AFTER_TX_MS = 3000;

// PTTタイミング（安全側）
const unsigned long PTT_PRE_MS  = 1000;
const unsigned long PTT_POST_MS = 1000;

// 周期ID
const unsigned long PERIOD_MS   = 30UL * 60UL * 1000UL; // 30分
```

## 付録 B：ピンマップ（Arduino Nano）
- D2：DFPlayer BUSY ミラー（反転：再生中HIGH/停止中LOW）
- D3：テストSW（INPUT_PULLUP、1秒窓のクリック数で 001/002/003）
- D4：統合BUSY LED（D6||A0）
- D5：PTT出力（HIGHで送信。無線機側がGNDショート型ならトランジスタ/フォトカプラで駆動）
- D6：TM BUSY（極性可変：`TM_BUSY_ACTIVE_HIGH`）
- D7：DFPlayer BUSY（LOW=再生中）
- D10/D11：SoftwareSerial（TX/RX）
- D12：A0 LED（A0busyの見える化）
- **D13**：抑止ステータスLED（**1.69b**で追加）
- A0：NJM2072 等の前段出力（ヒステリシス＋HOLDで安定化）

## 付録 C：運用ヒント
- **DEBUG**へ切替（シリアルで `3`）すると、A0/D12/DFP の詳細ログが得られます。
- 周期IDを一時停止したい場合は、`periodicDue && state == IDLE` の条件に `&& false` を加える等、**ビルド時**に明示的に無効化してください（既定では常時有効）。
- 受信の取りこぼしや連発抑止の度合いは、`BUSY_MAX_MS` / `LONG_TALK_MS` / `CHUNK_BURST_*` / `IDLE_MIN_MS` / `REFRACTORY_MS` の **組み合わせ**で調整できます。

---

**最終更新**：2026-01-09 (JST)

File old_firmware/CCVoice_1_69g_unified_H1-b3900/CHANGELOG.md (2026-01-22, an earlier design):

# CHANGELOG  
TM-8250 ID Guidance Controller  
Arduino Nano (ATmega328P, 5V)

本 CHANGELOG は v1.67c → v1.69g-unified-H1-b3900 までの全履

---

# [1.69g-unified-H1-b3900] - 2026-01-19
### Changed
- H1即復旧プリセットの上限を **3900ms** に最適化  
  - `BUSY_MAX_MS=3900`、`LONG_TALK_MS=3900` に既定化  
  - H1実環境（2.3〜3.9s カーチャンク）をフル許容
- 起動バナーを  
  `"[BOOT] 1.69g-unified-H1-b3900 (H1プリセット既定)"`  
  に変更
- `'H'` プリセットを `s0 / t0 / l0 / b3900` に統一

### Notes
- 既定：  
  - BUSY_INPUT_SOURCE=D6  
  - SUPPRESSORS=OFF（s0）  
  - TX_AFTER=OFF（t0）  
  - D4_BLINK=OFF（l0）  
  - BUSY_MIN_MS=500／BUSY_MAX_MS=3900／LONG_TALK_MS=3900  
- AUTO方式C、周期ID（30分 002/003）、DFPlayer制御などは 1.69g と同一  
- SFR/DMR中はアナログIDは乗らない（FMでテスト）  
- A0とD6は同時接続不可

---

# [1.69g-unified-H1] - 2026-01-19
### Fixed
- ビルド不能のシンタックスエラーを修正  
  - `Serial.println(...toggle next"]);` の余計な `]` を削除  
  - `formatUptime(...sizeof(up]);` の括弧不一致を修正

### Changed
- 起動バナーを **H1専用表記** に変更  
  - `[BOOT] 1.69g-unified-H1 (H1プリセット既定)`
- バージョン表記を更新（機能仕様は 1.69f-H1 と同一）

### Notes
- 既定：  
  - BUSY_INPUT_SOURCE=D6  
  - SUPPRESSORS=OFF  
  - TX_AFTER=OFF  
  - D4_BLINK=OFF  
  - BUSY_MAX_MS=3000  
  - LONG_TALK_MS=3000  
- 方式C（AUTO）は30分窓＋5分グレース  
- A0/D6 同時使用不可

---

# [1.69f-unified-H1] - 2026-01-18
### Added
- **H1即復旧プリセット**（s0 / t0 / l0 / b3000）を既定化  
- **AUTO方式C** を標準搭載  
  - 30分窓の D6エッジ数・A0イベント数で D6/A0 のどちらかへ自動固定  
  - 切替時 D13 を 2Hz で 3秒高速点滅

### Changed
- `b####` 設定時に `LONG_TALK_MS` を自動ペアリング  
- D4の上限超過点滅（l0/l1）を追加

### Notes
- BUSYソースは既定 D6  
- DMR/SFRはアナログIDが乗らない（FMでテスト必須）  
- A0/D6 同時配線不可

---

# [1.69f-unified] - 2026-01-09
### Goal
- v1.67c 互換の **ゼロデグレ既定**（D6のみ／抑止OFF）を維持  
- 新機能（抑止・A0・AUTO・D4点滅）はユーザーが明示 ON したときのみ動作

### Added
- シリアルコマンド：m0/m1/m2, s0/s1, t0/t1, l0/l1, b####  
- AUTO方式C（m2時のみ有効）

### Maintained
- 周期ID（30分 002/003）、D7→D2ミラー、テストSW（1/2/3クリック）

---

# [1.69e] - 2026-01-09
### Added
- AUTO方式C 初実装  
- D4 上限超過点滅（dur > BUSY_MAX_MS で点滅）

### Maintained
- 文脈抑止（長会話/バースト）、D13 表示、周期ID

---

# [1.69c] - 2026-01-09
### Added
- D13ステータスLEDに TX後抑止（3秒）も表示

### Changed
- LED優先順位：長会話 ＞ TX後 ＞ バースト ＞ OFF

---

# [1.69b] - 2026-01-09
### Added
- D13 を抑止ステータスLEDに割当

### Changed
- BUSY_MAX_MS=2500、LONG_TALK_MS=2500 に拡張

---

# [1.69a2] - 2026-01-09
### Fixed
- IDが発火しない問題を修正  
  - ID検出源を **D6||A0 に復旧**（v1.68j準拠）  
  - `A0静音必須` を撤廃

### Changed
- PTT_PRE_MS=1000 / POST_MS=1000 に安全側調整

---

# [1.69a] - 2026-01-09
### Changed
- A0ログを DEBUG 限定化  
- A0ログ安定化（200ms/500ms）

---

# [1.69] - 2026-01-09
### Added
- 周期ID（v1.67e準拠）を復旧  
- `b####` で短受信ID抑止を切替

### Changed
- ID判定を D6専用へ（A0はテレメトリのみ）

---

# [1.68j-final] - 2026-01-08
### Added
- 全ログをイベント化（Δt付き）
- STOP(x) で uptime 表示

### Changed
- 統合BUSY = D6 || A0

---

# [1.68a〜1.68i+]  - 2026-01-xx  
（A0 front-end・文脈抑止・テレメトリ強化 等を段階的に追加）

---

# [1.67e] - 2025-12-xx
### Added
- TX後3秒の D6無視（誤トリガ防止）

### Maintained
- 短受信判定（500..1500）、不応期（3s）、周期ID

---

# [1.67c] - 2025-12-xx
### Initial
- 初期実装（短BUSY→001、先行/後保持、テストSW、周期ID、DFPlayer制御）

---

# 最終更新：2026-01-19

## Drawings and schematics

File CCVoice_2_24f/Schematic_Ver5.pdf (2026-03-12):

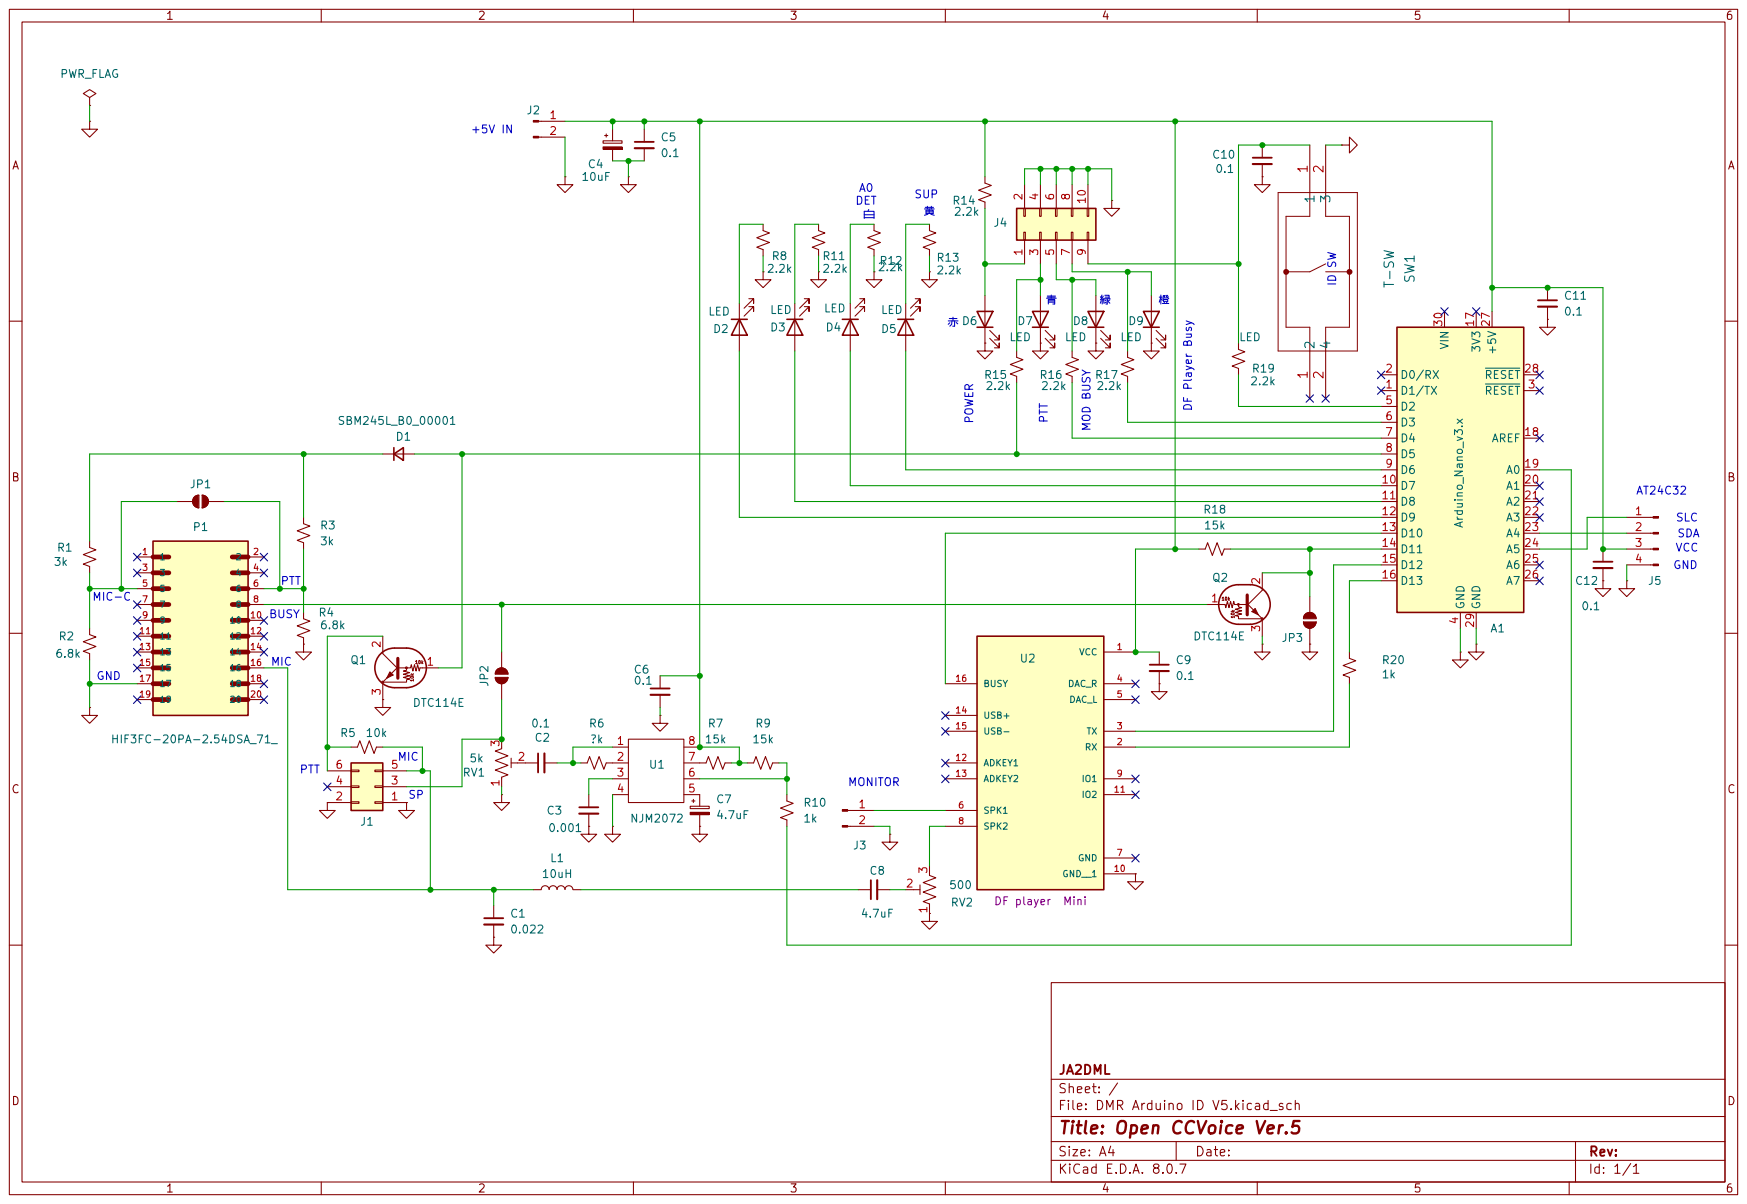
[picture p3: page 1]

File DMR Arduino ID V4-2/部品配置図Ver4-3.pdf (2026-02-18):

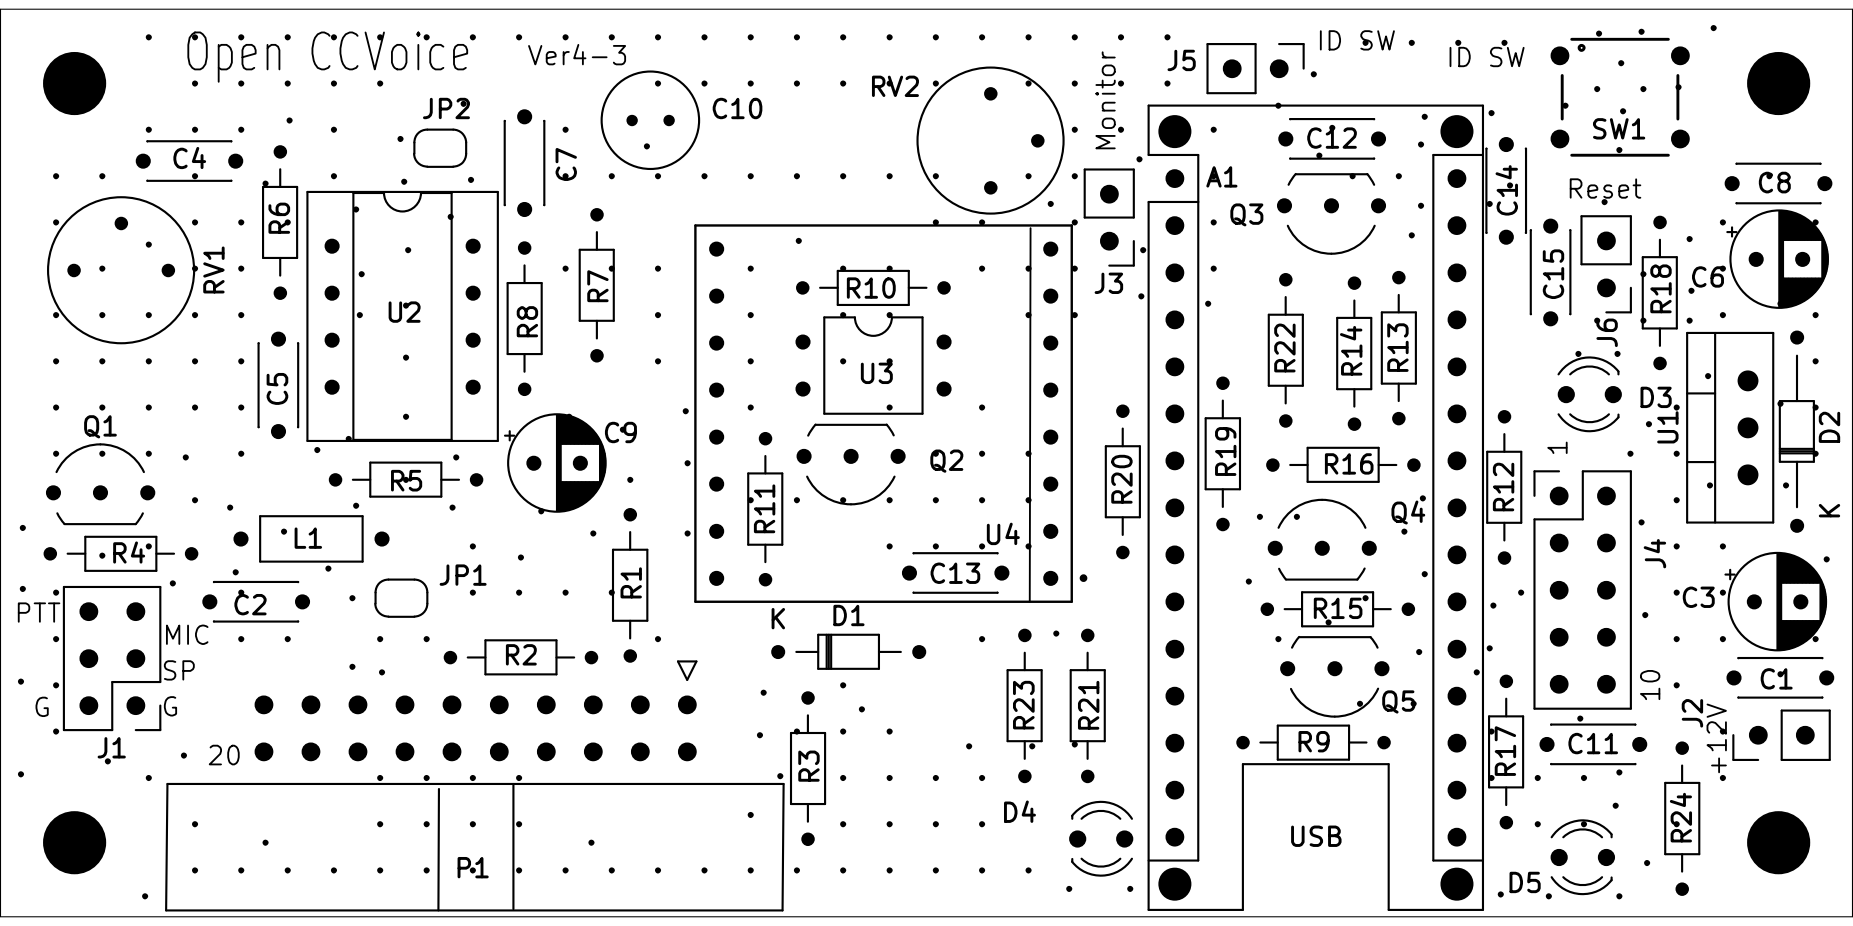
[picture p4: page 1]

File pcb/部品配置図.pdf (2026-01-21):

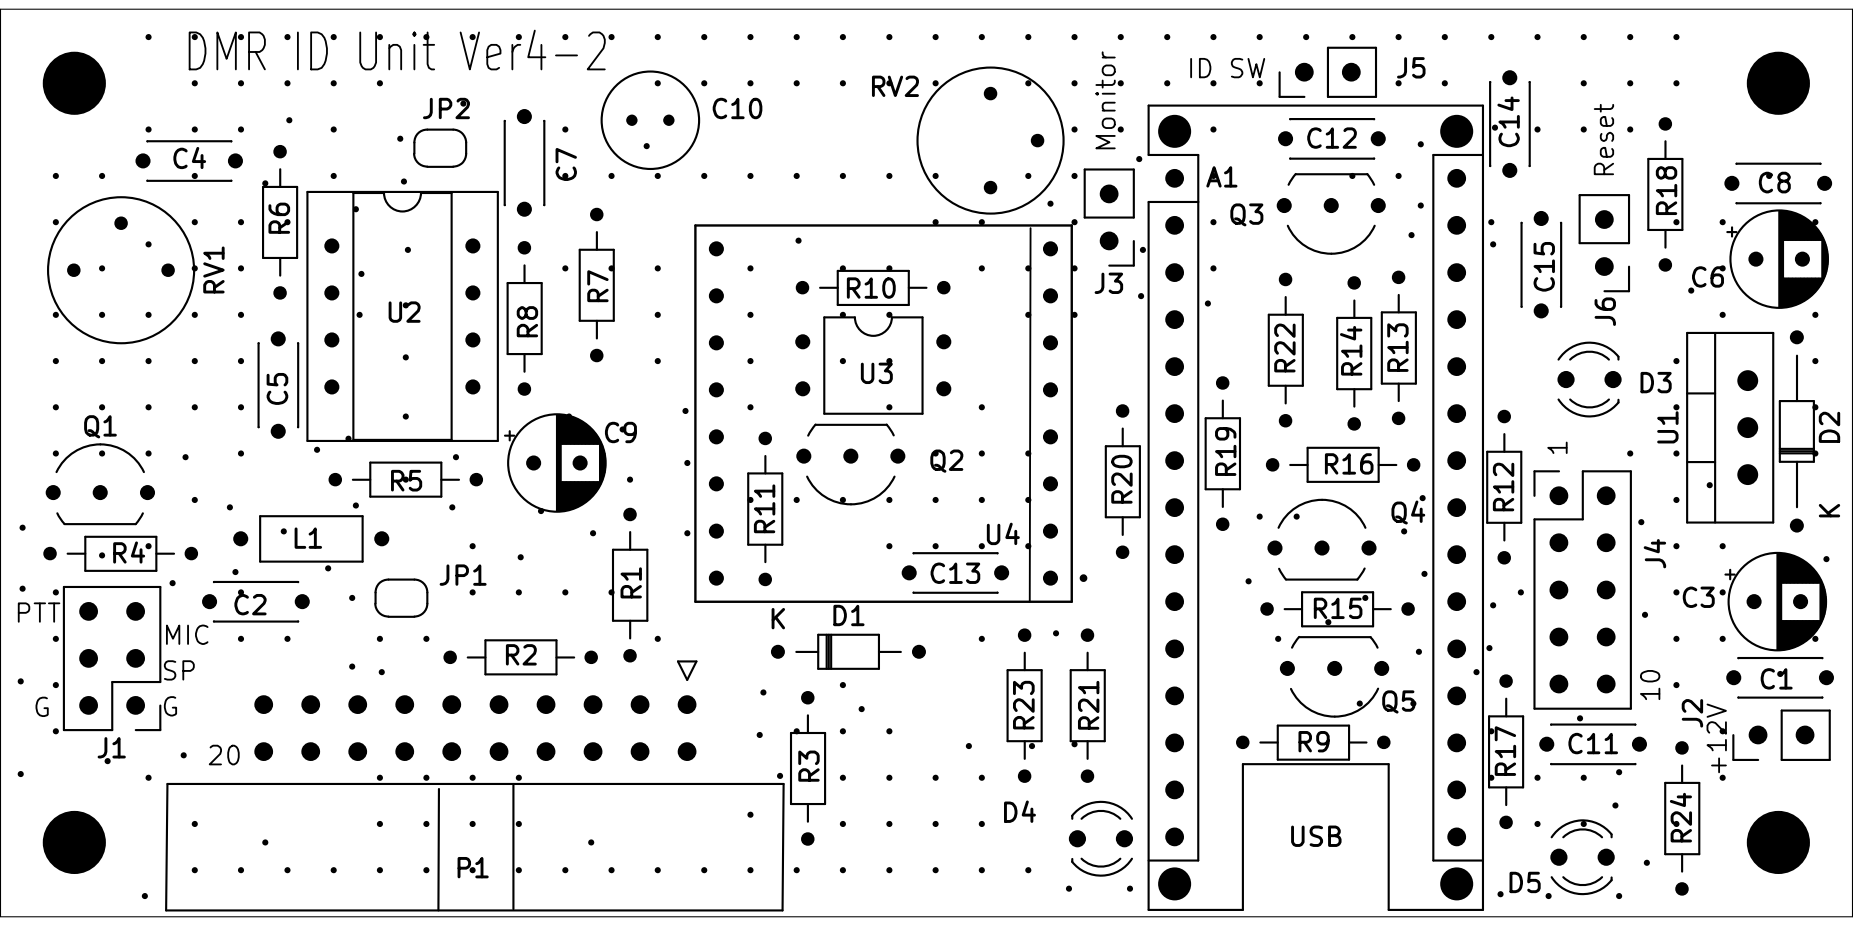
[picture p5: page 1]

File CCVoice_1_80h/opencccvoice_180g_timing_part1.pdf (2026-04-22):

BUSY ON | PTT ON | DFP再生 | 抑止(SUP)
PRE/POST | BUSY(無視)

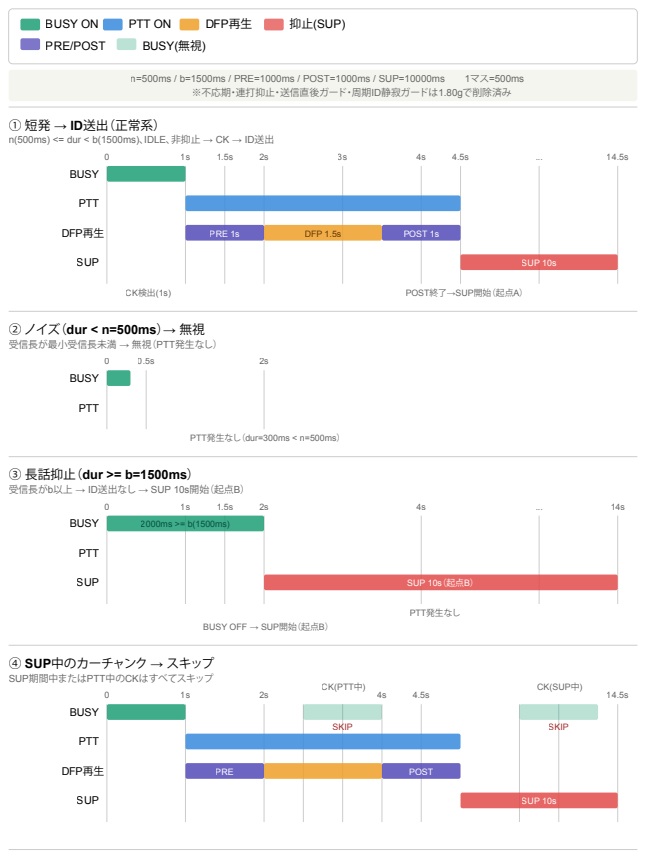
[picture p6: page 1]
BUSY; PTT; DFP再生; PRE 1s; DFP 1.5s; POST 1s; SUP; SUP 10s; CK検出(1s); POST終了→SUP開始（起点A）; PTT発生なし（dur=300ms < n=500ms）; SUP 10s（起点B）; PTT発生なし; ④ SUP中のカーチャンク → スキップ SUP期間中またはPTT中のCKはすべてスキップ; CK(PTT中); SKIP; CK(SUP中); PRE; POST

n=500ms / b=1500ms / PRE=1000ms / POST=1000ms / SUP=10000ms　　1マス=500ms

※不応期・連打抑止・送信直後ガード・周期ID静寂ガードは1.80gで削除済み

① 短発 → ID送出（正常系）
n(500ms) <= dur < b(1500ms)、IDLE、非抑止 → CK → ID送出

② ノイズ（dur < n=500ms）→ 無視
受信長が最小受信長未満 → 無視（PTT発生なし）

③ 長話抑止（dur >= b=1500ms）
受信長がb以上 → ID送出なし → SUP 10s開始（起点B）

BUSY OFF → SUP開始（起点B）

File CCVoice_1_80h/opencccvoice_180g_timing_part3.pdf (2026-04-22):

### ※不応期・連打抑止・送信直後ガード・周期ID静寂ガードは1.80gで削除済み

## ⑧ DFPタイムアウト（フェイルセーフ）

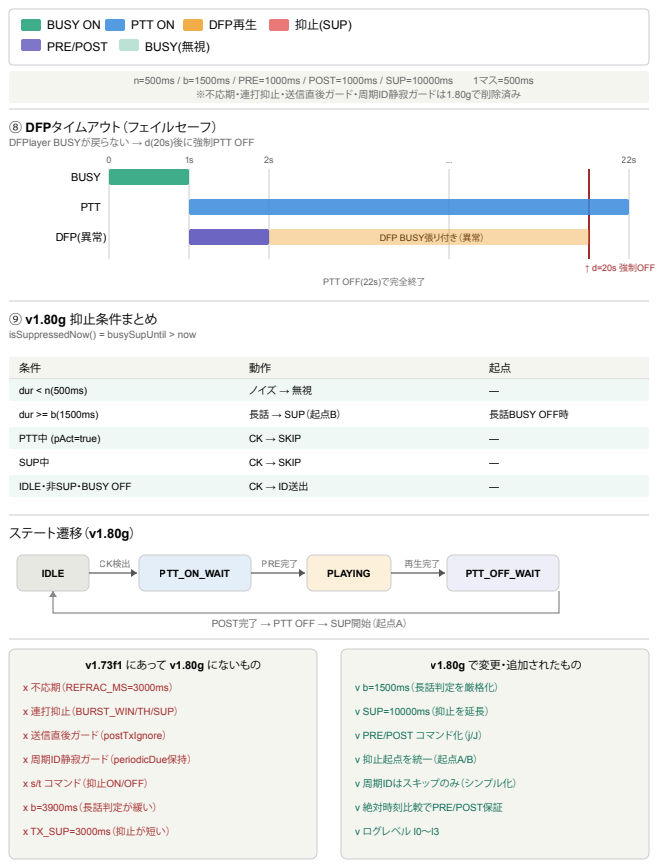
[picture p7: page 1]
BUSY ON; PTT ON; DFP再生; 抑止(SUP); PRE/POST; BUSY(無視); BUSY; PTT; DFP(異常); DFP BUSY張り付き（異常）; ↑ d=20s 強制OFF; dur < n(500ms); ノイズ → 無視; dur >= b(1500ms); 長話 → SUP（起点B）; 長話BUSY OFF時; PTT中 (pAct=true); CK → SKIP; SUP中; IDLE・非SUP・BUSY OFF; CK → ID送出; ステート遷移（v1.80g）; IDLE; PTT_ON_WAIT; PLAYING; PTT_OFF_WAIT; CK検出; PRE完了; 再生完了; v1.73f1 にあって v1.80g にないもの; v1.80g で変更・追加されたもの

n=500ms / b=1500ms / PRE=1000ms / POST=1000ms / SUP=10000ms　　1マス=500ms

DFPlayer BUSYが戻らない → d(20s)後に強制PTT OFF

PTT OFF(22s)で完全終了

⑨ v1.80g 抑止条件まとめ
isSuppressedNow() = busySupUntil > now

POST完了 → PTT OFF → SUP開始（起点A）

x 不応期（REFRAC_MS=3000ms）
x 連打抑止（BURST_WIN/TH/SUP）
x 送信直後ガード（postTxIgnore）
x 周期ID静寂ガード（periodicDue保持）
x s/t コマンド（抑止ON/OFF）
x b=3900ms（長話判定が緩い）
x TX_SUP=3000ms（抑止が短い）

v b=1500ms（長話判定を厳格化）
v SUP=10000ms（抑止を延長）
v PRE/POST コマンド化（j/J）
v 抑止起点を統一（起点A/B）
v 周期IDはスキップのみ（シンプル化）
v 絶対時刻比較でPRE/POST保証
v ログレベル l0～l3

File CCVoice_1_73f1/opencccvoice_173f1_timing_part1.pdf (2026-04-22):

BUSY ON | PTT ON | DFP再生 | 抑止(SUP)
PRE/POST | 不応期/postTx | BUSY(無視)

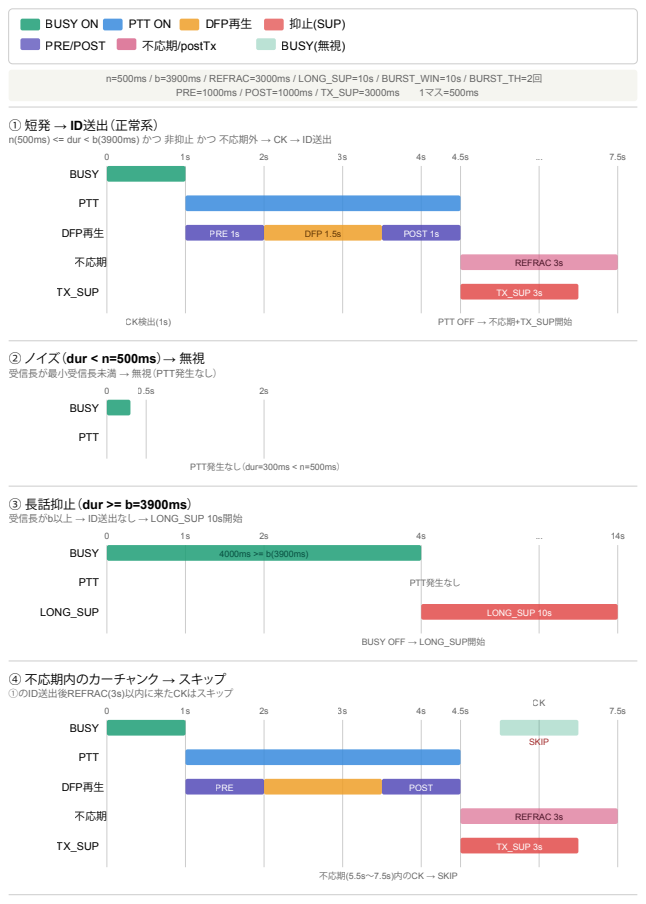
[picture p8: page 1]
n=500ms / b=3900ms / REFRAC=3000ms / LONG_SUP=10s / BURST_WIN=10s / BURST_TH=2回 PRE=1000ms / POST=1000ms / TX_SUP=3000ms 1マス=500ms; BUSY; PTT; DFP再生; PRE 1s; DFP 1.5s; POST 1s; 不応期; REFRAC 3s; TX_SUP; TX_SUP 3s; CK検出(1s); PTT OFF → 不応期+TX_SUP開始; PTT発生なし（dur=300ms < n=500ms）; ③ 長話抑止（dur >= b=3900ms） 受信長がb以上 → ID送出なし → LONG_SUP 10s開始; PTT発生なし; LONG_SUP; LONG_SUP 10s; BUSY OFF → LONG_SUP開始; ④ 不応期内のカーチャンク → スキップ ①のID送出後REFRAC(3s)以内に来たCKはスキップ; SKIP; PRE; POST

① 短発 → ID送出（正常系）
n(500ms) <= dur < b(3900ms) かつ 非抑止 かつ 不応期外 → CK → ID送出

② ノイズ（dur < n=500ms）→ 無視
受信長が最小受信長未満 → 無視（PTT発生なし）

不応期(5.5s～7.5s)内のCK → SKIP

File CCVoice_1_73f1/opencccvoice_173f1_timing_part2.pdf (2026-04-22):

## ⑤ 連打抑止（BURST）

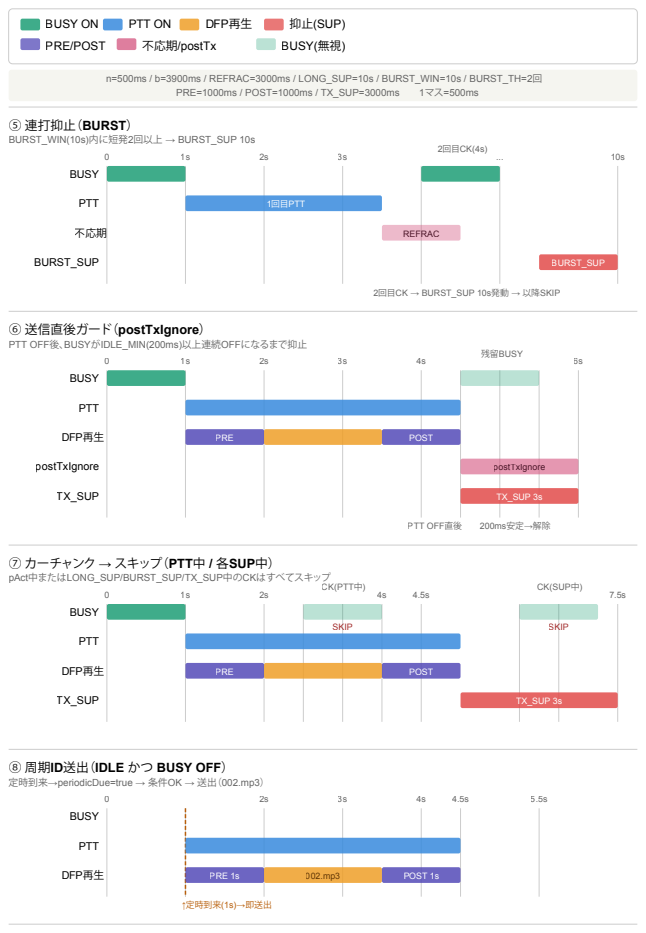
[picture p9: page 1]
BUSY ON; PTT ON; DFP再生; 抑止(SUP); PRE/POST; 不応期/postTx; BUSY(無視); n=500ms / b=3900ms / REFRAC=3000ms / LONG_SUP=10s / BURST_WIN=10s / BURST_TH=2回 PRE=1000ms / POST=1000ms / TX_SUP=3000ms 1マス=500ms; BURST_WIN(10s)内に短発2回以上 → BURST_SUP 10s; BUSY; 2回目CK(4s); PTT; 1回目PTT; 不応期; REFRAC; BURST_SUP; 2回目CK → BURST_SUP 10s発動 → 以降SKIP; 残留BUSY; PRE; POST; postTxIgnore; TX_SUP; TX_SUP 3s; CK(PTT中); SKIP; CK(SUP中); PRE 1s; POST 1s; ↑定時到来(1s)→即送出

⑥ 送信直後ガード（postTxIgnore）
PTT OFF後、BUSYがIDLE_MIN(200ms)以上連続OFFになるまで抑止

PTT OFF直後　　200ms安定→解除

⑦ カーチャンク → スキップ（PTT中 / 各SUP中）
pAct中またはLONG_SUP/BURST_SUP/TX_SUP中のCKはすべてスキップ

⑧ 周期ID送出（IDLE かつ BUSY OFF）
定時到来→periodicDue=true → 条件OK → 送出（002.mp3）

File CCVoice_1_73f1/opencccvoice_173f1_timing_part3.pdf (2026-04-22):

## ⑨ 周期ID静寂ガード（periodicDue保持）

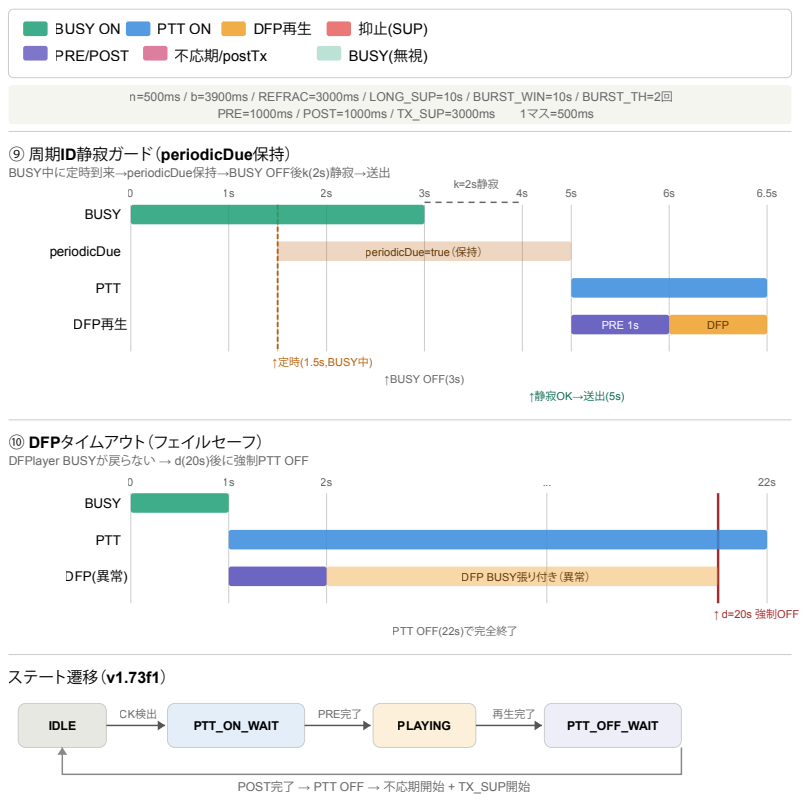
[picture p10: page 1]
BUSY ON; PTT ON; DFP再生; 抑止(SUP); PRE/POST; 不応期/postTx; BUSY(無視); n=500ms / b=3900ms / REFRAC=3000ms / LONG_SUP=10s / BURST_WIN=10s / BURST_TH=2回 PRE=1000ms / POST=1000ms / TX_SUP=3000ms 1マス=500ms; k=2s静寂; BUSY; periodicDue; periodicDue=true（保持）; PTT; PRE 1s; DFP; ↑定時(1.5s,BUSY中); ↑BUSY OFF(3s); ↑静寂OK→送出(5s); DFP(異常); DFP BUSY張り付き（異常）; ↑ d=20s 強制OFF; ステート遷移（v1.73f1）; IDLE; PTT_ON_WAIT; PLAYING; PTT_OFF_WAIT; CK検出; PRE完了; 再生完了

BUSY中に定時到来→periodicDue保持→BUSY OFF後k(2s)静寂→送出

⑩ DFPタイムアウト（フェイルセーフ）
DFPlayer BUSYが戻らない → d(20s)後に強制PTT OFF

PTT OFF(22s)で完全終了

POST完了 → PTT OFF → 不応期開始 + TX_SUP開始

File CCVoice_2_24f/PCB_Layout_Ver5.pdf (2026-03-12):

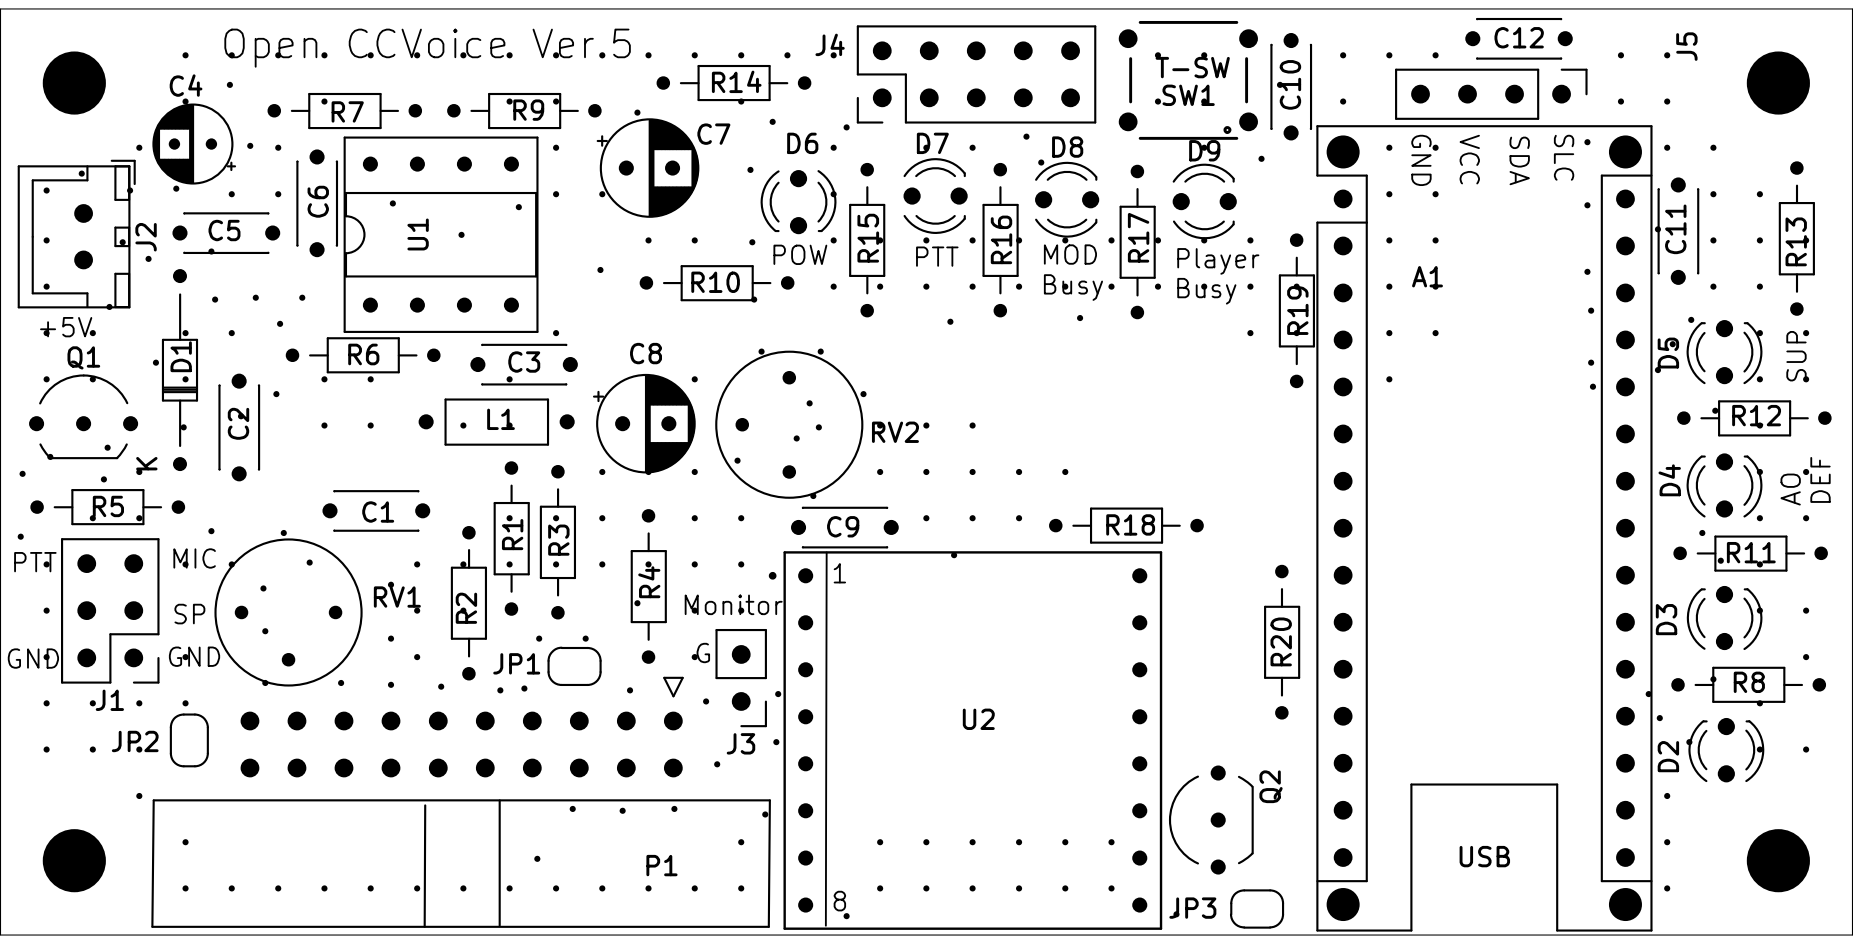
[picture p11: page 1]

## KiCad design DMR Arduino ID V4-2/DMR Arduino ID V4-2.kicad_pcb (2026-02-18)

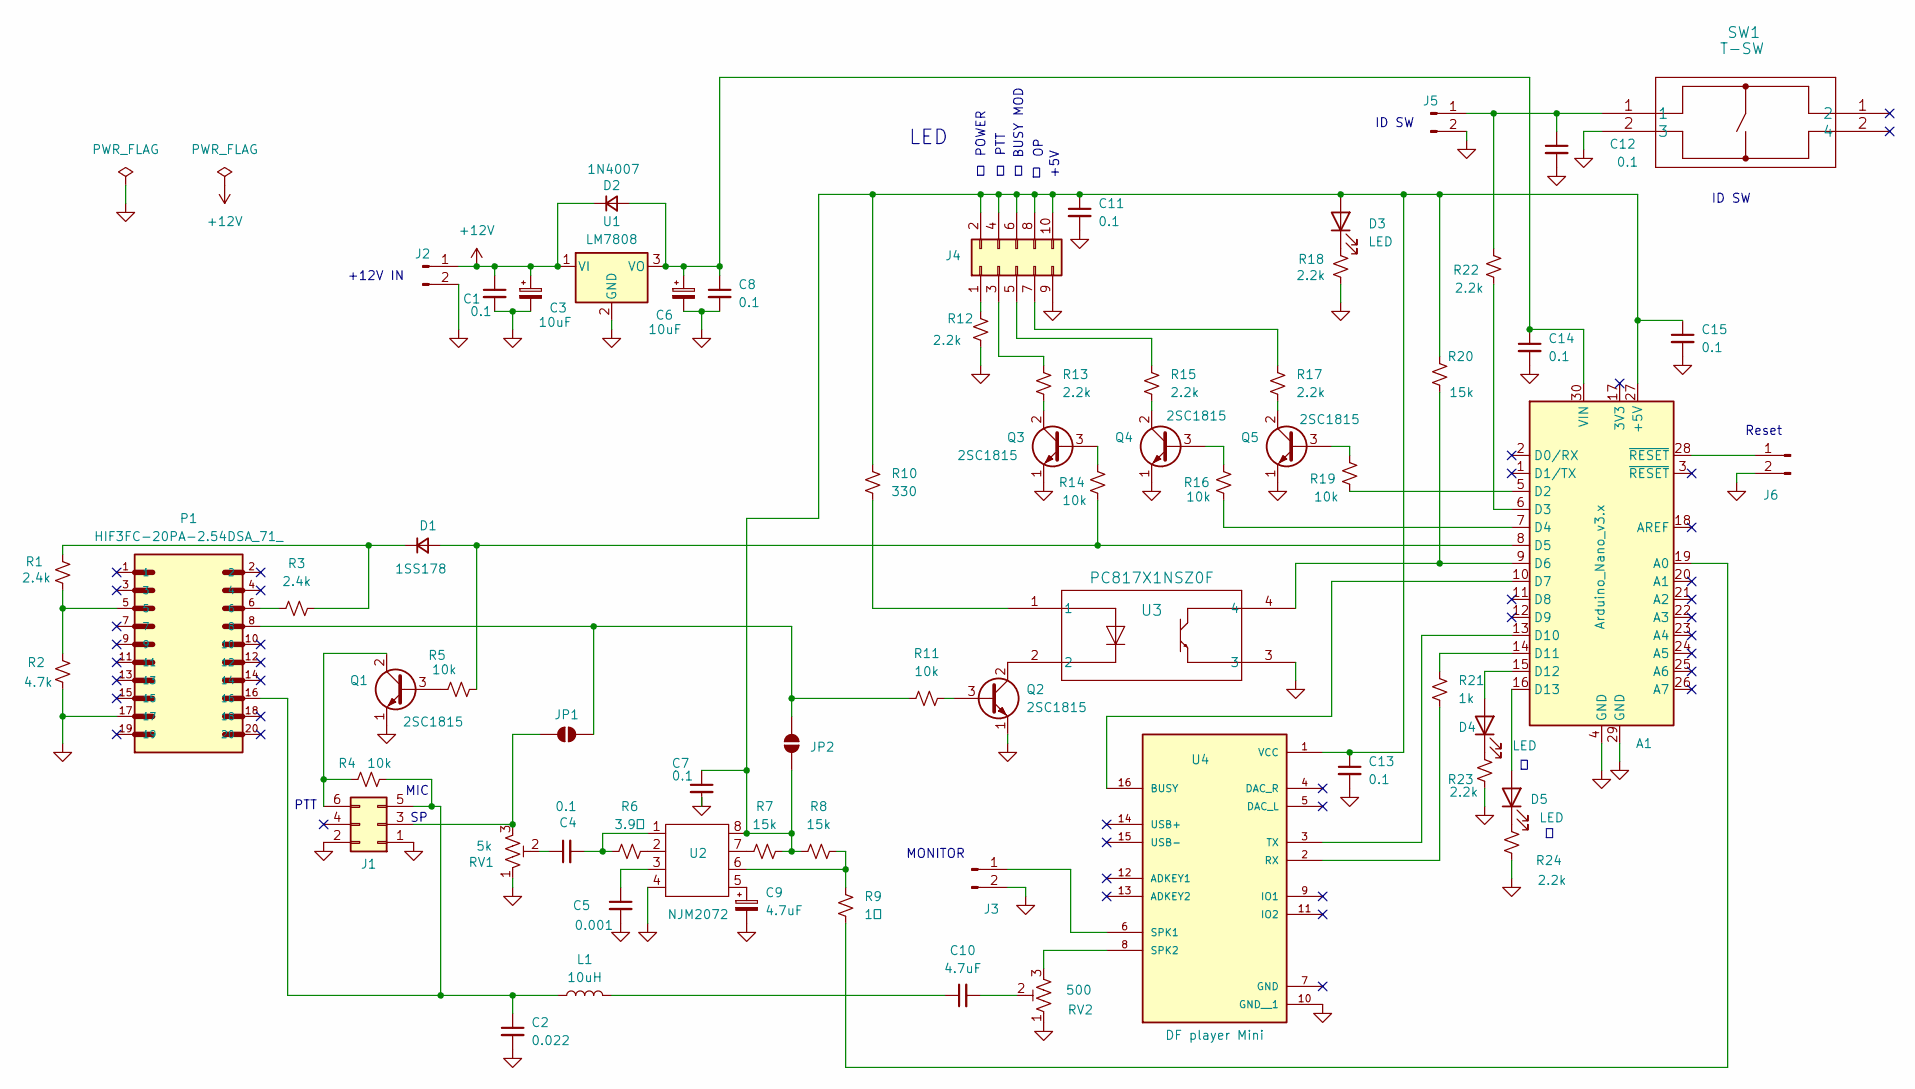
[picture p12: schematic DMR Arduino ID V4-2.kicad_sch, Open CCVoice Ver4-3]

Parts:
A1: Arduino_Nano_v3.x; Arduino_Nano_WithMountingHoles
C1, C4, C7, C8, C11, C12, C13, C14, C15: 0.1; C_Disc_D4.3mm_W1.9mm_P5.00mm
C2: 0.022; C_Disc_D4.3mm_W1.9mm_P5.00mm
C3, C6: 10uF; CP_Radial_D5.0mm_P2.50mm
C5: 0.001; C_Disc_D4.3mm_W1.9mm_P5.00mm
C9: 4.7uF; CP_Radial_D5.0mm_P2.50mm
C10: 4.7uF; C_Radial_D5.0mm_H5.0mm_P2.00mm
D1: 1SS178; D_DO-34_SOD68_P7.62mm_Horizontal
D2: 1N4007; D_DO-34_SOD68_P10.16mm_Horizontal
D3, D4, D5: LED; LED_D3.0mm_FlatTop
J1: Conn_02x03_Odd_Even; PinHeader_2x03_P2.54mm_Vertical
J2, J3, J5, J6: Conn_01x02_Pin; PinHeader_1x02_P2.54mm_Vertical
J4: Conn_02x05_Odd_Even; PinHeader_2x05_P2.54mm_Vertical
JP1, JP2: SolderJumper_2_Open; SolderJumper-2_P1.3mm_Open_RoundedPad1.0x1.5mm
L1: 10uH; L_Axial_L5.3mm_D2.2mm_P7.62mm_Horizontal_Vishay_IM-1
P1: HIF3FC-20PA-2.54DSA_71_; IDC-Header_2x10_P2.54mm_Horizontal
Q1, Q2, Q3, Q4, Q5: 2SC1815; TO-92L_Inline_Wide
R1, R3: 2.4k; R_Axial_DIN0204_L3.6mm_D1.6mm_P7.62mm_Horizontal
R2: 4.7k; R_Axial_DIN0204_L3.6mm_D1.6mm_P7.62mm_Horizontal
R4, R5, R11, R14, R16, R19: 10k; R_Axial_DIN0204_L3.6mm_D1.6mm_P7.62mm_Horizontal
R6: 3.9ｋ; R_Axial_DIN0204_L3.6mm_D1.6mm_P7.62mm_Horizontal
R7, R8, R20: 15k; R_Axial_DIN0204_L3.6mm_D1.6mm_P7.62mm_Horizontal
R9: 1ｋ; R_Axial_DIN0204_L3.6mm_D1.6mm_P7.62mm_Horizontal
R10: 330; R_Axial_DIN0204_L3.6mm_D1.6mm_P7.62mm_Horizontal
R12, R13, R15, R17, R18, R22, R23, R24: 2.2k; R_Axial_DIN0204_L3.6mm_D1.6mm_P7.62mm_Horizontal
R21: 1k; R_Axial_DIN0204_L3.6mm_D1.6mm_P7.62mm_Horizontal
RV1: 5k; Potentiometer_Bourns_3339P_Vertical
RV2: 500; Potentiometer_Bourns_3339P_Vertical
SW1: T-SW; B3F-1060
U1: LM7808; TO-220-3_Vertical
U2: NJM2072; CERDIP-8_W7.62mm_SideBrazed_Socket
U3: PC817X1NSZ0F; DIP-4_W7.62mm
U4: DFR0299; MODULE_DFR0299

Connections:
+12V: C1.1, C3.1, D2.1 (K), J2.1, U1.1 (VI)
GND: A1.4 (GND), A1.29 (GND), C1.2, C2.2, C3.2, C5.2, C6.2, C7.2, C8.2, C9.2, C11.2, C12.2, C13.2, C14.2, C15.2, J1.1, J1.2, J2.2, J3.2, J4.9, J5.2, J6.2, P1.17, Q1.1 (E), Q2.1 (E), Q3.1 (E), Q4.1 (E), Q5.1 (E), R2.2, R12.2, R18.2, R23.2, R24.2, RV1.1, RV2.1, SW1.2 (3), U1.2 (GND), U2.4, U3.3, U4.10 (GND__1)
unnamed: A1.27 (+5V), C7.1, C11.1, C13.1, C15.1, D3.2 (A), J4.2, J4.4, J4.6, J4.8, J4.10, JP2.1 (A), R7.2, R8.1, R10.1, R20.1, U2.8, U4.1 (VCC)
unnamed: A1.19 (A0), R9.2
unnamed: A1.5 (D2), R19.2
unnamed: A1.6 (D3), R22.2
unnamed: A1.7 (D4), R16.2
unnamed: A1.8 (D5), D1.2 (A), R5.2, R14.2
unnamed: A1.9 (D6), R20.2, U3.4
unnamed: A1.10 (D7), U4.16 (BUSY)
unnamed: A1.13 (D10), U4.3 (TX)
unnamed: A1.14 (D11), R21.1
unnamed: A1.15 (D12), D4.2 (A)
unnamed: A1.16 (D13), D5.2 (A)
unnamed: A1.30 (VIN), C6.1, C8.1, C14.1, D2.2 (A), U1.3 (VO)
unnamed: C4.1, RV1.2
unnamed: C4.2, R6.1, U2.1
unnamed: C5.1, U2.3
unnamed: C9.1, U2.5
unnamed: C10.1, L1.2
unnamed: C10.2, RV2.2
unnamed: D1.1 (K), R1.1, R3.1
unnamed: D3.1 (K), R18.1
unnamed: D4.1 (K), R23.1
unnamed: D5.1 (K), R24.1
unnamed: J1.3, JP1.1 (A), RV1.3
unnamed: C2.1, J1.5, L1.1, P1.16, R4.2
unnamed: J1.6, Q1.2 (C), R4.1
unnamed: J3.1, U4.6 (SPK1)
unnamed: J4.1, R12.1
unnamed: J4.3, R13.1
unnamed: J4.5, R15.1
unnamed: J4.7, R17.1
unnamed: C12.1, J5.1, R22.1, SW1.1
unnamed: A1.28 (~RESET), J6.1
unnamed: JP1.2 (B), JP2.2 (B), P1.8, R11.1
unnamed: P1.5, R1.2, R2.1
unnamed: P1.6, R3.2
unnamed: Q1.3 (B), R5.1
unnamed: Q2.3 (B), R11.2
unnamed: Q2.2 (C), U3.2
unnamed: Q3.3 (B), R14.1
unnamed: Q3.2 (C), R13.2
unnamed: Q4.3 (B), R16.1
unnamed: Q4.2 (C), R15.2
unnamed: Q5.3 (B), R19.1
unnamed: Q5.2 (C), R17.2
unnamed: R6.2, U2.2
unnamed: R7.1, U2.7
unnamed: R8.2, R9.1, U2.6
unnamed: R10.2, U3.1
unnamed: R21.2, U4.2 (RX)
unnamed: RV2.3, U4.8 (SPK2)

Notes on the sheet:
+12V IN
Reset
LED
+5V
BUSY MOD
MIC
MONITOR
ID SW
PTT
POWER

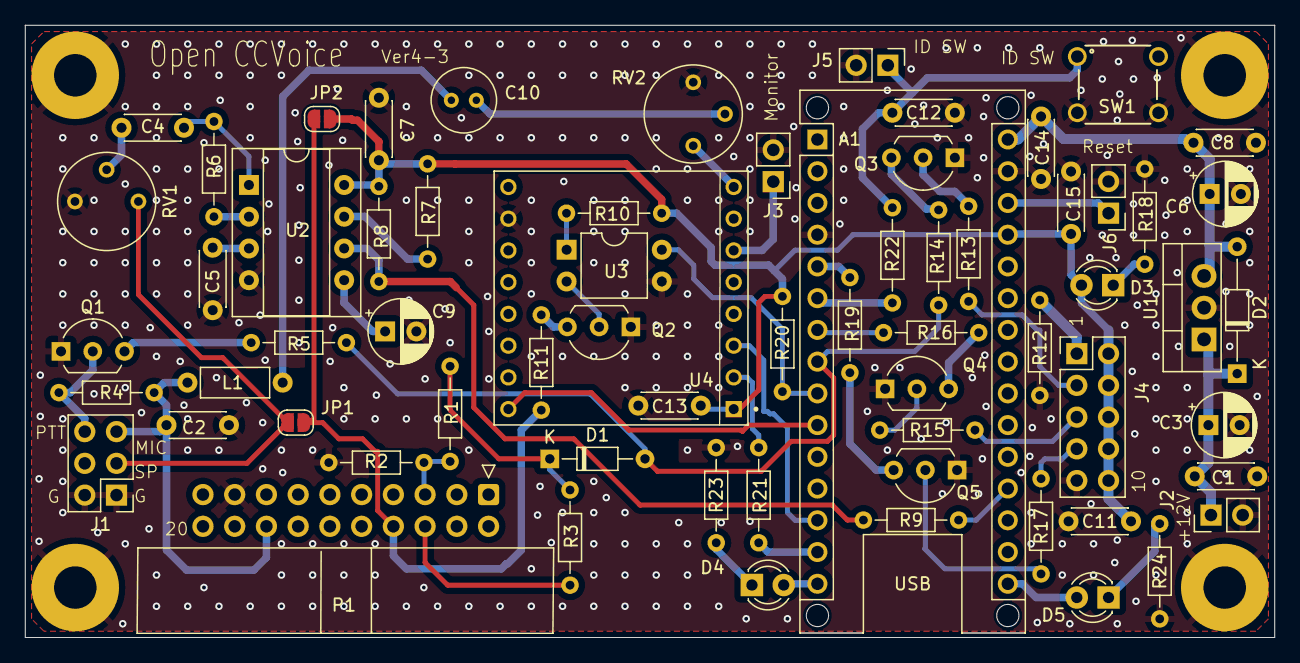
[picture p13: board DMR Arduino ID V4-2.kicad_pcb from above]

Board: 2 copper layers, 100.0 x 49.0 mm, 67 parts (0 on the bottom side), 53 nets.

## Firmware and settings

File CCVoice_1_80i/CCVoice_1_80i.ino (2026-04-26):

/************************************************************
 * OpenCCVoice Guidance Controller  (Unified / Safe)
 * Version : 1.80i
 * Target  : Arduino Nano (ATmega328P, 5V)
 *
 * ============================================================
 * 【概要】
 * ============================================================
 * DMR無線機のID送出を自動制御するコントローラ。
 * 受信検知（D6デジタル / A0アナログ / AUTO自動判定）に応じて
 * DFPlayerへ音声トラックを送出し、PTTを制御する。
 *
 * - 既存配線（DFPlayer: D10=Arduino RX / D11=Arduino TX）を維持
 * - 入力は INPUT_PULLUP（浮き対策）
 * - フェイルセーフ（DFPlayer応答なし）: d#### (ms), d0=無効
 * - BUSY極性切替: g0=LOW=busy / g1=HIGH=busy
 * - 周期ID: p##（分、0で停止）起算は起動時刻基準（v1.x系）
 * - 周期IDは「BUSYがOFFになってから k#### ms 静寂継続」の場合のみ送出
 *   BUSY中/静寂不足/抑止中はスキップ（破棄）
 * - AUTO判定（m2）でD6/A0を観測し優位側へ固定
 * - 抑止は ⑤busySupUntil で一元管理
 *   （カーチャンク後・通常会話終了・POST終了をすべて統合）
 * - PTTガード、BUSYデバウンスを実装
 * - EEPROMバージョン管理（config.ver）で自動移行/初期化
 *
 * ============================================================
 * 【仕様番号とコマンド対応】
 * ============================================================
 *  ① カーチャンク最小受信長   n####  (デフォルト: 500ms)
 *  ② カーチャンク最大受信長   b####  (デフォルト: 1500ms)
 *  ③ PTT先行無音時間(PRE)    j####  (デフォルト: 1000ms)
 *  ④ PTT後行無音時間(POST)   J####  (デフォルト: 1000ms)
 *  ⑤ 抑止時間               r####  (デフォルト: 10000ms)
 *  ⑥ 定周期間隔              p##    (デフォルト: 30分)
 *
 * ============================================================
 * 【バージョン履歴】
 * ============================================================
 * v1.80i 変更点（v1.80h → v1.80i）：
 *
 *   [バグ修正・コード整理]
 *   - カーチャンク検出時の busySupUntil 先行セットを削除
 *     旧実装では processBusyLogic() でのカーチャンク検出時と
 *     processStateMachine() の POST終了（起点A）の二か所で
 *     busySupUntil をセットしていた（二重セット）。
 *     抑止セットを起点A（POST終了時）に一本化し、設計意図を明確化。
 *   - migrateOrInit() の ver=4 以外からのマイグレーション時にも
 *     pttPreMs / pttPostMs を明示的に 1000ms で初期化するよう修正
 *     （ver=3 以前からの直接書き込み時の不定値リスクを排除）
 *   - handleStoppedState() 内のデッドコードを削除
 *     STOP中の R コマンド受付は handleSerialCmd() の case 'R': で
 *     完結しており、handleStoppedState() 内の Serial.read() は
 *     実質到達しないデッドコードだったため削除。
 *
 *   [コメント修正]
 *   - 概要コメント「抑止（長話/連打/送信後）を統合管理」を正確な表現に修正
 *   - processBusyLogic() 内「長話抑止（起点B）」を正確な表現に修正
 *   - pAct=true 時の② 超え受信も起点B になる旨をコメントに明記
 *   - handleSerialCmd() / setup() の内部開発版番号（v1.80d/e）を v1.80h に修正
 *
 *   [EEPROM]
 *   - CONFIG_VERSION は 5 のまま変更なし
 *     （EEPROM 構造体フィールドの変更なし）
 *
 * v1.80h 変更点（v1.73f1 → v1.80h）：
 *
 *   [仕様変更]
 *   - カーチャンク判定: ① MIN(n) 以上 ② MAX(b) 未満に統一
 *   - ② MAX デフォルト: 3900ms → 1500ms（通常会話との境界を明確化）
 *   - ⑤ 抑止時間(r) デフォルト: 3000ms → 10000ms
 *   - ③ PTT先行無音時間(PRE) をコマンド j#### で可変化（EEPROM保存）
 *   - ④ PTT後行無音時間(POST) をコマンド J#### で可変化（EEPROM保存）
 *   - 通常会話（② MAX 超え受信）終了後は受信終了起点で⑤抑止を開始
 *   - 定周期IDは受信中・抑止中・PTT中に到来したらスキップ（破棄）
 *     旧仕様の「延期（periodicDue保持）」から変更
 *
 *   [抑止ロジック刷新]
 *   - 連打抑止（BURSTロジック）を削除
 *     抑止は ⑤抑止（busySupUntil）のみで管理
 *   - ⑤抑止の起点を統一:
 *       起点A: ④POST終了の瞬間（受信中でない場合）
 *       起点B: ②超え受信の終了の瞬間（通常会話終了）
 *   - PTT送出中(pAct=true)も tmBusyStart を記録継続
 *
 *   [コマンド整理]
 *   - 追加: j####（③ PRE時間）/ J####（④ POST時間）
 *   - 削除: s0/s1（抑止全体ON/OFF）
 *   - 削除: t0/t1（送信後抑止ON/OFF）
 *   - 削除: i####（送信直後ガード閾値）
 *   - 削除: H（汎用プリセット）
 *   - 変更: STOP復帰コマンドを r → R（大文字）に変更
 *   - 変更: ログレベルコマンドを 0/1/2 → l0/l1/l2/l3 に変更
 *     （l3=DBG 新設。起動時は l1=MIN 固定、EEPROM保存なし）
 *
 *   [バグ修正]
 *   - Serial.setTimeout(50) を setup() で一度だけ設定するよう変更
 *     旧実装では parseInt() ブロッキング中に millis() が進み、
 *     PRE/POST 無音時間がスキップされる場合があった
 *   - PTT_ON_WAIT / PTT_OFF_WAIT の待機判定を相対時間比較から
 *     絶対時刻比較（pttPreEndAt / pttPostEndAt）に変更
 *     ブロッキングで now がずれても PRE/POST が確実に保証される
 *
 *   [ログ改善]
 *   - 抑止中カーチャンクのスキップログに残り時間を付記
 *     "skip(pAct)" / "skip(sup remain=####ms)" を LOG_MIN から表示
 *
 *   [EEPROM]
 *   - CONFIG_VERSION: 4 → 5
 *   - 追加フィールド: pttPreMs / pttPostMs
 *   - 削除フィールド: suppressOn / txAfSupOn / idleMin
 *   - ver=4（v1.73系）からの自動マイグレーション対応
 *
 * v1.73f1 変更点：
 *   - `v` コマンドを `V`（大文字）に変更（v2.x系との競合回避）
 *
 * v1.73f 変更点：
 *   - V コマンド追加、Z コマンド追加
 *   - loop() の処理を機能別関数に分割
 *
 * v1.73e 変更点：
 *   - 送信直後ガード（postTxIgnore）追加（v1.80h で削除・⑤抑止に統合）
 *   - 周期IDのcatch-up対策
 *   - A0 BUSY観測安定化
 *
 * ============================================================
 * 【操作（115200 8N1, 改行なし/LF）】
 * ============================================================
 *  n####      ① 最小受信長(ms)  デフォルト:500
 *  b####      ② 最大受信長(ms)  デフォルト:1500
 *  j####      ③ PTT PRE時間(ms) デフォルト:1000
 *  J####      ④ PTT POST時間(ms) デフォルト:1000
 *  r####      ⑤ 抑止時間(ms)    デフォルト:10000
 *  p##        ⑥ 定周期ID（分、0=停止）
 *  k####      定周期送出前の静寂待機時間(ms)
 *  m0/m1/m2   BUSYソース（D6/A0/AUTO）
 *  g0/g1      BUSY極性（LOW=busy / HIGH=busy）
 *  L###       A0閾値LOW
 *  G###       A0閾値HIGH
 *  a####      A0保持時間(ms)
 *  w##        AUTO観測時間（分）
 *  d####      DFPフェイルセーフ(ms、0=無効)
 *  V          バージョン表示（スケッチver + EEPROM_VER）
 *  q          設定一覧（全パラメータ表示）
 *  x          Safe Stop（全機能停止）
 *  R          Safe Stopからの復帰
 *  Z          ソフトウェアリセット（WDT、EEPROM変更なし）
 *  F          Factory Reset（EEPROM初期化＋保存）
 *  l0/l1/l2/l3  ログレベル（OFF/MIN/FULL/DBG）起動時はl1固定
 *  h          コマンド一覧
 *
 * ============================================================
 * 【リリース履歴】
 * ============================================================
 *  v1.80h  仕様刷新・抑止ロジック統合・PRE/POSTバグ修正
 *  v1.80i  コード整理・マイグレーション修正・デッドコード削除
 ************************************************************/

#include <Arduino.h>
#include <SoftwareSerial.h>
#include <EEPROM.h>
#include <avr/wdt.h>

/* ============================== EEPROM =============================== */
struct MyConfig {
  uint32_t magic;
  uint8_t  busySrc;
  uint32_t busyMin;
  uint32_t busyMax;
  uint32_t pttPreMs;
  uint32_t pttPostMs;
  uint32_t txSupMs;
  uint32_t periodMin;
  uint32_t periodQuietMs;
  int      a0Low;
  int      a0High;
  uint32_t a0Hold;
  uint32_t autoWinMin;
  uint32_t dfpTimeoutMs;
  uint8_t  tmBusyActiveHigh;
  uint8_t  ver;              // ★末尾固定
} config;

const uint32_t CONFIG_MAGIC   = 0xDEADBEEF;
const uint8_t  CONFIG_VERSION = 5;

/* =========================== Runtime Params =========================== */
enum BusySrc { BUSY_SRC_D6, BUSY_SRC_A0, BUSY_SRC_AUTO };
volatile BusySrc BUSY_INPUT_SOURCE;

unsigned long BUSY_MIN_MS;
unsigned long BUSY_MAX_MS;
unsigned long PTT_PRE_MS;
unsigned long PTT_POST_MS;
unsigned long TX_SUP_MS;
unsigned long PERIOD_MS;
unsigned long PERIOD_QUIET_MS;
int           A0_LOW_TH;
int           A0_HIGH_TH;
unsigned long A0_HOLD;
unsigned long AUTO_WINDOW;
unsigned long DFP_TIMEOUT_MS;
bool          TMBUSY_ACTIVE_HIGH;

/* ============================== Pins ================================== */
const bool DFP_BUSYOUT_INVERT = true;

const uint8_t PIN_TEST_SW  = 3;
const uint8_t PIN_BUSY_LED = 4;
const uint8_t PIN_PTT      = 5;
const uint8_t PIN_TM_BUSY  = 6;
const uint8_t PIN_DFP_BSY  = 7;
const uint8_t PIN_DFP_OUT  = 2;
const uint8_t PIN_SUP_LED  = 13;
const uint8_t PIN_A0_LED   = 12;
const uint8_t A0_PIN       = A0;

const uint8_t ARD_RX_FROM_DFP = 10;
const uint8_t ARD_TX_TO_DFP   = 11;
SoftwareSerial dfpSerial(ARD_RX_FROM_DFP, ARD_TX_TO_DFP);
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

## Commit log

2026-03-02 Create Arduino-IDE.html
    Arduino IDE導入方法
    2025/03/03 堀江作成
2026-05-13 Create DVSwitch × Pi-Star 自動音声応答システム構築手順書 (V1.44準拠)
2026-05-13 Update DVSwitch × Pi-Star 自動音声応答システム構築手順書 (V1.44準拠)
2026-05-13 Rename DVSwitch × Pi-Star 自動音声応答システム構築手順書 (V1.44準拠) to DVSwitch × Pi-Star 自動音声応答システム構築手順書 (V1.44準拠).md
2026-07-26 Update PCB Parts List with licensing details
    Added copyright and licensing information for OpenCCVoice project.

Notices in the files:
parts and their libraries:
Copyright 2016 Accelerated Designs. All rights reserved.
